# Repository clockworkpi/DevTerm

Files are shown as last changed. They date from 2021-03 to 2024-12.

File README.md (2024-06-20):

# DevTerm

## DevTerm OS Images

### A04
* http://dl.clockworkpi.com/DevTerm_A04_v0.2h.img.bz2 (32bit)  
md5sum acec1d02a37bfbffc9ed025fd718948e

### A06
* http://dl.clockworkpi.com/DevTerm_A06_v0.2h.img.bz2   
md5sum 26f52bfde573479960d8696f407d19b9  

### CM3
* http://dl.clockworkpi.com/DevTerm_CM3_v0.1a.img.bz2 (32bit)  
md5sum bef6c111863f8d2e6ef1cb23be354152  

### CM4
* http://dl.clockworkpi.com/DevTerm_CM4_v0.2b_64bit.img.7z    
md5sum 8b2fdebe254dfa1f5f245cebb85b1e84

* http://dl.clockworkpi.com/DevTerm_CM4_v0.1.img.bz2 (32bit)    
md5sum 7938ed1cdda98ba6f28049a819c12dc1  

* http://dl.clockworkpi.com/DevTerm_CM4_v0.3e_xfce_64bit.img.7z (based on [RPI-lite](https://downloads.raspberrypi.org/raspios_lite_armhf/images/raspios_lite_armhf-2023-05-03/2023-05-03-raspios-bullseye-armhf-lite.img.xz) with xfce)  
md5sum ab081eabf24ae501dc3f40a9126b7e5a  
 This version is optimized for immersive writing and comes pre-installed with [Obsidian](https://obsidian.md/).  

### R01
* http://dl.clockworkpi.com/DevTerm_R01_v0.2a.img.bz2   
md5sum 49aa472a6e4d81a48e0a1a26436f02c2

## Images mirror

* Community-driven download mirror: [http://dl.clockworkpi.io](http://dl.clockworkpi.io)

After downloading the files, you will need to extract or decompress them. Please keep in mind that MacOS 11.6 or a higher version is required to extract 7z files.  
  
To flash the OS image, you can use the following tools:  
  
- For Windows and macOS users, [Etcher](https://etcher.balena.io/) can be used to flash the image.  
- Linux users can employ the "dd" command to flash the image.  

To learn how to create an image, please refer to our [Wiki](https://github.com/clockworkpi/DevTerm/wiki).

## DevTerm Keyboard Firmware
DevTerm keyboard firmware flash program available. You can download it from this link: [DevTerm Keyboard Firmware Flash Program](https://github.com/clockworkpi/DevTerm/raw/main/Bin/devterm_keyboard_flash.tar.gz).

Here's how you can flash the firmware on DevTerm(A06 or CM4) or a PC running Ubuntu 22.04:

1. Download the devterm_keyboard_flash.tar.gz file.
2. Extract the contents of the archive: `tar zxvf devterm_keyboard_flash.tar.gz`.
3. Install the required package using the following command: `sudo apt install -y dfu-util`.
4. Navigate to the extracted directory: `cd devterm_keyboard_flash`.
5. Execute the flash script with root privileges: `sudo ./flash.sh`.
6. If everything goes well, you will see a progress bar indicating the flashing process.
7. If any issues occur or the keyboard loses control (which is unlikely), simply reboot DevTerm to resolve it.
8. Rest assured that this flash program will not brick your keyboard.

## Thermal Printer Testing Commands

* How to print "Hello World".  
`echo "hello world\n\n\n\n\n\n\n\n\n\n" > /tmp/DEVTERM_PRINTER_IN`

* How to print a self test page.  
`echo -en "\x12\x54" >  /tmp/DEVTERM_PRINTER_IN`

* How to print a text file.  
`curl -L https://github.com/clockworkpi/DevTerm/raw/main/README.md | tee >  /tmp/DEVTERM_PRINTER_IN`  

* [Learning more...](https://github.com/clockworkpi/DevTerm/tree/main/Code/thermal_printer)

## Assembly guidelines

* [Assembly guidelines](https://github.com/clockworkpi/DevTerm/blob/main/Clockwork_DevTerm_Assembly_Guidelines.pdf)  

## Schematic

* [DevTerm A06 core mainboard v3.14 schematic](https://github.com/clockworkpi/DevTerm/blob/main/Schematics/clockwork_DevTerm_A06_Core_for_Mainboard_V3.14_Schematic.pdf)
* [DevTerm R01 core mainboard v3.14 schematic](https://github.com/clockworkpi/DevTerm/blob/main/Schematics/clockwork_DevTerm_R01_Core_for_Mainboard_V3.14_Schematic.pdf)
* [Mainboard v3.14 schematic](https://github.com/clockworkpi/DevTerm/blob/main/Schematics/clockwork_Mainboard_V3.14_Schematic.pdf)
* [Mainboard v3.14-V5 schematic](https://github.com/clockworkpi/DevTerm/blob/main/Schematics/clockwork_Mainboard_V3.14_V5_Schematic.pdf)
* [DevTerm keyboard schematic](https://github.com/clockworkpi/DevTerm/blob/main/Schematics/clockwork_DevTerm_Keyboard_Schematic.pdf)
* [DevTerm keyboard trackball schematic](https://github.com/clockworkpi/DevTerm/blob/main/Schematics/clockwork_DevTerm_Keyboard_Trackball_Schematic.pdf)
* [DevTerm Ext schematic](https://github.com/clockworkpi/DevTerm/blob/main/Schematics/clockwork_DevTerm_Ext_Schematic.pdf)
* [DevTerm battery schematic](https://github.com/clockworkpi/DevTerm/blob/main/Schematics/clockwork_DevTerm_Battery_Schematic.pdf) 
* [CM4 adapter schematic](https://github.com/clockworkpi/DevTerm/blob/main/clockwork_Adapter_CM4_Schematic.pdf)
* [Learning more...](Schematics/)

## Gearbox 
### A04

Gearbox is a script tool used to adjust the A04 CPU frequency.  
you can get it by running 
```
sudo apt update 
sudo apt install -y devterm-gearbox-a04
```
you can run `devterm-a04-gearbox` to see the current core status.

```

Current Status:
+-----------------------------------+
|            Cortex-A53             |
+--------+--------+--------+--------+
| CPU 0  | CPU 1  | CPU 2  | CPU 3  |
+--------+--------+--------+--------+
|1320Mhz |1320Mhz |  OFF   |  OFF   |
+--------+--------+--------+--------+
CPU Governor: ondemand

```

Run `sudo devterm-a04-gearbox -s [GEAR]` to set gear, GEAR would be 1,2,3,4,5

There are 5 gears in gearbox

```
               1 for simple console tasks with long battery life.
               2 for simple writing tasks with long battery life.
               3 for most 2D games and emulators.
               4 for playing videos and 3D games,browsing websites.
               5 for performance-first tasks.
```

### A06 
Gearbox is a script tool used to adjust the big.LITTLE architecture of the A06 chip.  
you can get it by running 
```
sudo apt update 
sudo apt install -y devterm-gearbox-a06
```

In latest os image of A06, default Gearbox is set to use 4 LITTLE core with 816Mhz,GPU at 400Mhz

you can run `a06-gearbox` to see the current core status.

```
Current Status:
+-----------------------------------+-----------------+-----------+
|            Cortex-A53             |   Cortex-A72    | Mali-T860 |
+--------+--------+--------+--------+--------+--------+-----------+
| CPU 0  | CPU 1  | CPU 2  | CPU 3  | CPU 4  | CPU 5  |    GPU    |
+--------+--------+--------+--------+--------+--------+-----------+
| 816Mhz | 816Mhz | 816Mhz | 816Mhz |  OFF   |  OFF   |   400MHz  |
+--------+--------+--------+--------+--------+--------+-----------+
CPU Governor: schedutil    GPU Governor: simple_ondemand
```

Run `sudo a06-gearbox -s [GEAR]` to set gear,GEAR would be 1,2,3,4,5,6

There are 6 gears in gearbox

```
               1 for simple writing tasks with long battery life.
               2 for browsing most websites with long battery life.
               3 for most 2D games and emulators.
               4 for playing videos and 3D games.
               5 for performance-first tasks.
               6 for max performance, max power (usage).

```

## Community
Please visit our [Github Wiki](https://github.com/clockworkpi/DevTerm/wiki) and https://forum.clockworkpi.com for more information.

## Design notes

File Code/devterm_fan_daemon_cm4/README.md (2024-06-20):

# Fan control daemon for devterm cm4(rpi os)
 
## Install

**Devterm is pre-installed this package, so devterm cm4 users do not need to repeat the installation steps**

```
wget -O - https://raw.githubusercontent.com/clockworkpi/apt/main/debian/KEY.gpg | sudo apt-key add -
echo "deb https://raw.githubusercontent.com/clockworkpi/apt/main/debian/ stable main" | sudo tee -a /etc/apt/sources.list.d/clockworkpi.list

sudo apt update && apt install -y devterm-fan-temp-daemon-cm4
```

## Change the threshold temperature

Edit `/usr/local/bin/temp_fan_daemon.py`

line starts with `MAX_TEMP=80`

For devterm cm4(rpi os) the  recommended MAX_TEMP is in range 60-80 

then restart systemd service to take effect

`sudo systemctl restart devterm-fan-temp-daemon`

## How to control the fan from GPIO

``` start the fan
sudo gpio mode 17 out
sudo gpio write 17 1
```

```stop the fan
sudo gpio mode 17 out
sudo gpio write 17 0
```

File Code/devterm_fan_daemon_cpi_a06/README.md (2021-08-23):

# Fan control daemon for devterm A06()
 
## Install

**devterm is pre-installed this package, so devterm A06 users do not need to repeat the installation steps**

```
wget -O - https://raw.githubusercontent.com/clockworkpi/apt/main/debian/KEY.gpg | sudo apt-key add -
echo "deb https://raw.githubusercontent.com/clockworkpi/apt/main/debian/ stable main" | sudo tee -a /etc/apt/sources.list.d/clockworkpi.list

sudo apt update && apt install -y devterm-fan-daemon-cpi-a06
```

## Change the threshold temperature

Edit `/usr/local/bin/temp_fan_daemon_a06.py`

line starts with `MAX_TEMP=70000`

change the value of MAX_TEMP to be your target temperature value multiplied by 1000,eg 70000 for 70 degree,80000 for 80 degree  

for A06 recommended reference temperature range 70-80 

then restart systemd service to take effect

`sudo systemctl restart devterm-fan-temp-daemon-a06`

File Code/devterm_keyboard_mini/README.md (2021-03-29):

Arduino 1.8.13

http://dan.drown.org/stm32duino/package_STM32duino_index.json

STM32F1xx/GD32F1xx boards 
by stm32duino version 2021.2.22

  GENERIC STM32F103R series

  gd32f1_generic_boot20_pc13.bin
  generic_boot20_pc13.bin

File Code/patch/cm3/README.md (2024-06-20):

# How to compile devterm cm3 kernel

## Clone kernel source code 
```
git clone https://github.com/raspberrypi/linux.git  
cd linux
git checkout remotes/origin/rpi-4.19.y
```

## Get cross compile tools
```
git clone https://github.com/raspberrypi/tools.git
```

## Compiling process
```
#must use the rpi arm-bcm2708 cross compiler tools

cd linux
git apply devterm-4.19_v0.11.patch #get patch from https://github.com/clockworkpi/DevTerm/tree/main/Code/patch/cm3

export PATH=/data/github/raspberrypi/tools/arm-bcm2708/arm-linux-gnueabihf/bin/:$PATH ## change the arm-bcm2708 tools location for yourself

KERNEL=kernel7l make ARCH=arm CROSS_COMPILE=arm-linux-gnueabihf- bcm2709_defconfig
KERNEL=kernel7l make ARCH=arm CROSS_COMPILE=arm-linux-gnueabihf- -j3
INSTALL_MOD_PATH=./modules 
rm -rf $INSTALL_MOD_PATH
make modules_install

rm modules/lib/modules/*/build
rm modules/lib/modules/*/source

```

## /boot/config.txt

In config.txt,I renamed kernel7.img to devterm-kernel7.img

```
ignore_lcd=1
dtoverlay=vc4-kms-v3d,audio=0,cma-384
dtoverlay=devterm-pmu
dtoverlay=devterm-panel
dtoverlay=devterm-wifi
dtoverlay=devterm-bt
dtoverlay=devterm-misc
gpio=5=op,dh
gpio=9=op,dh
gpio=10=ip,np
gpio=11=op,dh

enable_uart=1
dtparam=spi=on
dtoverlay=spi-gpio35-39

dtparam=audio=on
kernel=devterm-kernel7.img
```

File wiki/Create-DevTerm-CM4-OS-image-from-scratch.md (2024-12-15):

## Intro
The image based on raspberry pi os  
for raspberry pi cm4 with devterm cm4 adapter  
and it is better to run a Ubuntu 21.04 in a VirtualBox to do all the jobs  
The entire operation requires a certain experience in linux  
be careful  

## Start a chroot env
```bash
wget https://downloads.raspberrypi.org/raspios_full_armhf/images/raspios_full_armhf-2021-05-28/2021-05-07-raspios-buster-armhf-full.zip

unzip 2021-05-07-raspios-buster-armhf-full.zip

sudo losetup --show -f -P 2021-05-07-raspios-buster-armhf-full.img #assume loop0
sudo mount /dev/loop0p2 /mnt/p2
sudo mount /dev/loop0p1 /mnt/p2/boot

cd /mnt/p2
sudo mount --bind /dev dev/
sudo mount --bind /sys sys/
sudo mount --bind /proc proc/
sudo mount --bind /dev/pts dev/pts
#sudo mv etc/ld.so.preload etc/ld_so_preload
sudo chroot .
```

## Inside chroot 
```bash
curl https://raw.githubusercontent.com/clockworkpi/apt/main/debian/KEY.gpg | sudo tee /etc/apt/trusted.gpg.d/clockworkpi.asc

echo "deb https://raw.githubusercontent.com/clockworkpi/apt/main/debian/ stable main" | sudo tee -a /etc/apt/sources.list.d/clockworkpi.list

sudo apt update && sudo apt install devterm-thermal-printer-cm4 devterm-fan-temp-daemon-cm4 devterm-kernel-cm4-rpi devterm-audio-patch devterm-wiringpi-cm4-cpi -y

sudo apt install -y devterm-thermal-printer-cups
```
**Config xrandr**
```
sudo bash -c 'cat << EOF > /etc/X11/Xsession.d/100custom_xrandr
xrandr --output DSI-1 --rotate right
EOF'
```
**config lightdm** 

`/etc/lightdm/lightdm.conf`

`greeter-setup-script=/etc/lightdm/setup.sh`
```
sudo bash -c 'cat <<EOF >/etc/lightdm/setup.sh
#!/bin/bash
xrandr --output DSI-1 --rotate right
exit 0
EOF'
```
`sudo chmod +x /etc/lightdm/setup.sh`

**Modify /etc/dphys-swapfile**
```
CONF_SWAPSIZE=512
```

**Change the default wallpaper**   
The following files changed 

* /etc/xdg/pcmanfm/LXDE-pi/desktop-items-0.conf 
* /etc/xdg/pcmanfm/LXDE-pi/desktop-items-1.conf 
* /etc/lightdm/pi-greeter.conf 
* /home/pi/.config/pcmanfm/LXDE-pi/desktop-items-0.conf 

Delete wallpaper address `temple.jpg`,change the `desktop_bg` color to `#202020`   
change `/etc/hostname` to clockworkpi  
in `/boot/cmdline.txt` ,add `fbcon=rotate:1`, remove `quiet` 

**Screen rotation**  
change 
```
/etc/skel/.config/monitors.xml 
/home/{pi,rpi-first-boot-wizard}/.config/monitors.xml 
```
to be like
```xml
<monitors version="2">
  <configuration>
    <logicalmonitor>
      <x>0</x>
      <y>0</y>
      <primary>yes</primary>
      <monitor>
        <monitorspec>
          <connector>DSI-1</connector>
          <vendor>unknown</vendor>
          <product>unknown</product>
          <serial>unknown</serial>
        </monitorspec>
        <mode>
          <width>480</width>
          <height>1280</height>
          <rate>60.000</rate>
        </mode>
      </monitor>
      <transform>
        <rotation>right</rotation>
      </transform>
    </logicalmonitor>
  </configuration>
</monitors>
```
for uConsole, replace **480 to 720** in above **monitors.xml**

### console rotation
/boot/cmdline.txt   add **fbcon=rotate:1** in the end of 
```
console=.........  fbcon=rotate:1

```

### Now quit the chroot env
```bash
exit
#sudo mv etc/ld_so_preload etc/ld.so.preload

sudo umount /mnt/p2/dev/pts
sudo umount /mnt/p2/dev
sudo umount /mnt/p2/proc
sudo umount /mnt/p2/sys
##clear bash 
sudo rm -rf root/.bash_history
#sudo rm usr/bin/qemu-arm-static

cd -
sudo umount /mnt/p2/boot
sudo umount /mnt/p2
sudo losetup -D /dev/loop0 #assume loop0
```

### Flash the image to SD card 
* Linux
`sudo dd if=2021-05-07-raspios-buster-armhf-full.img of=/dev/sdX bs=8M status=progress`

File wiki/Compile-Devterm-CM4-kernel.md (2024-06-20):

# System
ubuntu 22.04 gcc8.4.0
```
sudo apt install gcc-8 gcc-8-aarch64-linux-gnu gcc-8-arm-linux-gnueabihf
```

# Download patch
```
git clone https://github.com/clockworkpi/DevTerm.git
```

# Download kernel and patch it
```
git clone https://github.com/raspberrypi/linux
cd linux
git checkout 3a33f11c48572b9dd0fecac164b3990fc9234da8
cp ~/DevTerm/Code/patch/cm4/cm4_kernel_0704.patch .
git apply cm4_kernel_0704.patch

#Strongly recommend to use gcc 8.4.0 as the cross compiler
KERNEL=kernel7l make ARCH=arm CROSS_COMPILE=arm-linux-gnueabihf- bcm2711_defconfig
KERNEL=kernel7l make ARCH=arm CROSS_COMPILE=arm-linux-gnueabihf- -j1
INSTALL_MOD_PATH=./modules make modules_install
rm modules/lib/modules/*/build
rm modules/lib/modules/*/source

mkdir output
mkdir output/boot
mkdir output/lib/modules -p
mkdir output/boot/overlays

cp -rf modules/lib/modules/5.10.17-v7l+ output/lib/modules/
cp arch/arm/boot/dts/overlays/*.dtbo output/boot/overlays/
cp arch/arm/boot/dts/bcm2711-rpi-cm4.dtb output/boot/
cp arch/arm/boot/zImage output/boot/kernel7l.img

```

output is the folder contains all kernel stuff  

# config.txt
```
disable_overscan=1
dtparam=audio=on
[pi4]
dtoverlay=vc4-fkms-v3d
max_framebuffers=2

[all]
dtoverlay=dwc2,dr_mode=host
dtoverlay=vc4-kms-v3d-pi4,cma-384
dtoverlay=devterm-pmu
dtoverlay=devterm-panel
dtoverlay=devterm-misc
dtoverlay=audremap,pins_12_13

dtparam=spi=on
gpio=10=ip,np
```

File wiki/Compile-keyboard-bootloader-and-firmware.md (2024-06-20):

# Build bin

```
git clone https://github.com/rogerclarkmelbourne/STM32duino-bootloader

cd STM32duino-bootloader

make generic-pc13

```
this will produce `bootloader_only_binaries/generic_boot20_pc13.bin`  
## Convert bootloader to hex format
using `srec_cat` to convert   
windows: http://srecord.sourceforge.net/  
linux: sudo apt install srecord  

```
srec_cat bootloader_only_binaries/generic_boot20_pc13.bin -Binary -offset 0x08000000 -output bootloader_only_binaries/generic_boot20_pc13.hex -Intel
```

## Next is to use stm32Cube to flash the bootloader
* Download the stm32cube programmer  
   [stm32cube programmer](https://www.st.com/en/development-tools/stm32cubeprog.html)

* Put 1 ON in the back of keyboard
* Connect keyboard with a usb-serial convert by fpc, in order of [IO MAP](https://github.com/clockworkpi/DevTerm/wiki/Keyboard-with-FPC-60pin-0.5mm)
* Click connect on STM32cube programmer
* flash it





# Flash Arudino 
## Arduino IDE
* add stm32duino pacakage index in **Preference panel** : http://dan.drown.org/stm32duino/package_STM32duino_index.json as **Additional Boards Manager URLs:** and install STM32F1xx/GD32F1xx boards



* verbose all outputs:  


* Select upload method ,board type is **Generic STM32F103R series **  


* Set cpu mhz to 48Mhz  


* Put 1 OFF in the back of keyboard
* User arduino IDE to open [devterm_keyboard.ino](https://github.com/clockworkpi/DevTerm/blob/main/Code/devterm_keyboard/devterm_keyboard.ino)
* flash it 


# CN version  
https://shimo.im/docs/Tc8RVQWdjvXtwhYv/ 《GD32f103rgt6/CKSF103R* 与stm32duino bootloader》

custom keyboard:

https://forum.clockworkpi.com/t/keyboard-stuck-in-bootloader-mode/8830/11

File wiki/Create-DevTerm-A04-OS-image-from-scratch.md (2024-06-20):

**This wiki maybe outdated since armbian build system is always updating , so don't panic**

# Generate the prototype os image
```
cd ~
git clone https://github.com/armbian/build.git
git clone https://github.com/clockworkpi/DevTerm.git

cd build

git reset --hard 5fa022603c0948cc59688ba782b3711f980a0be3

cp -rf ~/DevTerm/Code/patch/armbian_build_a04/userpatches/* userpatches/
cp -rf ~/DevTerm/Code/patch/armbian_build_a04/config/boards/* config/boards/
cp -rf ~/DevTerm/Code/patch/armbian_build_a04/config/kernel/*  config/kernel/

#Then exec ./compile.sh under armbian build
cd ~/build && ./compile.sh 
```
after image done  
uncompress the  
`linux-dtb-current-sunxi64_21.11.0-trunk_arm64.deb`  
`linux-image-current-sunxi64_21.11.0-trunk_arm64.deb`  
 
and then combine all files ,all the postinst, preinst,prerm,postrm  
to be one `devterm-kernel-current-cpi-a04.deb`    
the reason is if not doing this , `apt-get upgrade` will replace the linux-dto,linux-image* in future, which will cause boot failed  
so to keep a04 linux kernel in safe , I made devterm-kernel-current-cpi-a04     

#  Prepare to chroot into the image 
```
sudo apt install -y qemu-user-static  
sudo losetup -f # find the avaiable loop device number,eg:loop11
sudo losetup -P /dev/loop11 ~/build/output/images/Armbian_21.11.0-trunk_Clockworkpi-a04_hirsute_current_5.10.75_xfce_desktop.img 
sudo mount /dev/loop11p1 /mnt/p1/

cd /mnt/p1

sudo mount --bind /dev dev/
sudo mount --bind /sys sys/
sudo mount --bind /proc proc/
sudo mount --bind /dev/pts dev/pts

sudo chroot .
```
## Inside chroot
(inside)
### import clockworpi apt 
```
curl https://raw.githubusercontent.com/clockworkpi/apt/main/debian/KEY.gpg | tee /etc/apt/trusted.gpg.d/clockworkpi.asc
echo "deb https://raw.githubusercontent.com/clockworkpi/apt/main/debian/ stable main" | tee  /etc/apt/sources.list.d/clockworkpi.list  
```

### Preset cpi username and password
```
sh /etc/profile.d/armbian-check-first-login.sh 
```
### Install kernel
```
sudo apt update
sudo apt install -y devterm-kernel-current-cpi-a04
apt install -y xfce4-power-manager
touch /home/cpi/.first_start
chown cpi:cpi /home/cpi/.first_start
```
 
### Allow sudo cpi without password prompt

```
echo -e  "cpi\tALL=(ALL:ALL) NOPASSWD:ALL" | sudo tee  /etc/sudoers.d/cpi

```
### Config xrandr 
```
sudo bash -c 'cat << EOF > /etc/X11/Xsession.d/100custom_xrandr
xrandr --output DSI-1 --rotate right
xrandr --output None-1 --rotate right
EOF'
```

### Config lightdm
#### autologin 

```
sudo bash -c 'cat <<EOF > /etc/lightdm/lightdm.conf.d/12-autologin.conf 
[Seat:*]
autologin-user=cpi
autologin-user-timeout=0
EOF'
```

```
sudo bash -c 'cat <<EOF > /etc/lightdm/lightdm.conf.d/13-rotate-dsi.conf
[Seat:*]
greeter-setup-script=/etc/lightdm/setup.sh
EOF'
```
```
sudo bash -c 'cat <<EOF >/etc/lightdm/setup.sh
#!/bin/bash
xrandr --output DSI-1 --rotate right
xrandr --output None-1 --rotate right
exit 0
EOF'

sudo chmod +x /etc/lightdm/setup.sh
```

#### config lightdm background
```
sudo sed  -i '/background/c\background = #202020' /etc/lightdm/slick-greeter.conf

```

### Disable app crash report dialog
```
sudo sed -i '/enabled=1/c\enabled=0'  /etc/default/apport
```

### Hide suspend button 
cd /home/cpi/.config/xfce4/xfconf/xfce-perchannel-xml
```
sudo sed -i 's/\(name\=\".*ShowSuspend.*\"\s\)value="\(true\|false\)"/\1value=\"false\"/gi' xfce4-session.xml

sudo sed -i 's/\(type\=\".*string.*\"\s\)value="\(+suspend\)"/\1value=\"-suspend\"/gi' xfce4-panel.xml

```

### Add framebuffer console rotate /boot/armbianEnv.txt
```
extraargs=fbcon=rotate:1
```

### Change ssh login banner
In `/etc/update-motd.d/10-armbian-header`
```
TERM=linux toilet -f standard -F metal $(echo $BOARD_NAME | sed 's/Orange Pi/OPi/' | sed 's/NanoPi/NPi/' | sed 's/Banana Pi/BPi/' | sed 's/Clockworkpi A04/Clockworkpi/')
```

### Install devterm packages
```
sudo apt update
sudo apt install -y devterm-wiringpi-cpi-a04 devterm-thermal-printer devterm-thermal-printer-cups  devterm-first-start-a04 devterm-fan-daemon-cpi-a04 devterm-audio-patch

```
### Disable sshd
```
sudo touch /etc/ssh/sshd_not_to_be_run

```
### Install ibus input method for CJK

`sudo apt install ibus ibus-pinyin ibus-gtk ibus-gtk3 -y`
```
cat <<EOF >/home/cpi/.config/autostart/ibus.desktop
[Desktop Entry]
Exec=ibus-daemon -drxR
GenericName=IBus
Name[zh_CN]=IBus
Name=IBus
Name[en_US]=IBus
StartupNotify=true
Terminal=false
Type=Application
EOF
```

```
sudo bash -c 'cat <<EOF >/etc/profile.d/ibus.sh
#!/bin/bash

export XIM_PROGRAM=ibus
export XIM=ibus
export XMODIFIERS=@im=ibus
export GTK_IM_MODULE=ibus
export QT_IM_MODULE=ibus
EOF'
```
### GDM3 
due to the panfrost screen flashing issue with lightdm,use gdm3 instead of lightdm  
` sudo apt install gdm3`
```
sudo bash -c 'cat <<EOF > /usr/share/gdm/greeter/autostart/01_rotate.desktop
[Desktop Entry]
Version=1.0
Type=Application
Name=Rotate Screen
Exec=/etc/lightdm/setup.sh
Terminal=false
NoDisplay=true
EOF'
```
#### gdm3 background and hide poweroff,suspend
In `/etc/gdm3/greeter.dconf-defaults `
```
...
[org/gnome/desktop/background]
picture-options='none'
primary-color='#222222'
...

[org/gnome/login-screen]
disable-restart-buttons=true
```
#### config gdm3 autologin 
/etc/gdm3/custom.conf  

```
[daemon]
...
AutomaticLoginEnable = true
AutomaticLogin = cpi
```

## libreoffice fix for panfrost issue
` sudo apt install libreoffice-gtk3 `

# Exit from chroot
```
exit
(out)
sudo umount /mnt/p1/dev/pts
sudo umount /mnt/p1/dev
sudo umount /mnt/p1/proc
sudo umount /mnt/p1/sys
##clear bash 
sudo rm -rf root/.bash_history
cd -
sudo umount /mnt/p1 
sudo losetup -D /dev/loop11
```

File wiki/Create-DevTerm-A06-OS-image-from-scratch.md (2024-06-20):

# Intro
DevTerm A06 os image based on Armbian with current kernel branch, XFCE desktop   
and it is better to run a Ubuntu 21.04 in a VirtualBox with a good bandwidth network to do all the jobs   
If the condition of the network is not so well, 
the Armbian build process will fail on some packages downloading  or mirrors connecting  

The entire operation requires a certain experience in linux  
be careful  

**This wiki maybe outdated since armbian build system is always updating , so don't panic**

# Build armbian image for A06
```
cd ~
git clone https://github.com/armbian/build.git
git clone https://github.com/clockworkpi/DevTerm.git

cd build
git reset --hard 43d179914ae9e1ebb5d72315d9f9f68f5fb3e330

mkdir -p userpatches/kernel/rockchip64-current/
mkdir -p userpatches/u-boot/u-boot-rockchip64-mainline/

git apply ~/DevTerm/Code/patch/armbian_build_a06/patch/armbian.patch
cp ~/DevTerm/Code/patch/armbian_build_a06/patch/kernel*.patch userpatches/kernel/rockchip64-current/
cp ~/DevTerm/Code/patch/armbian_build_a06/patch/uboot*.patch userpatches/u-boot/u-boot-rockchip64-mainline/
cp -f ~/DevTerm/Code/patch/armbian_build_a06/patch/lib.config userpatches/
cp ~/DevTerm/Code/patch/armbian_build_a06/patch/clockworkpi-a06.conf config/boards/

#Then exec ./compile.sh under armbian build
cd ~/build && sudo ./compile.sh  BOARD=clockworkpi-a06 BRANCH=current BUILD_MINIMAL=no BUILD_DESKTOP=no KERNEL_ONLY=yes KERNEL_CONFIGURE=no 
``` 

after image done  
uncompress the  
`linux-dtb-current-rockchip64_21.08.0-trunk_arm64.deb`  
`linux-image-current-rockchip64_21.08.0-trunk_arm64.deb`  

and then combine all files ,all the postinst, preinst,prerm,postrm  
to be one `devterm-kernel-current-cpi-a06.deb`    
the reason is if not doing this , `apt-get upgrade` will replace the linux-dto,linux-image* in future, which will cause boot failed  
so to keep a06 linux kernel in safe , I made devterm-kernel-current-cpi-a06    

# Chroot image
```
sudo losetup -P /dev/loop0  Armbian_21.08.0-trunk_Clockworkpi-a06_focal_current_5.10.55_xfce_desktop.img
sudo mount /dev/loop0p1 /mnt/p1

cd /mnt/p1
sudo mount --bind /dev dev/
sudo mount --bind /sys sys/
sudo mount --bind /proc proc/
sudo mount --bind /dev/pts dev/pts
sudo mv etc/ld.so.preload etc/ld_so_preload
sudo chroot .
```

## Inside Chroot
### Run password wizard
```
sh /etc/profile.d/armbian-check-first-login.sh
```
set **root** password,create default user **cpi** with password **cpi**  
```
touch /home/cpi/.first_start
chown cpi:cpi /home/cpi/.first_start
```
### Install devterm software  
```
sudo apt update
sudo apt install curl wget -y

curl https://raw.githubusercontent.com/clockworkpi/apt/main/debian/KEY.gpg | sudo tee /etc/apt/trusted.gpg.d/clockworkpi.asc
echo "deb https://raw.githubusercontent.com/clockworkpi/apt/main/debian/ stable main" | sudo tee  /etc/apt/sources.list.d/clockworkpi.list  

sudo apt update
sudo apt remove linux-image*
sudo apt install devterm-kernel-current-cpi-a06 devterm-fan-daemon-cpi-a06 devterm-thermal-printer devterm-thermal-printer-cups devterm-wiringpi-cpi  devterm-first-start-a06 devterm-audio-patch
```

### /boot/ArmbianEnv.txt
```
bootlogo=false
extraargs= fbcon=rotate:1
...
```

### autologin
```
sudo bash -c 'cat <<EOF > /etc/lightdm/lightdm.conf.d/12-autologin.conf

[Seat:*]
autologin-user=cpi
autologin-user-timeout=0
EOF'
```

### config lightdm
```
sudo bash -c 'cat << EOF > /etc/lightdm/lightdm.conf.d/13-rotate-dsi.conf
[Seat:*]
greeter-setup-script=/etc/lightdm/setup.sh
EOF'

sudo bash -c 'cat <<EOF >/etc/lightdm/setup.sh
#!/bin/bash
xrandr --output DSI-1 --rotate right
exit 0
EOF'

sudo chmod +x /etc/lightdm/setup.sh
```

### config xrandr 
```
sudo bash -c 'cat << EOF > /etc/X11/Xsession.d/100custom_xrandr
xrandr --output DSI-1 --rotate right
EOF'
```

### additional software
```
sudo apt remove celluloid mpv 
sudo apt install -y arandr chromium-browser vlc cpupower-gui xfce4-power-manager
```
### /etc/default/apport 
`enable=0`

### ssh banner fix 
/etc/update-motd.d/10-armbian-header
```
.... sed 's/Banana Pi/BPi/' | sed 's/Clockworkpi A06/Clockworkpi/')

```
### Disable Display power management in xfce4 power manager 
display power management must be disabled ,once the display turn off, you need to reboot to get it back
~/.config/xfce4/xfconf/xfce-perchannel-xml/xfce4-power-manager.xml  

```
<?xml version="1.0" encoding="UTF-8"?>

<channel name="xfce4-power-manager" version="1.0">
  <property name="xfce4-power-manager" type="empty">
    <property name="power-button-action" type="empty"/>
    <property name="brightness-switch-restore-on-exit" type="int" value="0"/>
    <property name="brightness-switch" type="int" value="0"/>
    <property name="show-tray-icon" type="int" value="1"/>
    <property name="lid-action-on-battery" type="uint" value="1"/>
    <property name="logind-handle-lid-switch" type="bool" value="false"/>
    <property name="lid-action-on-ac" type="uint" value="0"/>
    <property name="inactivity-sleep-mode-on-battery" type="uint" value="1"/>
    <property name="sleep-button-action" type="uint" value="1"/>
    <property name="hibernate-button-action" type="uint" value="1"/>
    <property name="lock-screen-suspend-hibernate" type="bool" value="false"/>
    <property name="critical-power-action" type="uint" value="4"/>
    <property name="critical-power-level" type="uint" value="5"/>
    <property name="dpms-enabled" type="bool" value="false"/>
    <property name="blank-on-ac" type="int" value="0"/>
    <property name="brightness-on-battery" type="uint" value="120"/>
    <property name="blank-on-battery" type="int" value="0"/>
    <property name="brightness-on-ac" type="uint" value="120"/>
    <property name="brightness-level-on-battery" type="uint" value="40"/>
    <property name="brightness-level-on-ac" type="uint" value="42"/>
  </property>
</channel>
```
### Default wallpaper 
```
/usr/share/backgrounds/xfce/xfce-verticals.png
```  
# Quit Chroot
```
exit
sudo mv etc/ld_so_preload etc/ld.so.preload

sudo umount /mnt/p1/dev/pts
sudo umount /mnt/p1/dev
sudo umount /mnt/p1/proc
sudo umount /mnt/p1/sys
##clear bash 
sudo rm -rf root/.bash_history
sudo rm usr/bin/qemu-arm-static

cd -
sudo umount /mnt/p1
```

umount may failed at /mnt/p1/dev  
just use `ps aux | grep cupsd` to see if there a process named like `/usr/bin/qemu-aarch64-static /usr/sbin/cupsd -C /etc/cups/cupsd.conf -s /etc/cups/cups-files.conf`  

find the pid ,use `sudo kill -9 ${pid}` with that pid  
then umount again   

# Flash the image to SD card
* Linux  
`sudo dd if=Armbian_21.08.0-trunk_Clockworkpi-a06_focal_current_5.10.55_xfce_desktop.img  of=/dev/sdX bs=8M status=progress`

# Ubuntu 2104 Hirsute went offline 
fix:
https://forum.clockworkpi.com/t/hirsute-went-offline-late-july-2022-how-to-manage/8770/3

new os image: 26f52bfde573479960d8696f407d19b9 http://dl.clockworkpi.com/DevTerm_A06_v0.2h.img.bz2   
switched to ubuntu jammy ,LTS up to 2037  

# 2023 06 30 new kernel patch:
https://github.com/clockworkpi/uConsole/tree/master/Code/patch/a06/20230630

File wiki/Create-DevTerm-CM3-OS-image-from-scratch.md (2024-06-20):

## Intro
The image based on raspberry pi os   
and it is better to run a Ubuntu 21.04 in a VirtualBox to do all the jobs  
The entire operation requires a certain experience in linux  
be careful  

## Start a chroot env
```
wget https://downloads.raspberrypi.org/raspios_full_armhf/images/raspios_full_armhf-2021-05-28/2021-05-07-raspios-buster-armhf-full.zip

unzip 2021-05-07-raspios-buster-armhf-full.zip

sudo losetup --show -f -P 2021-05-07-raspios-buster-armhf-full.img #assume loop0
sudo mount /dev/loop0p2 /mnt/p2
sudo mount /dev/loop0p1 /mnt/p2/boot

cd /mnt/p2
sudo mount --bind /dev dev/
sudo mount --bind /sys sys/
sudo mount --bind /proc proc/
sudo mount --bind /dev/pts dev/pts
#sudo mv etc/ld.so.preload etc/ld_so_preload
sudo chroot .
```

## Inside chroot 
```
curl https://raw.githubusercontent.com/clockworkpi/apt/main/debian/KEY.gpg | sudo tee /etc/apt/trusted.gpg.d/clockworkpi.asc

echo "deb https://raw.githubusercontent.com/clockworkpi/apt/main/debian/ stable main" | sudo tee -a /etc/apt/sources.list.d/clockworkpi.list

sudo apt update && sudo apt install devterm-thermal-printer devterm-keyboard-firmware devterm-fan-temp-daemon-rpi devterm-thermal-printer-cups devterm-kernel-rpi devterm-audio-patch -y
```
**Config xrandr**
```
sudo bash -c 'cat << EOF > etc/X11/Xsession.d/100custom_xrandr
xrandr --output DSI-1 --rotate right
EOF'
```
**config lightdm** 

`/etc/lightdm/lightdm.conf`

`greeter-setup-script=/etc/lightdm/setup.sh`
```
sudo bash -c 'cat <<EOF >/etc/lightdm/setup.sh
#!/bin/bash
xrandr --output DSI-1 --rotate right
exit 0
EOF'
```
`sudo chmod +x /etc/lightdm/setup.sh`

**Modify /etc/dphys-swapfile**
```
CONF_SWAPSIZE=512
```

**Change the default wallpaper**   
The following files changed 

* /etc/xdg/pcmanfm/LXDE-pi/desktop-items-0.conf 
* /etc/xdg/pcmanfm/LXDE-pi/desktop-items-1.conf 
* /etc/lightdm/pi-greeter.conf 
* /home/pi/.config/pcmanfm/LXDE-pi/desktop-items-0.conf 

Delete wallpaper address `temple.jpg`,change the `desktop_bg` color to `#202020`   
change `/etc/hostname` to clockworkpi  
in `/boot/cmdline.txt` ,add `fbcon=rotate:1`, remove `quiet` 

### Now quit the chroot env
```
exit
#sudo mv etc/ld_so_preload etc/ld.so.preload

sudo umount /mnt/p2/dev/pts
sudo umount /mnt/p2/dev
sudo umount /mnt/p2/proc
sudo umount /mnt/p2/sys
##clear bash 
sudo rm -rf root/.bash_history
#sudo rm usr/bin/qemu-arm-static

cd -
sudo umount /mnt/p2/boot
sudo umount /mnt/p2
sudo losetup -D /dev/loop0 #assume loop0
```

### Flash the image to SD card 
* Linux
`sudo dd if=2021-05-07-raspios-buster-armhf-full.img of=/dev/sdX bs=8M status=progress`

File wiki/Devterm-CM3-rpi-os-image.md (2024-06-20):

### Orginal image download URL
https://downloads.raspberrypi.org/raspios_full_armhf/images/raspios_full_armhf-2021-05-28/2021-05-07-raspios-buster-armhf-full.zip

#### Modification request list 
- [x] screen rotation for xrandr,fbcon,lightdm
- [x] Remove the wallpaper and change the solid color #202020  
- [x] Install all rpi-related debs in the apt source 

#### Packages in devterm apt source
1. devterm-audio-patch (check whether the 3.5 audio interface is plugged in, pull up a certain GPIO)
1. devterm-fan-temp-daemon-rpi (detect the temperature of rpi, raise the io drive fan, written in python)
1. devterm-kernel-rpi (modified kernel, 4.x series)
1. devterm-keyboard-firmware (Devterm keyboard firmware flashing tool, Advanced users only!)
1. devterm-thermal-printer (thermal printer program and systemd scripts)
1. devterm-thermal-printer-cups (CUPS filter for the thermal printer, and add the thermal printer to cups, so devterm printer can be seen in chromium) 

##### Add clockworkpi to apt source list
see https://github.com/clockworkpi/apt/tree/main/debian 
```
wget -O - https://raw.githubusercontent.com/clockworkpi/apt/main/debian/KEY.gpg | sudo apt-key add -

echo "deb https://raw.githubusercontent.com/clockworkpi/apt/main/debian/ stable main" | sudo tee -a /etc/apt/sources.list.d/clockworkpi.list
```

##### Config xrandr 
```
sudo bash -c 'cat << EOF > etc/X11/Xsession.d/100custom_xrandr
xrandr --output DSI-1 --rotate right
EOF'
```

##### Config lightdm
in `/etc/lightdm/lightdm.conf`
```
greeter-setup-script=/etc/lightdm/setup.sh
```
*setup.sh*
```
#!/bin/bash
xrandr --output DSI-1 --rotate right
exit 0
```
`sudo chmod +x etc/lightdm/setup.sh`

##### Modify /etc/dphys-swapfile
```
CONF_SWAPSIZE=512
```

##### Change the default wallpaper
The following files changed 

* /etc/xdg/pcmanfm/LXDE-pi/desktop-items-0.conf 
* /etc/xdg/pcmanfm/LXDE-pi/desktop-items-1.conf 
* /etc/lightdm/pi-greeter.conf 
* /home/pi/.config/pcmanfm/LXDE-pi/desktop-items-0.conf 

Delete wallpaper address `temple.jpg`  
Modify the `desktop_bg` color to `#202020` 

#### config.txt

Add `dtparam=audio=on` to solve the problem of no sound card under HDMI

##### /etc/hostname to clockworkpi

##### /boot/cmdline.txt ,add fbcon=rotate:1, remove quiet 

### Image download url
https://forum.clockworkpi.com/t/devterm-os-cm3-image-files/7151/1

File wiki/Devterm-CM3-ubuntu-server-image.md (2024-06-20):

### Img file

[ubuntu-21.04-preinstalled-server-armhf+raspi.img](https://cdimage.ubuntu.com/releases/21.04/release/ubuntu-21.04-preinstalled-server-armhf+raspi.img.xz)

### Prepare
Edit /boot/cmdline.txt and /etc/fstab of this img   
**/boot/cmdline.txt**  
```
console=serial0,115200 console=tty1 root=PARTUUID=78e1086a-02  rootfstype=ext4 elevator=deadline rootwait fixrtc splash fbcon=rotate:1
```
to use HDMI console,consider to remove **fbcon=rotate:1** in `/boot/cmdline.txt`

**/etc/fstab**  
```
PARTUUID=78e1086a-02   	   /         ext4   discard,errors=remount-ro       0 1
PARTUUID=78e1086a-01       /boot/    vfat   defaults        0       1
```

### Enter chroot
```
sudo losetup -P /dev/loop10 ubuntu-21.04-preinstalled-server-armhf+raspi.img
sudo mount /dev/loop10p2 /mnt/p2
sudo mount /dev/loop10p1 /mnt/p2/boot
cd /mnt/p2
sudo mount --bind /dev dev/
sudo mount --bind /sys sys/
sudo mount --bind /proc proc/
sudo mount --bind /dev/pts dev/pts

sudo chroot .
```

### Inside chroot
```
sudo unlink /etc/resolv.conf
echo -en "nameserver 1.1.1.1\nnameserver 8.8.8.8\n" > /etc/resolv.conf

sudo apt remove linux-image-raspi linux-image-5.11.0-1007-raspi -y
sudo apt install net-tools network-manager -y

wget -O - https://raw.githubusercontent.com/clockworkpi/apt/main/debian/KEY.gpg | sudo apt-key add 
echo "deb https://raw.githubusercontent.com/clockworkpi/apt/main/debian/ stable main" | sudo tee -a /etc/apt/sources.list.d/clockworkpi.list
sudo apt update && sudo apt install devterm-thermal-printer devterm-keyboard-firmware devterm-fan-temp-daemon-rpi devterm-thermal-printer-cups devterm-kernel-rpi devterm-audio-patch devterm-backlight-rpi -y

```

```
mkdir /etc/lightdm/lightdm.conf.d/ -p

sudo bash -c 'cat <<EOF >/etc/lightdm/lightdm.conf.d/99-cpi.conf 
[SeatDefaults]

greeter-setup-script=/etc/lightdm/setup.sh
EOF'

sudo bash -c 'cat <<EOF >/etc/lightdm/setup.sh
#!/bin/bash
xrandr --output DSI-1 --rotate right
exit 0
EOF'

sudo chmod +x /etc/lightdm/setup.sh

sudo bash -c 'cat << EOF > /etc/X11/Xsession.d/100custom_xrandr
xrandr --output DSI-1 --rotate right
EOF'
```

`sudo apt-get install tasksel`

`sudo cp -f /lib/firmware/brcm/brcmfmac43456-sdio.raspberrypi,400.txt /lib/firmware/brcm/brcmfmac43456-sdio.txt`

`sudo apt install wiringpi`  
`sudo ln -s /lib/arm-linux-gnueabihf/libwiringPi.so.2 /lib/arm-linux-gnueabihf/libwiringPi.so`  

### Outside chroot

dd img to sd card    
power on CM3   
config the network    

`sudo tasksel` to select desktop env to install

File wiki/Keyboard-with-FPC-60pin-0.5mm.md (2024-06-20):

usb-serial | keyboard IO number | keyboard IO register 
-- | -- | --
3v3 | 3 | 3v3
TXD | 16 | PA10
RXD | 15 | PA9
GND | 1 | GND

USB  | keyboard IO number | keyboard IO register
-- | -- | --
5v power | 5 | 5v
GND | 22 | GND
data + | 18 | PA12(USB_DP)
data - | 17 | PA11(USB_DM)

can not have USB and usb-serial both ON  
sudo stm32flash -r devterm.kbd.0.3_48mhz.bin -S 0x08000000:65536 /dev/ttyUSB0    
srec_cat devterm.kbd.0.3_48mhz.bin -Binary -offset 0x08000000 -output devterm.kbd.0.3_48mhz.hex -Intel  

stm32flash -w devterm_kbd.bin -v  -S 0x08000000 /dev/ttyUSB0  

WechatIMG50

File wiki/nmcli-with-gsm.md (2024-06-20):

4G modem
# Packages

```
sudo apt install -y modemmmanager  network-manager  pppoe
```

# Power ON 4G ext(uconsole)
```
echo "pulling up gpio 34"
sudo gpio mode 34 out
sudo gpio write 34 1

echo "pulling up 33 to reset "
sudo gpio mode 33 out
sudo gpio write 33 1

sleep 5
sudo gpio write 33 0
echo "pulling back 33"
sleep 10
echo "done"

```
## cm4 version
```
sudo gpio mode 24 out 
sudo gpio write 24 1 

sudo gpio mode 15 out 
sudo gpio write 15 1 

sleep 5
sudo gpio write 15 0
```

## devterm 4G module
POWER 42  
RESET 43

# Power OFF 4G ext(uconsole)

```
echo "Power off 4G module"
sudo gpio mode 34 out 
sudo gpio write 34 0 

sudo gpio write 34 1
sleep 3
sudo gpio write 34 0

sleep 10
echo "Done"
```

## cm4 version
```
echo "Power off 4G module"
sudo gpio mode 24 out 
sudo gpio write 24 0 

sudo gpio write 24 1
sleep 3
sudo gpio write 24 0

sleep 10
echo "Done"
```

## List modem
```
mmcli -L
```

/org/freedesktop/ModemManager1/Modem/0 [QUALCOMM INCORPORATED] SIMCOM_SIM7600G-H

## Enable modem
```
sudo mmcli -m 0 - e
```

## How to use nmcli to create a NetworkManager 4G connection 

```
sudo nmcli c add type gsm ifname cdc-wdm0 con-name 4GNet apn yourapn gsm.username gsmusername gsm.password gsmpassword
```

replace **yourapn** and **gsmusername** with your carrier service

then we can see a `4GNet` in NetworkManager (like KDE's network manager UI)

I got the cdc-wdm0 from with **qmi_wwan** driver
```
mmcli -m 0 | grep "primary port"
```
it will be **ttyUSB2** if use **qcdm** driver 

Now we can use **nmtui** to connect 4GNet  
or
```
sudo nmcli connection up 4GNet  
sudo nmcli connection down 4GNet
```
if everything is right ,you will have your **ppp0**  in `sudo ifconfig`

Here is reference arguments I've used for nmcli

```
connection.id:                          Movistar
connection.uuid:                        acab2207-347a-424c-b366-b2c4ef4e4c75
connection.stable-id:                   --
connection.type:                        gsm
connection.interface-name:              ttyAMA0
connection.autoconnect:                 no
connection.autoconnect-priority:        0
connection.autoconnect-retries:         -1 (default)
connection.multi-connect:               0 (default)
connection.auth-retries:                -1
connection.timestamp:                   0
connection.read-only:                   no
connection.permissions:                 --
connection.zone:                        --
connection.master:                      --
connection.slave-type:                  --
connection.autoconnect-slaves:          -1 (default)
connection.secondaries:                 --
connection.gateway-ping-timeout:        0
connection.metered:                     unknown
connection.lldp:                        default
connection.mdns:                        -1 (default)
connection.llmnr:                       -1 (default)
ipv4.method:                            auto
ipv4.dns:                               --
ipv4.dns-search:                        --
ipv4.dns-options:                       ""
ipv4.dns-priority:                      0
ipv4.addresses:                         --
ipv4.gateway:                           --
ipv4.routes:                            --
ipv4.route-metric:                      -1
ipv4.route-table:                       0 (unspec)
ipv4.ignore-auto-routes:                no
ipv4.ignore-auto-dns:                   no
ipv4.dhcp-client-id:                    --
ipv4.dhcp-timeout:                      0 (default)
ipv4.dhcp-send-hostname:                yes
ipv4.dhcp-hostname:                     --
ipv4.dhcp-fqdn:                         --
ipv4.never-default:                     no
ipv4.may-fail:                          yes
ipv4.dad-timeout:                       -1 (default)
ipv6.method:                            auto
ipv6.dns:                               --
ipv6.dns-search:                        --
ipv6.dns-options:                       ""
ipv6.dns-priority:                      0
ipv6.addresses:                         --
ipv6.gateway:                           --
ipv6.routes:                            --
ipv6.route-metric:                      -1
ipv6.route-table:                       0 (unspec)
ipv6.ignore-auto-routes:                no
ipv6.ignore-auto-dns:                   no
ipv6.never-default:                     no
ipv6.may-fail:                          yes
ipv6.ip6-privacy:                       -1 (unknown)
ipv6.addr-gen-mode:                     stable-privacy
ipv6.dhcp-duid:                         --
ipv6.dhcp-send-hostname:                yes
ipv6.dhcp-hostname:                     --
ipv6.token:                             --
serial.baud:                            115200
serial.bits:                            8
serial.parity:                          none
serial.stopbits:                        1
serial.send-delay:                      0
ppp.noauth:                             yes
ppp.refuse-eap:                         no
ppp.refuse-pap:                         no
ppp.refuse-chap:                        no
ppp.refuse-mschap:                      no
ppp.refuse-mschapv2:                    no
ppp.nobsdcomp:                          no
ppp.nodeflate:                          no
ppp.no-vj-comp:                         no
ppp.require-mppe:                       no
ppp.require-mppe-128:                   no
ppp.mppe-stateful:                      no
ppp.crtscts:                            no
ppp.baud:                               115200
ppp.mru:                                0
ppp.mtu:                                auto
ppp.lcp-echo-failure:                   0
ppp.lcp-echo-interval:                  0
gsm.number:                             *99#
gsm.username:                           --
gsm.password:                           <hidden>
gsm.password-flags:                     0 (none)
gsm.apn:                                internet.movistar.com.co
gsm.network-id:                         --
gsm.pin:                                <hidden>
gsm.pin-flags:                          0 (none)
gsm.home-only:                          no
gsm.device-id:                          --
gsm.sim-id:                             --
gsm.sim-operator-id:                    --
gsm.mtu:                                auto
proxy.method:                           none
proxy.browser-only:                     no
proxy.pac-url:                          --
proxy.pac-script:                       --
```

if nmcli can not start the gsm connection with errors like Ipv4 stack ,dual-stack addressing not supported by the modem  
that means we need to re-compile the kernel   

requires all ppp driver in kernel   
**Devices drivers ->Network device support**  
and compile as *, not module  

```
Linux Kernel Configuration
└─> Device Drivers
   └─> USB support
      └─> USB Wireless Device Management support
as module
```

```
Linux Kernel Configuration
└─> Device Drivers
   └─> Network device support
     └─> USB Network Adapters
        └─> QMI WWAN driver for Qualcomm MSM based 3G and LTE modems

as module
```

on A06 
```
sudo apt install pppoe
```

## In order to use SIMCOM_SIM7600G-H to call or receive calls
we have to blacklist some kernel modules

```
$ cat /etc/modprobe.d/blacklist-qmi.conf
blacklist qmi_wwan
blacklist cdc_wdm
```

```
mmcli -m 0 --messaging-list-sms

mmcli -m 0  --voice-list-calls

mmcli -m 0 --voice-create-call='number=xxxxxxxxxxxx'

mmcli -m 0  --voice-list-calls

mmcli -m 0 --start -o 0

mmcli -m 0 --accept -o 1
```

# Enable ModemManager debug  
change `/etc/systemd/system/dbus-org.freedesktop.ModemManager1.service`  
add --debug after `/usr/sbin/ModemManager`  
```bash
...
[Service]
Type=dbus
BusName=org.freedesktop.ModemManager1
ExecStart=/usr/sbin/ModemManager --debug
StandardError=null
Restart=on-abort
...
```
Then  

```
sudo systemctl daemon-reload
sudo systemctl restart  ModemManager.service  
```

## show audio levels
```
sudo mmcli -m 0 --command "AT+CLVL=?"
response: '+CLVL: (0-5)'
```
## show current levels
```
sudo mmcli -m 0 --command "AT+CLVL?"
response: '+CLVL: 4'
```
```
sudo mmcli -m 0 --command "AT+CLVL=5"
response: ''
```
```
sudo mmcli -m 0 --command "AT+CLVL=10"
error: command failed: 'GDBus.Error:org.freedesktop.ModemManager1.Error.MobileEquipment.Unknown: Unknown error'
```

## mute mic
```
sudo mmcli -m 0 --command "AT+CMUT=?"
response: '+CMUT: (0-1)'
```
```
sudo mmcli -m 0 --command "AT+CMUT?"
response: '+CMUT: 0'
```
```
Mute (but may need to be used during a call)
sudo mmcli -m 0 --command "AT+CMUT=1"
```

no ring volume 

## Test signal 
```
sudo mmcli -m any --signal-setup=10 # 10secs to refresh   
sudo mmcli -m any # to see signal quality
```

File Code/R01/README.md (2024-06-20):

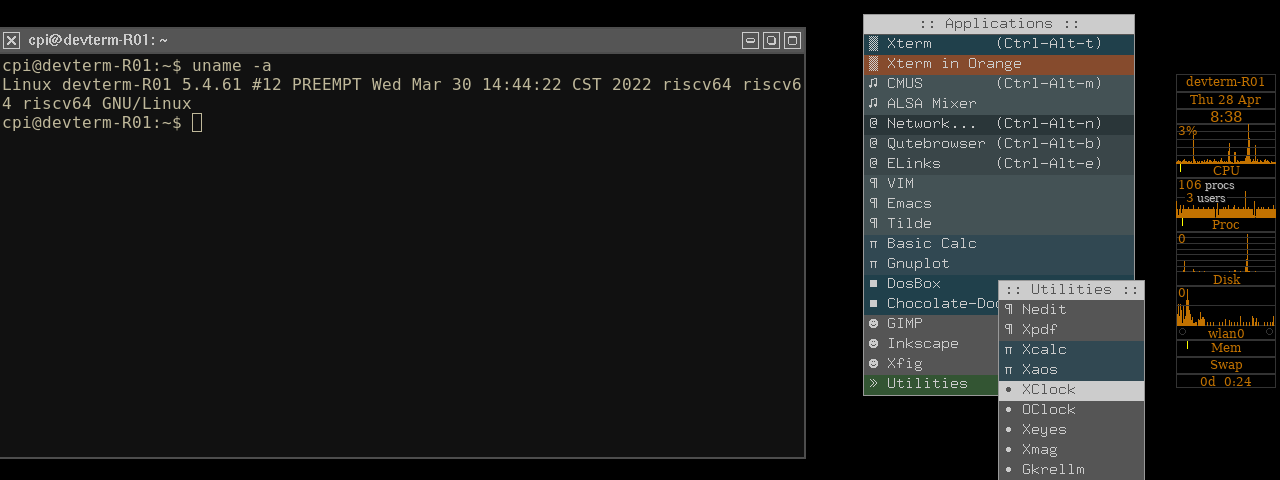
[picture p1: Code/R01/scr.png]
scr


Devterm R01

`d1_twm.tar.bz2`  devterm r01 stock os image twm configs  
```
.
..
.Xdefaults
.Xresources
.bash_profile
.bashrc
.gkrellm2
.twm
.twmrc
.xinitrc
readme
```

`tar xpjfv d1_twm.tar.bz2 -C /home/cpi`  
 
## Expand R01 rootfs partition size
```
wget https://github.com/clockworkpi/DevTerm/raw/main/Code/R01/expand_devterm_d1_root.sh
chmod +x expand_devterm_d1_root.sh
sudo ./expand_devterm_d1_root.sh
```

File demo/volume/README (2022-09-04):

/*
 * ALGO     : PROJ. : Volume(Demo)
 * RESEARCH : File  : README
 *          : Date  : 20100531.0725UTC
 *          : Email : mail@algoresearch.net
 */

# Project structure:
	.
	├── README
	├── CMakeLists.txt
	├── bin/
	├── build/
	├── include/
	│   ├── main.h
	│   ├── observer.h
	│   ├── space.h
	│   ├── transform.h
	│   └── x.h
	└── src/
	    ├── main.c
	    ├── observer.c
	    ├── space.c
	    ├── transform.c
	    └── x.c

# How to compile:
  At the project root directory, execute following commands:
	cd bulid
	cmake ..
	make

# How to run:
  If compiled correctly, the executable file(s) will be generated in
  the "./bin/" of the project root directory.

EOF.

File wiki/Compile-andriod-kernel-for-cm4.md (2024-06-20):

# Download kernel source for andriod of rpi4

**sync-andriod-kernel.sh**
```
#!/bin/bash

BIN_DIR=$HOME/bin
REPO_PATH=$BIN_DIR/repo

if [ ! -d $BIN_DIR ]
then
    mkdir $BIN_DIR
    add_path_env $BIN_DIR
    curl https://storage.googleapis.com/git-repo-downloads/repo > $REPO_PATH
    chmod a+x $REPO_PATH
else
    echo "folder already exits. $BIN_DIR"
fi

export PATH=$PATH:$BIN_DIR

cd /data/andriod-kernel
repo init -u https://github.com/android-rpi/kernel_manifest -b arpi-5.10
repo sync

```

# Compile 
```
cd /data/andriod-kernel/
./build/build.sh
```

# Replace files

```
sudo losetup --show -f -P lineage-19.1-20220511-UNOFFICIAL-KonstaKANG-rpi4.img # assume /dev/loop0
sudo mount /dev/loop0p1 /mnt/p1

# Copy kernel binaries to boot partition
cp -rf /data/andriod-kernel/out/arpi-5.10/dist/Image to /mnt/p1
cp -rf /data/andriod-kernel/out/arpi-5.10/dist/bcm2711-rpi-*.dtb /mnt/p1
cp -rf /data/andriod-kernel/out/arpi-5.10/dist/vc4-kms-v3d-pi4.dtbo to /mnt/p1/overlays/

sudo umount /mnt/p1
sudo losetup -D /dev/loop0

```

#  Reference Url
* https://github.com/android-rpi/kernel_manifest
* https://github.com/android-rpi/device_arpi_rpi4

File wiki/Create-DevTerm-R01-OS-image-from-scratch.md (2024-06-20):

# Before start 
Our system image is modified based on fedora wiki  
Mainly replace the kernel and rootfs  
Some linux experience is required to handle every possible situation  
there are some discrepancies with the final system image  
So this document is more suitable for the guidance of the R-01 system image  

# Prepare

a ubuntu linux system, like ubuntu 21.04

install riscv64 gcc
```
sudo apt install gcc-11-riscv64-linux-gnu binutils-riscv64-linux-gnu
sudo apt install git
sudo apt install make
sudo apt install build-essential
sudo apt install libfontconfig1
sudo apt install ncurses-devel
sudo apt install libncurses-dev
sudo apt install build-essential
sudo apt install flex bison
sudo apt install python3-distutils
sudo apt install swig
sudo apt install python3-dev
sudo apt install openssl
sudo apt install libssl-dev

```

install qemu static for chroot

`sudo apt install qemu-user-static`

manually fix default compiler link:

```
sudo ln -s /usr/bin/riscv64-linux-gnu-cpp-11 /usr/bin/riscv64-linux-gnu-cpp
sudo ln -s /usr/bin/riscv64-linux-gnu-gcc-nm-11 /usr/bin/riscv64-linux-gnu-gcc-nm
sudo ln -s /usr/bin/riscv64-linux-gnu-gcov-dump-11 /usr/bin/riscv64-linux-gnu-gcov-dump
sudo ln -s /usr/bin/riscv64-linux-gnu-gcc-11 /usr/bin/riscv64-linux-gnu-gcc
sudo ln -s /usr/bin/riscv64-linux-gnu-gcc-ranlib-11 /usr/bin/riscv64-linux-gnu-gcc-ranlib
sudo ln -s /usr/bin/riscv64-linux-gnu-gcov-tool-11 /usr/bin/riscv64-linux-gnu-gcov-tool
sudo ln -s /usr/bin/riscv64-linux-gnu-gcc-ar-11 /usr/bin/riscv64-linux-gnu-gcc-ar
sudo ln -s /usr/bin/riscv64-linux-gnu-gcov-11 /usr/bin/riscv64-linux-gnu-gcov
sudo ln -s /usr/bin/riscv64-linux-gnu-lto-dump-11 /usr/bin/riscv64-linux-gnu-lto-dump
```

# Bootloader

### reference doc:  
https://fedoraproject.org/wiki/Architectures/RISC-V/Allwinner

```
git clone https://github.com/smaeul/sun20i_d1_spl
pushd sun20i_d1_spl
git checkout origin/mainline
make CROSS_COMPILE=riscv64-linux-gnu- p=sun20iw1p1 mmc
popd
```

```
pushd sun20i_d1_spl
sudo dd if=nboot/boot0_sdcard_sun20iw1p1.bin of=/dev/sdX bs=512 seek=16
```

git clone https://github.com/tekkamanninja/opensbi -b allwinner_d1  
pushd opensbi  
CROSS_COMPILE=riscv64-linux-gnu- PLATFORM=generic FW_PIC=y BUILD_INFO=y make  
popd  

```
git clone https://github.com/tekkamanninja/u-boot -b allwinner_d1  
pushd u-boot  
make CROSS_COMPILE=riscv64-linux-gnu- ARCH=riscv nezha_defconfig  
make CROSS_COMPILE=riscv64-linux-gnu- ARCH=riscv menuconfig  
make CROSS_COMPILE=riscv64-linux-gnu- ARCH=riscv u-boot.bin u-boot.dtb  
popd  
```
**in menuconfig, there is an import option must be selected:**

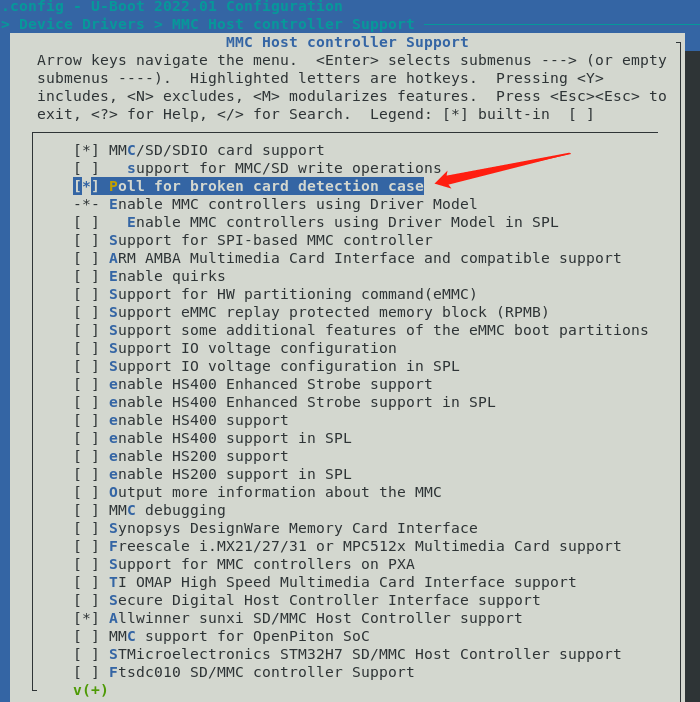
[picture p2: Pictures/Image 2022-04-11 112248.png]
menuconfig
 

otherwises, the boot will hang 

## u-boot.toc1

**toc1.cfg**

```
[opensbi]
file = fw_dynamic.bin
addr = 0x40000000
[dtb]
file = u-boot.dtb
addr = 0x44000000
[u-boot]
file = u-boot.bin
addr = 0x4a000000
```
```
pushd u-boot
cp ${PATH_TO_TOC1_CFG}/toc1.cfg ${PATH_TO_OPENSBI}/fw_dynamic.bin .
tools/mkimage -T sunxi_toc1 -d toc1.cfg  u-boot.toc1
popd
```

pushd u-boot  
sudo dd if=u-boot.toc1 of=/dev/sdX bs=512 seek=32800
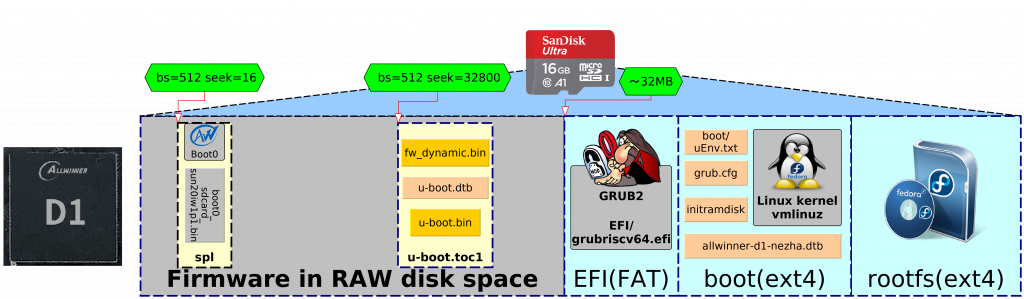
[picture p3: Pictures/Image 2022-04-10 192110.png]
boot


# Disk partition prepare

## Original fedora image fdisk partition
```
Units: sectors of 1 * 512 = 512 bytes
Sector size (logical/physical): 512 bytes / 512 bytes
I/O size (minimum/optimal): 512 bytes / 512 bytes
Disklabel type: dos
Disk identifier: 0xda568ce2

Device                                                                            Boot   Start      End  Sectors  Size Id Type
fedora-riscv64-d1-developer-xfce-rawhide-Rawhide-20211124-132603.n.0-sda.raw.img2        69632   319487   249856  122M  c W95 FAT32 (LBA)
fedora-riscv64-d1-developer-xfce-rawhide-Rawhide-20211124-132603.n.0-sda.raw.img3 *     319488  1320959  1001472  489M 83 Linux
fedora-riscv64-d1-developer-xfce-rawhide-Rawhide-20211124-132603.n.0-sda.raw.img4      1320960 25319423 23998464 11.5G 83 Linux
```

## Create disk image file

### create image file with dd
```
MEGA=16777216

dd if=/dev/zero bs=$MEGA count=1024 of=disk.img
echo -e "o\nn\np\n2\n69632\n319487\nn\np\n3\n319488\n1320959\nn\np\n4\n1320960\n\n\nt\n2\nc\na\n3\n\nw" | fdisk disk.img
fdisk -l disk.img
```
```
sudo losetup --show -f -P disk.img #/dev/loop1
sudo mkfs.vfat /dev/loop1p2
sudo mkfs.ext4 /dev/loop1p3
sudo mkfs.ext4 /dev/loop1p4
```

# Download ubuntu riscv image for rootfs

https://wiki.ubuntu.com/RISC-V

https://cdimage.ubuntu.com/releases/21.04/release/

https://cdimage.ubuntu.com/releases/21.04/release/ubuntu-21.04-preinstalled-server-riscv64+unmatched.img.xz

## Take rootfs of ubuntu out
```
sudo losetup --show -f -P ubuntu-21.04-preinstalled-server-riscv64+unmatched.img # eg: /dev/loop1,depends on your linux system

sudo mount /dev/loop1p1 /mnt/p1
sudo tar cpjfv ubuntu-21.04-preinstalled-server-riscv64+unmatched_rootfs.tar.bz2 -C /mnt/p1/ .
sudo umount /mnt/p1
sudo losetup -D /dev/loop1 #dettach,release /dev/loop1
```
download link:
https://mega.nz/file/IQFlWZKL#_ERlz3GXoUgxsIoaLHK8oQ2A6SNFcHhZpS2tF3N6RaQ  
https://mega.nz/file/IIlAHKST#PP8feOr6tHxdbD-Zoyj64G4TfG7HG_1s3VHasisP6h0

## Prebuilt files

### boot partition 

#### ubuntu_2104_devterm_d1_boot.tar.bz2  
```
https://mega.nz/file/NEsV1SRQ#FexV7wJhiUQKLcfBol4bB5m8UsX1O5qWet8geONclY4
https://mega.nz/file/YJUjiKKb#nrxH6BDvyGjpNSyZEzbRqbHk9ed9RE7jcuOPbTdximM
```

*included files*

```
├── board.dtb  
├── **boot**  
│ └── uEnv.txt  
├── config-5.4.61  
├── **efi**  
├── **extlinux**  
│ ├── extlinux.conf  
│ └── extlinux.conf.cpi.bak  
├── **grub2**  
│ └── **themes**  
│ └── **system**  
│ └── **background.png**  
├── grub.cfg  
├── System.map-5.4.61  
├── **uEnv.txt** -\> boot/uEnv.txt  
└── vmlinuz-5.4.61  
```

#### ubuntu_2104_devterm_d1_EFI.tar.bz2  

https://mega.nz/file/kNUBRBIB#NsPzKTDWbfBSTth7-eVz9gPjeaEdYnP7PfuYGz28cOk

**extlinux.conf is the file actually do the boot configuration**
 
# How to compile kernel

## get kernel source 
https://github.com/cuu/last_linux-5.4.git

it is a mirror kernel code from tina_d1_h  of all winner with all patched for devterm R-01
## Official toolchain
https://github.com/cuu/toolchain-thead-glibc #It's official allwinner toolchain
download toolchain

## Steps for compiling kernel

extract and put toolchain in any folder you like

then edit **m.sh** in `last_linux-5.4`

set correct path of toolchain for PATH

```
export PATH=/data/tina_d1_h/prebuilt/gcc/linux-x86/riscv/toolchain-thead-glibc/riscv64-glibc-gcc-thead_20200702/bin/:$PATH

```
to be 
```
export PATH=/wherever_you_put_toolchain/riscv64-glibc-gcc-thead_20200702/bin/:$PATH
```

then simply run ./m.sh to compile kernel

we just simple use the prebuit toolchain from all-winner to compile the patched kernel code based on all-winner tina for devterm_r01

and we have to ,because allwinner prebuilt toolchain has the neccessary custom opcode for the kernel of R-01

kernel patch url: https://github.com/clockworkpi/DevTerm/tree/main/Code/patch/d1

to get original tina code from allwinner ,visit https://open.allwinnertech.com/

## Mainline toolchain
https://github.com/riscv/riscv-gnu-toolchain  
all the same as Official toolchain except need to disable Vector in kernel `make menuconfig`  
  
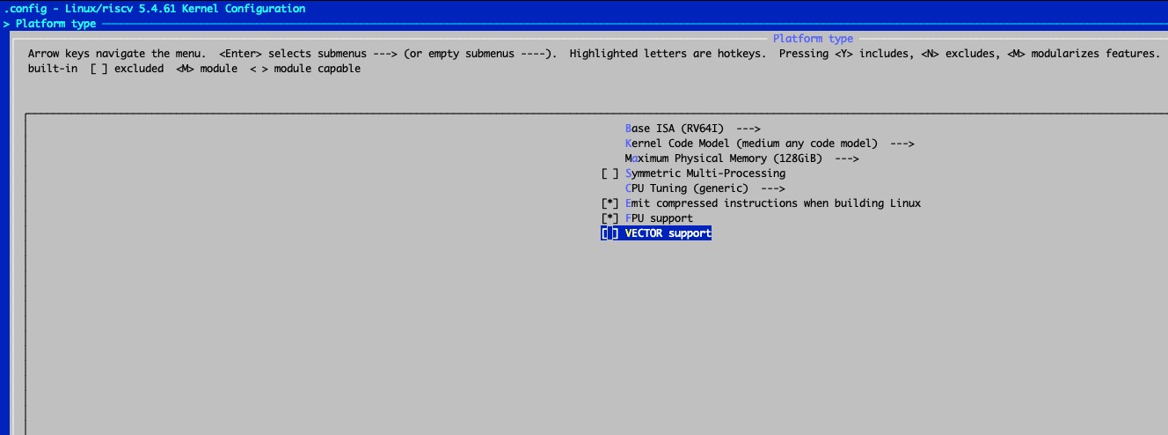
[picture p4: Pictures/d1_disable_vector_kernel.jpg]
d1_disable_vector_kernel
  

# Make alpha os image 

required file list:
* ubuntu_2104_devterm_d1_EFI.tar.bz2   
* ubuntu_2104_devterm_d1_boot.tar.bz2  
* ubuntu-21.04-preinstalled-server-riscv64+unmatched_rootfs.tar.bz2  
* boot0_sdcard_sun20iw1p1.bin
* u-boot.toc1 
* disk.img with all partitions formatted

```
sudo losetup --show -f -P disk.img  ## assume we will have /dev/loop1
sudo dd if=boot0_sdcard_sun20iw1p1.bin of=/dev/loop1 bs=512 seek=16
sudo dd if=u-boot.toc1 of=/dev/loop1 bs=512 seek=32800

sudo mount /dev/loop1p2 /mnt/p2
sudo mount /dev/loop1p3 /mnt/p3
sudo mount /dev/loop1p4 /mnt/p4
sudo tar xpjfv  ubuntu_2104_devterm_d1_EFI.tar.bz2 -C /mnt/p2
sudo tar xpjfv  ubuntu_2104_devterm_d1_boot.tar.bz2  -C /mnt/p3
sudo tar xpjfv ubuntu-21.04-preinstalled-server-riscv64+unmatched_rootfs.tar.bz2  -C /mnt/p4

```

## Chroot part
```
sudo mount /dev/loop1p3 /mnt/p4/boot
cd /mnt/p4

sudo mount --bind /dev dev/
sudo mount --bind /sys sys/
sudo mount --bind /proc proc/
sudo mount --bind /dev/pts dev/pts
sudo chroot .
```
### upgrade to devel 
now we are in chroot  
```
touch /etc/cloud/cloud-init.disabled
apt remove update-notifier-common  
apt-get update && apt-get purge needrestart
```
then edit `/etc/apt/source.list`, replace all hirsute to devel 
then
```
apt update
apt-get dist-upgrade
```
wait a long time until upgrade done(or retry if failed,it is neccessary for having a newer xorg/mesa in riscv to display)

after upgrade
```
apt update 
apt install  mesa-utils libgl1-mesa-glx libglx-mesa0 libgles2-mesa libegl-mesa0 
apt install -y  xterm cmus alsamixergui qutebrowser elinks vim emacs tilde bc gnuplot dosbox chocolate-doom gimp xfig xpdf xaos x11-apps gkrellm  imagemagick inkscape
apt remove multipath-tools
```

### add cpi user
```
useradd -m  cpi

#add into groups
usermod -a -G adm,dialout,cdrom,floppy,sudo,audio,dip,video,plugdev,netdev,lxd,pulse,pulse-access cpi
```
### Deploy the TWM window manager env.

The R-01 uses twm as default window manager for low resource usage

```
wget https://github.com/clockworkpi/DevTerm/blob/main/Code/R01/d1_twm.tar.bz2?raw=true

tar xpjfv d1_twm.tar.bz2 -C /home/cpi

chown -R cpi:cpi /home/cpi

```

### xorg fbdev config
rotate Xorg 
```
ubuntu@ubuntu:~$ cat /etc/X11/xorg.conf.d/10-d1.conf  
Section "Device" 
        Identifier "FBDEV" 
        Driver "fbdev" 
        Option "fbdev" "/dev/fb0" 
        Option "Rotate" "cw" 
        Option          "SwapbuffersWait" "true" 
EndSection 
 
Section "Screen" 
        Identifier "Screen0" 
        Device "FBDEV" 
        DefaultDepth 24 
 
        Subsection "Display" 
                Depth 24 
                Modes "1280x480" "480x1280" 
        EndSubsection 
 
EndSection
```

### Optmise time of boot
```
sudo systemctl mask apt-daily.service apt-daily-upgrade.service
sudo systemctl disable apt-daily.service apt-daily-upgrade.service
sudo systemctl disable apt-daily.timer apt-daily-upgrade.timer

sudo systemctl disable NetworkManager-wait-online.service 
sudo systemctl disable systemd-random-seed.service

sudo systemctl disable  e2scrub_reap.service
sudo systemctl disable systemd-networkd-wait-online.service

sudo systemctl disable lvm2-monitor.service

sudo systemctl disable snapd.seeded.service 
sudo systemctl disable pppd-dns.service

sudo systemctl disable avahi-daemon.service
sudo systemctl disable ModemManager.service

sudo systemctl disable apport.service
sudo systemctl mask apport.service
sudo systemctl disable accounts-daemon.service
sudo systemctl mask accounts-daemon.service
sudo systemctl disable udisks2.service   
```

### faster login
```
All scripts in /etc/update-motd.d/ transferred to other place or just deleted them all
```

### Install devterm related package
```
curl https://raw.githubusercontent.com/clockworkpi/apt/main/debian/KEY.gpg | sudo tee /etc/apt/trusted.gpg.d/clockworkpi.asc
echo "deb https://raw.githubusercontent.com/clockworkpi/apt/main/debian/ stable main" | sudo tee  /etc/apt/sources.list.d/clockworkpi.list  

apt update

apt install devterm-audio-patch devterm-backlight-cpi devterm-keyboard-firmware devterm-thermal-printer devterm-thermal-printer-cups devterm-wiringpi-cpi
```

## Get out chroot

```
exit
cd 

sudo umount /mnt/p4/dev/pts
sudo umount /mnt/p4/dev/
sudo umount /mnt/p4/proc
sudo umount /mnt/p4/sys
sudo umount /mnt/p4/boot

sudo umount /mnt/p3
sudo umount /mnt/p2
sudo umount /mnt/p4

sudo losetup -D /dev/loop1

```

# Final part

now we have a chroot edited os image file disk.img in 16GB with ubuntu devel branch root fs

you can still use 
```
sudo losetup --show -f -P disk.img  
sudo gparted /dev/loop1
``` 
to shrink the disk size to be like 8G or less to fit your sd card

then dd it into sd card

# Compiling other stuff

## WiringPI
```
git clone https://github.com/clockworkpi/DevTerm.git
wget https://github.com/WiringPi/WiringPi/archive/refs/tags/final_official_2.50.tar.gz
tar zxvf final_official_2.50.tar.gz 
cd WiringPi-final_official_2.50/
cp ../DevTerm/Code/patch/d1/wiringCP0329.patch .
git apply wiringCP0329.patch
sudo ./build
#Choice: 2

```

# For apt upgrade

apt upgrade on R01 os will mess up the content of extlinux.conf  
lead the boot failed  

so mount the sd card(with R01 os)  on a PC (like Linux )

then go into the **boot partition** of the sd card

you will see 
```
extlinux.conf  
extlinux.conf.cpi.bak  
```
replace extlinux.conf  with extlinux.conf.cpi.bak

the **extlinux.conf.cpi.bak** is for this kind of situation

# Hints
https://forum.clockworkpi.com/t/r01-os-early-hints/8636

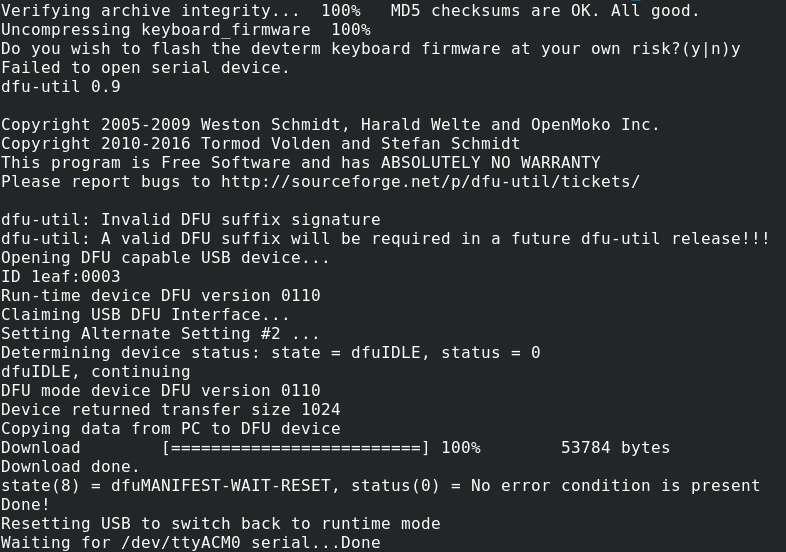
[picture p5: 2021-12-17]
Pictures/flash_keyboard_ok.png

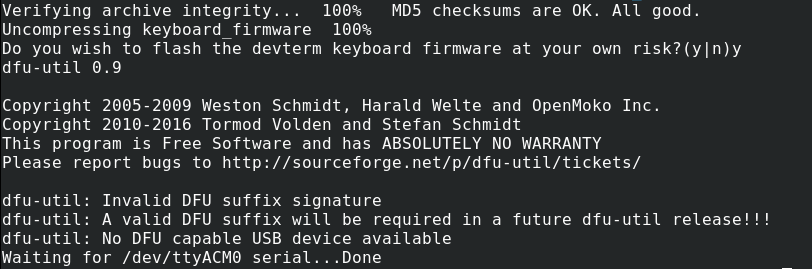
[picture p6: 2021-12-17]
Pictures/flash_keyboard_no_response.png

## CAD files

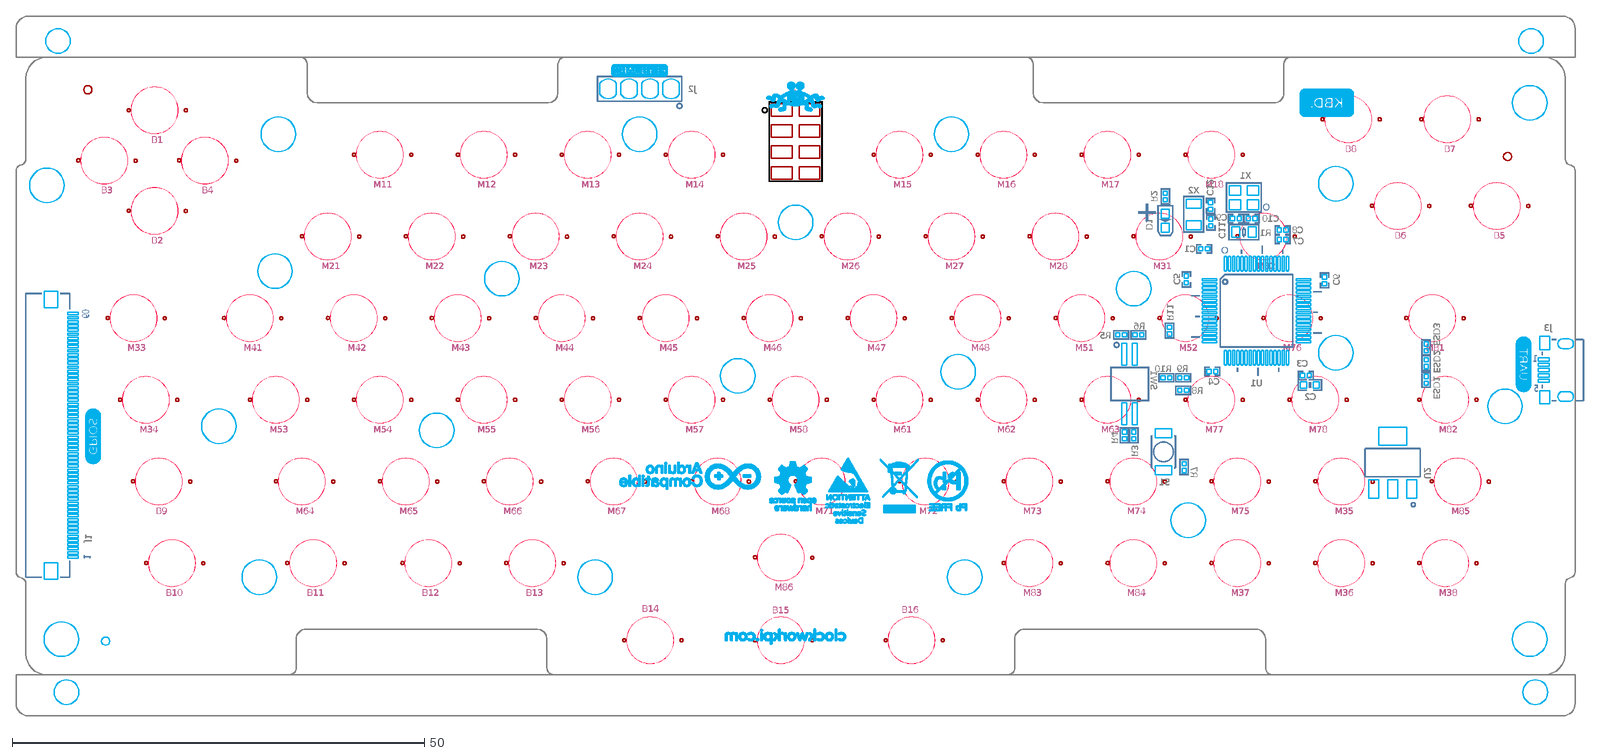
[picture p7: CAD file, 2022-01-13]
PCB/PCB_Outline_DevTerm_keyboard.dxf
B1
B5
M78
B10
B11
M83
B12
B13
M82
B4
B2
M55
B3
M86
M85
M54
M84
M43
M81
M42
M77
M76
M75
M74
M73
M72
M71
M68
M67
M66
M65
M64
M63
M62
M61
M58
M57
M56
M41
M44
M53
M52
M51
M48
M47
M46
M45
M28
B6
B7
B8
M38
M37
M36
M35
M34
M33
M32
M31
M24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

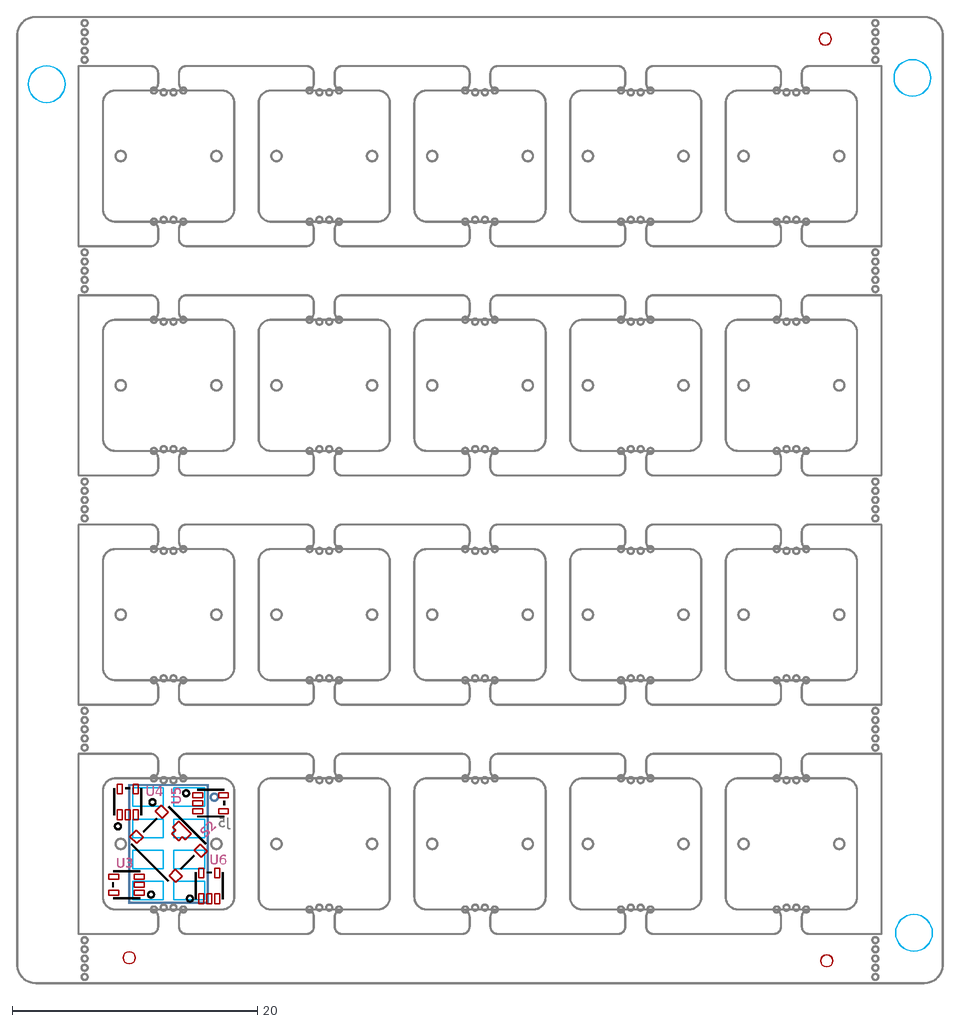
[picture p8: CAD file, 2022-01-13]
PCB/PCB_Outline_DevTerm_jogball.dxf
J5
S2
U3
U4
U5
U6

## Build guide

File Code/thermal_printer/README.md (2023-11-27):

# DevTerm Thermal printer 

### Console commands example

`echo "Hello DevTerm" > /tmp/DEVTERM_PRINTER_IN`

`echo -e "Hello DevTerm\n\n\n\n\n\n" > /tmp/DEVTERM_PRINTER_IN`

`cat file.txt > /tmp/DEVTERM_PRINTER_IN`

`ncal -hb | tee > /tmp/DEVTERM_PRINTER_IN`

### Eos/Pos commands example

#### ESC ! n  
set printer font index,n:0-4  
`echo -en "\x1d\x21\x0" > /tmp/DEVTERM_PRINTER_IN`  
`echo -en "\x1d\x21\x1" > /tmp/DEVTERM_PRINTER_IN`  
`echo -en "\x1d\x21\x2" > /tmp/DEVTERM_PRINTER_IN`  
`echo -en "\x1d\x21\x3" > /tmp/DEVTERM_PRINTER_IN`  
`echo -en "\x1d\x21\x4" > /tmp/DEVTERM_PRINTER_IN`  

##### ascii font size 
1. 0 = 8x16
1. 1 = 5x7
1. 2 = 6x12
1. 3 = 7x14
1. 4 = 8x16

##### unicode font size  

1. 0 = 12x12
1. 1 = 14x14
1. 2 = 16x16
1. 3 = 18x18
1. 4 = 20x20

https://github.com/clockworkpi/DevTerm/blob/81addc7f4ba1eb4acb2f59fb1fef70386dbe1f0d/Code/thermal_printer/devterm_thermal_printer.c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

#### DC2 # n   
n:0-F, set printer printing density 

If you want to set the printing depth (printer heating time), you can use the following command to set it:

For the lightest: 

`echo -en "\x12\x23\x0" > /tmp/DEVTERM_PRINTER_IN`

For the darkest: 

`echo -en "\x12\x23\xf" > /tmp/DEVTERM_PRINTER_IN`

There are a total of 16 levels from 0 to 0xf. The default density is 6.

The heating time can be determined using the formula "n * (300 + n*46) microseconds."

#### DC2 T  
print the test page  
`echo -en "\x12\x54" >  /tmp/DEVTERM_PRINTER_IN`

### UNICODE
Edit `/usr/local/etc/devterm-printer` ,point to an existed ttf file,eg: 
`TTF=/usr/share/fonts/opentype/noto/NotoSansCJK-Regular.ttc`

then restart devterm-printer.service with
```
sudo systemctl restart devterm-printer
```
devterm-printer daemon will auto detect the ttf font file
 
#### switch to UNICODE MODE  
```
echo -en "\x1b\x21\x1" > /tmp/DEVTERM_PRINTER_IN  
```
#### switch back to default ASCII mode  
```
echo -en "\x1b\x21\x0" > /tmp/DEVTERM_PRINTER_IN  
```

then

```
echo "日月火水木金土 ΕΙΝΑΙ Ο ΘΕΟΣ ΓΕΩΜΕΤΡΗΣ" > /tmp/DEVTERM_PRINTER_IN
```
to print unicode characters

#### ESC V n rotation command,unicode mode only

`echo -en "\x1b\x56\x0" >/tmp/DEVTERM_PRINTER_IN`  disable rotation  

`echo -en "\x1b\x56\x1" >/tmp/DEVTERM_PRINTER_IN`  90 degree   
`echo -en "\x1b\x56\x2" >/tmp/DEVTERM_PRINTER_IN`  180 degree  
`echo -en "\x1b\x56\x3" >/tmp/DEVTERM_PRINTER_IN`  270 degree  

### How to run it from source

* make  
* sudo systemctl stop devterm-printer   
* sudo cp -rf devterm_thermal_printer.elf /usr/local/bin  
* sudo systemctl start devterm-printer

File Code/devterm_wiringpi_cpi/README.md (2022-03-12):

## For developing wiringPi app under devterm a06 a04

```
 sudo apt remove libwiringpi-dev libwiringpi2
```

Then
```
sudo ./build
```

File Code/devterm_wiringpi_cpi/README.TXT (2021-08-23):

Note
====

This is an unofficial mirror of WiringPi to support ports (Python/Ruby/etc).

Please do not email Gordon if you have issues, he will not be able to help.

Pull-requests are not currently accepted, since this is a mirror.

For support, comments, questions, etc please join the WiringPi Discord channel: https://discord.gg/SM4WUVG

wiringPi README
===============

Please note that the official way to get wiringPi is via git from
git.drogon.net and not GitHub.

ie.

  git clone git://git.drogon.net/wiringPi

The version of wiringPi held on GitHub by "Gadgetoid" is used to build the
wiringPython, Ruby, Perl, etc. wrappers for these other languages. This
version may lag the official Drogon release.  Pull requests may not be
accepted to Github....

Please see

  http://wiringpi.com/

for the official documentation, etc. and the best way to submit bug reports, etc.
is by sending an email to projects@drogon.net

Thanks!

  -Gordon

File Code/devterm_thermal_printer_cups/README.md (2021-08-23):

STM32duino / wiringPi gpio  thermal printer filter for cups 

Clockworkpi CPI-58 (grayscale)

serial:/dev/ttyACM0?baud=115200+bits=8+parity=none+flow=none

serial:/tmp/DEVTERM\_PRINTER\_IN?baud=115200+bits=8+parity=none+flow=none

## build
sudo apt -y install libcups2-dev
make
sudo make install

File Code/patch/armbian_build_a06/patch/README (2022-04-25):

mkdir devterm-build
cd devterm-build

git clone https://github.com/armbian/build.git
git clone https://github.com/clockworkpi/DevTerm.git

cd build

git reset --hard 43d179914ae9e1ebb5d72315d9f9f68f5fb3e330

git apply ../DevTerm/Code/patch/armbian_build_a06/patch/armbian.patch
git apply ../DevTerm/Code/patch/armbian_build_a06/patch/armbian_mirror.patch

mkdir -p userpatches/kernel/rockchip64-current/
mkdir -p userpatches/u-boot/u-boot-rockchip64-mainline/

cp -f ../DevTerm/Code/patch/armbian_build_a06/patch/kernel*.patch userpatches/kernel/rockchip64-current/
cp -f ../DevTerm/Code/patch/armbian_build_a06/patch/uboot*.patch userpatches/u-boot/u-boot-rockchip64-mainline/
cp -f ../DevTerm/Code/patch/armbian_build_a06/patch/lib.config userpatches/
cp -f ../DevTerm/Code/patch/armbian_build_a06/patch/clockworkpi-a06.conf config/boards/

# Compile on A06 or compatible Ubuntu Hirsute linux system:
./compile.sh BOARD=clockworkpi-a06 BRANCH=current RELEASE=hirsute BUILD_MINIMAL=no BUILD_DESKTOP=yes KERNEL_ONLY=no KERNEL_CONFIGURE=no DESKTOP_ENVIRONMENT=xfce DESKTOP_ENVIRONMENT_CONFIG_NAME=config_base COMPRESS_OUTPUTIMAGE=sha,gpg,img

# Compile on any system that user has docker commandline access.
./compile.sh docker BOARD=clockworkpi-a06 BRANCH=current RELEASE=hirsute BUILD_MINIMAL=no BUILD_DESKTOP=yes KERNEL_ONLY=no KERNEL_CONFIGURE=no DESKTOP_ENVIRONMENT=xfce DESKTOP_ENVIRONMENT_CONFIG_NAME=config_base COMPRESS_OUTPUTIMAGE=sha,gpg,img

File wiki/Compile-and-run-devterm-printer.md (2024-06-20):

# a06 a04
```
git clone https://github.com/clockworkpi/DevTerm.git
sudo systemctl stop devterm-socat devterm-printer

sudo apt remove devterm-wiringpi-cpi

cd DevTerm/Code/devterm_wiringpi_cpi/

sudo ./build
cd ~/DevTerm/Code/thermal_printer/
sudo apt install -y libfreetype-dev
make

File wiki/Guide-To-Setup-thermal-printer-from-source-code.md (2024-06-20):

# Prepare
Before everything
We assume that you have a Devterm with stock os running  
and a little bit of Linux compiling experience   
know how to install packages by package manager like apt    

## WiringPi 
### CM3 or CM4 
```
sudo apt install -y wiringpi libwiringpi-dev libcups2-dev 
```

### A06 A04
```
git clone https://github.com/clockworkpi/DevTerm.git
cd DevTerm/Code/devterm_wiringpi_cpi/
sudo ./build
#chose 0 or 1 depend which board you have
```

### R01
```
git clone https://github.com/clockworkpi/DevTerm.git
wget https://github.com/WiringPi/WiringPi/archive/refs/tags/final_official_2.50.tar.gz
tar zxvf final_official_2.50.tar.gz 
cd WiringPi-final_official_2.50/
cp ../DevTerm/Code/patch/d1/wiringCP0329.patch .
git apply wiringCP0329.patch
sudo ./build
#Choice: 2
```

# Compile thermal printer driver code
```
git clone https://github.com/clockworkpi/DevTerm.git
cd DevTerm/Code/thermal_printer
make  
sudo systemctl stop devterm-printer   
sudo cp -rf devterm_thermal_printer.elf /usr/local/bin  
sudo systemctl start devterm-printer 
```
## Debug or run it from manually
1. setup socat socket for data receving for thermal printer
```
   sudo systemctl stop devterm-printer #stop service
   sudo systemctl stop devterm-socat   #stop service
   sudo socat -d -d pty,link=/tmp/DEVTERM_PRINTER_OUT,raw,echo=0 pty,link=/tmp/DEVTERM_PRINTER_IN,raw,echo=0
   sudo ./usr/local/bin/devterm_socat.sh # <- this .sh file is in DevTerm/Code/thermal_printer/usr/local/bin/
```
1. run devterm_thermal_printer.elf
```
   sudo ./devterm_thermal_printer.elf
```

now you can test the printer by cat or echo something into `/tmp/DEVTERM_PRINTER_IN`   
eg: `echo "hello world\n\n\n\n\n\n\n\n\n\n" > /tmp/DEVTERM_PRINTER_IN

we recommend use [tmux](https://github.com/tmux/tmux/wiki) to do this job  
so that you can run and see all the commands output in a single terminal window

## For CUPS
just install `devterm-thermal-printer-cups`  
``` sudo apt install devterm-thermal-printer-cups```

this package will add a CUPS serial printer adapter,a CUPS filter for the DevTerm's thermal printer  
and will let other programs to  print content through image printing using DevTerm's thermal printer  
source code is in https://github.com/clockworkpi/DevTerm/tree/main/Code/devterm_thermal_printer_cups

all devterm related deb packages available at 

https://github.com/clockworkpi/apt

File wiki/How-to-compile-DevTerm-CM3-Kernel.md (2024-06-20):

## Env 
VirtualBox with ubuntu 20.04

## Toolchain

https://github.com/raspberrypi/tools/tree/master/arm-bcm2708/arm-rpi-4.9.3-linux-gnueabihf/bin

## Get kernel
1. git clone https://github.com/raspberrypi/linux.git
1. cd linux
1. git checkout remotes/origin/rpi-4.19.y
1. git reset --hard cc39f1c9f82f6fe5a437836811d906c709e0661c
1. git apply [devterm-4.19_v0.1.patch](https://raw.githubusercontent.com/clockworkpi/DevTerm/main/Code/kernel/devterm-4.19_v0.1.patch)

## Compile
```
KERNEL=kernel7 make ARCH=arm CROSS_COMPILE=arm-linux-gnueabihf- bcm2709_defconfig
KERNEL=kernel7 make ARCH=arm CROSS_COMPILE=arm-linux-gnueabihf- -j3
export INSTALL_MOD_PATH=./modules
rm -rf $INSTALL_MOD_PATH
make modules_install
rm $INSTALL_MOD_PATH/lib/modules/*/build
rm $INSTALL_MOD_PATH/lib/modules/*/source
```

## copy kernel to SD card
$1 is the sd card location (mount point)
```
export INSTALL_MOD_PATH=./modules
sudo cp -r $INSTALL_MOD_PATH/lib/modules $1/rootfs/lib/
cat config_a >> $1/boot/config.txt
cp arch/arm/boot/zImage $1/boot/kernel7.img
cp arch/arm/boot/dts/bcm2710-rpi-cm3.dtb $1/boot/bcm2710-rpi-cm3.dtb
cp arch/arm/boot/dts/overlays/*.dtbo $1/boot/overlays/
```

## config_a
```
ignore_lcd=1
dtoverlay=vc4-kms-v3d,audio=0,cma-384
dtoverlay=devterm-pmu
dtoverlay=devterm-panel
dtoverlay=devterm-wifi
dtoverlay=devterm-bt
dtoverlay=devterm-misc
gpio=5=op,dh
gpio=9=op,dh
gpio=10=ip,np
gpio=11=op,dh

enable_uart=1
```

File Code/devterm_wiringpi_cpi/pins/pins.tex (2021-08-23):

\documentclass[12pt,a4paper]{article}
\parskip 1ex
\parindent 0em
\thispagestyle{empty}
\pagestyle{plain}
\pagenumbering{arabic}
\setlength{\topmargin}{0pt}
\setlength{\headheight}{0pt}
\setlength{\headsep}{0pt}
\setlength{\topskip}{0pt}
\setlength{\textheight}{240mm}
\setlength{\footskip}{5ex}
\setlength{\oddsidemargin}{0pt}
\setlength{\evensidemargin}{0pt}
\setlength{\textwidth}{160mm}
\usepackage[dvips]{graphics,color}
\usepackage{helvet}
\renewcommand{\familydefault}{\sfdefault}
\begin{document}
\begin{sffamily}
\definecolor{rtb-black}{rgb}  {0.0, 0.0, 0.0}
\definecolor{rtb-navy}{rgb}   {0.0, 0.0, 0.5}
\definecolor{rtb-green}{rgb}  {0.0, 0.5, 0.0}
\definecolor{rtb-teal}{rgb}   {0.0, 0.5, 0.5}
\definecolor{rtb-maroon}{rgb} {0.5, 0.0, 0.0}
\definecolor{rtb-purple}{rgb} {0.5, 0.0, 0.5}
\definecolor{rtb-olive}{rgb}  {0.5, 0.5, 0.0}
\definecolor{rtb-silver}{rgb} {0.7, 0.7, 0.7}
\definecolor{rtb-grey}{rgb}   {0.5, 0.5, 0.5}
\definecolor{rtb-blue}{rgb}   {0.0, 0.0, 1.0}
\definecolor{rtb-lime}{rgb}   {0.0, 1.0, 0.0}
\definecolor{rtb-aqua}{rgb}   {0.0, 1.0, 1.0}
\definecolor{rtb-red}{rgb}    {1.0, 0.0, 0.0}
\definecolor{rtb-fuchsia}{rgb}{1.0, 0.0, 1.0}
\definecolor{rtb-yellow}{rgb} {1.0, 1.0, 0.0}
\definecolor{rtb-white}{rgb}  {1.0, 1.0, 1.0}

\begin{center}
\bfseries{WiringPi: GPIO Pin Numbering Tables}\\
\tt{http://wiringpi.com/}
\end{center}

\begin{center}
\begin{tabular}{|c|c|c||p{8mm}|p{8mm}||c|c|c|c|}
\hline
\multicolumn{8}{|c|}{\bfseries{P1: The Main GPIO connector}}\\
\hline
\hline
WiringPi Pin	& BCM GPIO	& Name	& \multicolumn{2}{|c||}{Header}	& Name	& BCM GPIO	& WiringPi Pin\\
\hline
\hline
	& 			& \textcolor{rtb-red}{3.3v}	& \raggedleft{1} &  2 & \textcolor{rtb-maroon}{5v}	& 	& \\
\hline
8	& Rv1:0 - Rv2:2		& \textcolor{rtb-aqua}{SDA}	& \raggedleft{3} &  4 & \textcolor{rtb-maroon}{5v}	& 	& \\
\hline
9	& Rv1:1 - Rv2:3		& \textcolor{rtb-aqua}{SCL}	& \raggedleft{5} &  6 & \textcolor{rtb-black}{0v}	& 	& \\
\hline
7	& 4			& \textcolor{rtb-green}{GPIO7}	& \raggedleft{7} &  8 & \textcolor{rtb-yellow}{TxD}	& 14    & 15\\
\hline
	& 			& \textcolor{rtb-black}{0v}	& \raggedleft{9} & 10 & \textcolor{rtb-yellow}{RxD}	& 15	& 16\\
\hline
0	& 17			& \textcolor{rtb-green}{GPIO0}	& \raggedleft{11} & 12 & \textcolor{rtb-green}{GPIO1}	& 18	& 1\\
\hline
2	& Rv1:21 - Rv2:27	& \textcolor{rtb-green}{GPIO2}	& \raggedleft{13} & 14 & \textcolor{rtb-black}{0v}	& 	& \\
\hline
3	& 22			& \textcolor{rtb-green}{GPIO3}	& \raggedleft{15} & 16 & \textcolor{rtb-green}{GPIO4}	& 23	& 4\\
\hline
	& 			& \textcolor{rtb-red}{3.3v}	& \raggedleft{17} & 18 & \textcolor{rtb-green}{GPIO5}	& 24	& 5\\
\hline
12	& 10			& \textcolor{rtb-teal}{MOSI}	& \raggedleft{19} & 20 & \textcolor{rtb-black}{0v}	& 	& \\
\hline
13	& 9			& \textcolor{rtb-teal}{MISO}	& \raggedleft{21} & 22 & \textcolor{rtb-green}{GPIO6}	& 25	& 6\\
\hline
14	& 11			& \textcolor{rtb-teal}{SCLK}	& \raggedleft{23} & 24 & \textcolor{rtb-teal}{CE0}	& 8	& 10\\
\hline
	& 			& \textcolor{rtb-black}{0v}	& \raggedleft{25} & 26 & \textcolor{rtb-teal}{CE1}	& 7	& 11\\
\hline
\hline
WiringPi Pin	& BCM GPIO	& Name	& \multicolumn{2}{|c||}{Header}	& Name	& BCM GPIO	& WiringPi Pin\\
\hline
\end{tabular}
\end{center}

Note the differences between Revision 1 and Revision 2 Raspberry
Pi's. The Revision 2 is readily identifiable by the presence of the 2
mounting holes.

The revision 2 Raspberry Pi has an additional GPIO connector, P5, which is next to the main P1 GPIO
connector:

\begin{center}
\begin{tabular}{|c|c|c||p{8mm}|p{8mm}||c|c|c|c|}
\hline
\multicolumn{8}{|c|}{\bfseries{P5: Secondary GPIO connector (Rev. 2 Pi only)}}\\
\hline
\hline
WiringPi Pin	& BCM GPIO	& Name	& \multicolumn{2}{|c||}{Header}	& Name	& BCM GPIO	& WiringPi Pin\\
\hline
\hline
	& 		& \textcolor{rtb-maroon}{5v}	& \raggedleft{1} &  2 & \textcolor{rtb-red}{3.3v}	& 	&	\\
\hline
17	& 28		& \textcolor{rtb-green}{GPIO8}	& \raggedleft{3} &  4 & \textcolor{rtb-green}{GPIO9}	& 29	& 18	\\
\hline
19	& 30		& \textcolor{rtb-green}{GPIO10}	& \raggedleft{5} &  6 & \textcolor{rtb-green}{GPIO11}	& 31	& 20	\\
\hline
	& 		& \textcolor{rtb-black}{0v}	& \raggedleft{7} &  8 & \textcolor{rtb-black}{0v}	& 	&	\\
\hline
\hline
WiringPi Pin	& BCM GPIO	& Name	& \multicolumn{2}{|c||}{Header}	& Name	& BCM GPIO	& WiringPi Pin\\
\hline
\end{tabular}
\end{center}

\end{sffamily}
\end{document}

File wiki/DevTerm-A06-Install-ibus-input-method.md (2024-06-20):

`sudo apt install ibus ibus-pinyin -y`
```
cat <<EOF >~/.config/autostart/ibus.desktop
[Desktop Entry]
Exec=ibus-daemon -drxR
GenericName=IBus
Name[zh_CN]=IBus
Name=IBus
Name[en_US]=IBus
StartupNotify=true
Terminal=false
Type=Application
EOF
```

```
sudo bash -c 'cat <<EOF >/etc/profile.d/ibus.sh
#!/bin/bash

export XIM_PROGRAM=ibus
export XIM=ibus
export XMODIFIERS=@im=ibus
export GTK_IM_MODULE=ibus
export QT_IM_MODULE=ibus
EOF'
```

`sudo reboot `

Then right-click the ibus icon in the upper right corner of the top menu  
select preferences  
add (Add) **pinyin** input method, the default is super+space to enable the input method  
you can change the shortcut in **iBus Preferences**

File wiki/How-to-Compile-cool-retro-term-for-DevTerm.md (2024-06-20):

# cool-retro-term

### Install the necessary packages: 
#### CM3 
```
sudo apt update
sudo apt install build-essential qmlscene qt5-qmake qt5-default qtdeclarative5-dev qml-module-qtquick-controls qml-module-qtgraphicaleffects qml-module-qtquick-dialogs qml-module-qtquick-localstorage qml-module-qtquick-window2 qml-module-qt-labs-settings qml-module-qt-labs-folderlistmodel
```
#### ubuntu (A06)
```
sudo apt update
sudo apt install build-essential qmlscene qt5-qmake qtbase5-dev qtchooser qt5-qmake qtbase5-dev-tools  qtdeclarative5-dev qml-module-qtquick-controls qml-module-qtgraphicaleffects qml-module-qtquick-dialogs qml-module-qtquick-localstorage qml-module-qtquick-window2 qml-module-qt-labs-settings qml-module-qt-labs-folderlistmodel
```
### Compile (it takes about 30 minutes):
```
cd ~
git clone --recursive https://github.com/Swordfish90/cool-retro-term.git
cd cool-retro-term
git reset --hard dac2b4
qmake && make
cp -r qmltermwidget/src/qmldir qmltermwidget/lib/kb-layouts qmltermwidget/lib/color-schemes qmltermwidget/src/QMLTermScrollbar.qml qmltermwidget/QMLTermWidget
```

### Run

`./cool-retro-term --fullscreen`

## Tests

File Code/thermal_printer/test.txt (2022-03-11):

“励志一生”网站精心挑选汇集了60句宋词佳句，转载过来与大家分享，也很值得收藏！

1. 一ada;场消黯，永日无言，却下层楼。——柳永〈曲玉管〉

2. 可惜流asdfsad年，忧愁风雨，树犹如此。——辛弃疾〈水龙吟．登建康赏心亭〉

3. 十年生死两茫茫，不dsafadsf思量，自难忘。——苏轼〈江城子〉

4. 纵使相逢应不识，尘满面，鬓nbqga&*(如霜。——苏轼〈江城子〉

5. 相顾无言，惟有泪千行。——苏轼〈江城子〉

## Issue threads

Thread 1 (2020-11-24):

keyboard mini

zerotrzy, 2020-11-24:
In my opinion this keyboard will be great version https://klawiatura.files.wordpress.com/2020/08/kl.jpg
big potenciometer, and moving status/menu bar to keyboard.
i3wm + led keys (which virtual screen use)
change + key (not necessary shift to use +) etc.

Is possible buy version without printer but with battery for 24h working time?

carlsmith, 2021-01-08:
The link is dead.

trollsid, 2021-02-07:
https://www.pine64.org/wp-content/uploads/2020/07/PinePhonekeyboard2.jpg
Look like n950 keyboard or enhanced version of n900

dangpzanco, 2022-04-21:
I don't quite understand the motivation of this issue (maybe it should be closed?), but since the link was dead I got it from web archive:

https://web.archive.org/web/20201121135805/https://klawiatura.files.wordpress.com/2020/08/kl.jpg

This keyboard features a very unusual design: the idea of the potentiometer (the 2 circles on top right corner) is very interesting from the perspective of using the DevTerm as a retro digital synth, but the QWEȨRTπYUIOÓP ordering of keys is WEIRD.

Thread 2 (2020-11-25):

Bill of materials

blackketter, 2020-11-25:
Thanks for posting the main board schematic!  Unfortunately it seems to be missing part numbers.  Would it be possible to post a bill of materials with the component part numbers and the corresponding references that appear on the schematic?

tsacks, 2020-11-29:
This might not be worth much at the moment, but I think I might have figured out the ICs based on the function and pinouts.

U101- AXP221 PMIC
U201- RF Link K019-CW43-DW
U301- ST HDMI05-CL01F3
U302- Broadchip BCT3661B
U501- GL850G USB 2.0 hub chip

Godzil, 2021-03-29:
The BOM is not necessarily the issue, would be nice to have, but you can derive it from a schematic. What really miss is that all of the component values are missing (which include the part number)

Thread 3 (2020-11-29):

Issues with the USB-C connector

Godzil, 2020-11-29:
I'm sure you ran test, and hope the currently released schematic is not the latest, but the way you connected the USB-C connector is invalid.

CC1 and CC2 should NOT be left non connected, as what you've done in the current schematic. It will probably only work with some passive USB-A to USB-C cable. But a USB-C host with a USB-C to USB-C cable will refuse to charge and transmit data to the DevTerm.

This is a common trap with USB-C design, especially when they are used for USB 2 type connection.

Here some details about the CC pin:

https://www.silabs.com/community/mcu/8-bit/knowledge-base.entry.html/2016/09/26/what_s_the_role_ofc-kQYe
https://www.allaboutcircuits.com/technical-articles/introduction-to-usb-type-c-which-pins-power-delivery-data-transfer/

From Microchip document:
http://ww1.microchip.com/downloads/en/AppNotes/00001953A.pdf

> The CC1 and CC2 pins are critical for basic USB Type-C operation. Resistors are attached to the CC pins in various configurations depending on whether the application is a downstream facing port (DFP), upstream facing port (UFP), or an electronically marked/active cable

**This is important, please do not overlook that for the final product!**

Godzil, 2021-03-29:
Issue fixed in commit 9278b6bad3ee98b234c7ef429d47a5222f95a5ce :)

Closed 2021-03-29.

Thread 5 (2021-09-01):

Please publish the DevTerm CM3 changes

Godzil, 2021-09-01:
Changes compared to the original Raspbian distribution

That include the changes done to the linux kernel if any, but considering that you use `devterm-kernel7.img` for the kernel name is it at least custom built, so the config file would be needed

This also include all the DTS overlay file that are included in the default CM3 image.

And any other relevant changes done.

It would be nice also to have a documentation on how the image was built. I think from the `issue.txt` in `/boot` you used pi-gen ( https://github.com/RPi-Distro/pi-gen ), what option were used to generate the image?

cuu, 2021-09-01:
sure thing, in couple of days I will make a doc for that
and I did not use pi-gen, I just use chroot to do the modifications

cuu, 2021-09-02:
# Devterm CM3 rpi os image

### Orginal image download url
https://downloads.raspberrypi.org/raspios_full_armhf/images/raspios_full_armhf-2021-05-28/2021-05-07-raspios-buster-armhf-full.zip

#### Modification request list
- [x] chromium downgrade to 84.0.4147.141
- [x] screen rotation for xrandr,fbcon,lightdm
- [x] Remove the wallpaper and change the solid color #202020
- [x] Install all rpi-related debs in the apt source

#### Packages in apt source
1. devterm-audio-patch (check whether the 3.5 audio interface is plugged in, pull up a certain GPIO)
1. devterm-fan-temp-daemon-rpi (detect the temperature of rpi, raise the io drive fan, written in python)
1. devterm-kernel-rpi (modified kernel, 4.x series)
1. devterm-keyboard-firmware (keyboard firmware, just copy to /usr/local/bin, users need to manually flash it)
1. devterm-thermal-printer (printer program and scripts such as systemctl)
1. devterm-thermal-printer-cups (CUPS filter for thermal printer, and add thermal printer to cups, devterm printer can be seen in chrome)

##### Add clockworkpi to /etc/hosts, then install devterm related apt, see https://github.com/clockworkpi/apt/tree/main/debian
```
wget -O - https://raw.githubusercontent.com/clockworkpi/apt/main/debian/KEY.gpg | sudo apt-key add -

echo "deb https://raw.githubusercontent.com/clockworkpi/apt/main/debian/ stable main" | sudo tee -a /etc/apt/sources.list.d/clockworkpi.list
```

##### config xrandr
```
sudo bash -c 'cat << EOF > etc/X11/Xsession.d/100custom_xrandr
xrandr --output DSI-1 --rotate right
EOF'
```

##### config lightdm
in `/etc/lightdm/lightdm.conf`
```
greeter-setup-script=/etc/lightdm/setup.sh
```
*setup.sh*
```
#!/bin/bash
xrandr --output DSI-1 --rotate right
exit 0
```
`sudo chmod +x etc/lightdm/setup.sh`

##### Modify /etc/dphys-swapfile
```
CONF_SWAPSIZE=512
```

##### Change the default wallpaper
The following files changed

* /etc/xdg/pcmanfm/LXDE-pi/desktop-items-0.conf
* /etc/xdg/pcmanfm/LXDE-pi/desktop-items-1.conf
* /etc/lightdm/pi-greeter.conf
* /home/pi/.config/pcmanfm/LXDE-pi/desktop-items-0.conf
*
Delete wallpaper address temple.jpg
Modify the desktop_bg color to #202020

#### config.txt

Add dtparam=audio=on to solve the problem of no sound card under hdmi

##### /etc/hostname to clockworkpi

##### /boot/cmdline.txt ,add fbcon=rotate:1, remove quiet

voronoipotato, 2022-01-31:
Is there a timeline for the a04 imaging instructions? I presume it's going to be pretty similar to the A06 ones?

cuu, 2022-01-31:
@voronoipotato
https://github.com/clockworkpi/DevTerm/wiki/Create-DevTerm-A04-OS-image-from-scratch

very similar to A06 image creation process

kpeeem, 2022-06-26:
+ Please publish the DevTerm CM3 too 🙏

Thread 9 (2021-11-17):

Thermal Printer not actually printing anything

cawfeecoder, 2021-11-17:
I installed the thermal printer drivers and the paper advances, but nothing is printed onto the paper. I'm probably doing something stupid...

Mihaylov93, 2021-12-06:
Did you try the other side of the paper? An user on the forum found a paper that was reversed and had to put it on the opposite side.

voronoipotato, 2022-01-31:
you can use a key to see which side is the 'active side'. Scratch the thermal paper with a key, or your fingernail and it will turn dark on the active side.

andypiper, 2022-06-09:
Did this get resolved in the end?

Were you trying to print text, or images?

cawfeecoder, 2022-06-10:
I did. Seems I never sent my response (was still in my draft), but I got it
working :)

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

--
Regards,
Nick Frush

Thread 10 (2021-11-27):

A06 Kernel gets replaced after build

reostat, 2021-11-27:
I'm following along the instructions described in `Create DevTerm A06 OS image from scratch` wiki page and there's something I don't quite understand. It seems that first we carefully apply kernel and u-boot patches and then build the image that's going to contain these patched kernel and u-boot; okay, makes sense so far. However, further down the lines in chroot we execute this
```bash
sudo apt remove linux-image*
sudo apt install devterm-kernel-current-cpi-a06 devterm-fan-daemon-cpi-a06 devterm-thermal-printer devterm-thermal-printer-cups devterm-wiringpi-cpi  devterm-first-start-a06
```
which to me looks like we completely remove our carefully patched and compiled kernel - perhaps of the exact version we wanted - and replace it with a precompiled binary from DevTerm repository.

Why do we do that?

cuu, 2021-11-27:
good point
when I try to build the a06 os image ,there is a step , I combined the build linux-dto* and linux-image* to became devterm-kernel-current-cpi-a06
the reason is if not doing this , apt-get upgrade will cover the linux-dto,linux-image*, which will cause boot failed
so to keep linux kernel in safe , I made devterm-kernel-current-cpi-a06

but for the wiki, I am not sure how to explain this, you got the point right,it seems a little wired

reostat, 2021-11-27:
I see. There's a way to prevent updates of selected packages (including the kernel) in apt-based systems using `apt-mark hold <pkgname>`, perhaps it'd be a better way.

In the meantime, could you please publish the procedure you use to make `devterm-kernel-current-cpi-a06` so if somebody wants to add their own patches they can build the kernel themselves?

cuu, 2021-11-27:
first use armbian build system to build image
after image done
unzip linux-dtb-current-rockchip64, linux-image-current-rockchip64
and then combine all files ,all the postinst, preinst,prerm,postrm
to be one deb file

sakunamary, 2022-10-20:
> first use armbian build system to build image after image done unzip linux-dtb-current-rockchip64, linux-image-current-rockchip64 and then combine all files ,all the postinst, preinst,prerm,postrm to be one deb file

Sorry , I don't know  what  kinds of commands I should do to combine  postinst ,preinst,.... It 's mean put all file under one folder and then package all files into deb ; OR copy and paste then content into ONE  postinst ,preinst ...
Thanks!
不好意思，我太理解combine 这个动作,在两个deb文件中的postinst preinst 文件解压缩完了之后，是放在一个新的文件夹里面（这样不会覆盖文件的问题么？），还是说将两个postinst 中的内容合并在一个新的postinst 中？
谢谢！

Closed 2021-11-28.

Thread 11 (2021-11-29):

`kernel-004-panel.patch` fails to apply

reostat, 2021-11-29:
While building A06 image according to instructions in `Create DevTerm A06 OS image from scratch` wiki, I noticed that `kernel-004-panel.patch` fails.

In order to stop the build process right at the moment it happens, run compile script with the following parameter:
```shell
sudo ./compile.sh EXIT_PATCHING_ERROR="yes"
```
Here's the output that I get:
```
... previous lines skipped
[ o.k. ] * [l][c] general-possibility-of-disabling-rk808-rtc.patch
[ o.k. ] * [l][c] general-rk808-configrable-switch-voltage-steps.patch
[ o.k. ] * [l][c] general-rkvdec_nv15.patch
[ o.k. ] * [l][c] general-rockchip-overlays.patch
[ o.k. ] * [l][c] general-rt5651-add-mclk.patch
[ o.k. ] * [u][c] kernel-001-a06-dts.patch
[ o.k. ] * [u][c] kernel-002-power.patch
[ o.k. ] * [u][c] kernel-003-audio.patch
[ warn ] * [u][c] kernel-004-panel.patch [ failed ]
[ error ] ERROR in function process_patch_file [ compilation.sh:960 ]
[ error ] Aborting due to [ EXIT_PATCHING_ERROR ]
[ o.k. ] Process terminated
```

reostat, 2021-11-30:
Alright, I dug it deeper and here's what panned out.

`Code/patch/armbian_build_a06/patch/kernel-004-panel.patch` introduces changes to the following files:
```
modify drivers/gpu/drm/panel/Kconfig
modify drivers/gpu/drm/panel/Makefile
create drivers/gpu/drm/panel/panel-cwd686.c
modify drivers/gpu/drm/rockchip/dw-mipi-dsi-rockchip.c
```
If applied as separate patches, all but the last one stick just fine. Further investigation shows that the changes in the last one are indeed already present in the latest v5.10.y kernel version; the changes were introduced - nearly verbatim - by commit id [43c2de10](https://git.kernel.org/pub/scm/linux/kernel/git/stable/linux.git/commit/?id=43c2de10) of _May 28th, 2021 (2021-05-28)_. Removing changes to `dw-mipi-dsi-rockchip.c` file from the patch make it work again.

Now, this is probably not critical since AFAIK when patch fails it fails hunk by hunk, not all together; that is, in this case all the relevant parts would still get applied and the panel is going to work with this kernel anyway. However, as Linux kernel evolves there could be other cases when critical parts of patches might get rejected during the build thus producing an image that either doesn't work or can even potentially damage the hardware. After all, by default Armbian build reports failed patches at `warn` level and doesn't stop the build; locating those fails after the fact requires sifting through the build logs.

In order to prevent this from happening, I suggest doing the following.

1. Enable `EXIT_PATCHING_ERROR="yes"` by default so the build fails early should any of the patches fail
2. Fix u-boot and kernel versions to the last ones known to compile without errors with current config, e.g. using `KERNELBRANCH` and 'BOOTBRANCH` flags. Changing these versions should be recommended for advanced users only.
3. In addition to that, it might be a good idea to publish Armbian version the configs and instructions were verified against.

Together it should provide stable enough foundation for reproducible builds.

@cuu please let me know what you think. I'm working on a more Armbian-ish and less manual way to build an image in a separate fork; if the above sounds reasonable I will include it into configuration.

cuu, 2021-12-04:
totally agreed
and learned a lot from you

right now we are dealing the A04 kernel for armbian
and if we done the A04 kernel ,we will try to   update the a06 patches and test
thanks very much

Closed 2021-12-05.

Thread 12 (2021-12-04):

Display panel driver questions

maxfierke, 2021-12-04:
Trying to figure out more about why the display panel does not come back up after sleep/suspend

@cuu do you have any more information about the CWD686 display and why this particular piece is disabled in the driver?

https://github.com/clockworkpi/DevTerm/blob/a900c2fff59573c42de4e2bd3974ad536ce82f6b/Code/patch/armbian_build_a06/patch/kernel-004-panel.patch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

Also, if there's any schematics or datasheets for the display that you could share, that would be very helpful! More details on the backlight driver would also be helpful too!

maxfierke, 2021-12-30:
This patchset fixes the display suspend/resume issue at the root of my question: https://patchwork.kernel.org/project/linux-rockchip/list/?series=554547 (issues with the Rockchip MIPI DSI driver)

Closed 2022-01-08.

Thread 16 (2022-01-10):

rastertocpi does not handle chinese text properly

HenryHu, 2022-01-10:
It seems like that the width of Chinese text is not calculated correctly when printing.
For example, try this: `echo 我能吞下玻璃而不伤身体敏捷的棕色狐狸跨过懒狗 | lp`
The first line in the output has text “我能吞下玻璃而不伤身”. Only left half of the last character is printed.
The second line has text “跨过懒狗”。
We can see that some text (“体敏捷的棕色狐狸”) is missing.
In general, it seems like that more Chinese characters than what can be printed are assigned to each line.

HenryHu, 2022-01-10:
Okay, it may not be a problem of rastertocpi; its input is already truncated, it seems like. From debug info of rastertocpi:
```
                      x                           xx            xx                                                                                                                          x                                       x
                xx    xxxx                       xxxxx          xxxx                                            xx                                          xx                              xxx                                     xxx
            xxxxxxx   xx    x                    xx             xx        xxx          x                       xxxx                                        xxxx                             xx                         x             xx        x
        xxxxxx        xx     xxx                xx      xx      xx       xxx           xxxxxxxxxxxxxxxxxxxxxxxxxxxxx         xxxxxxxxxxxxxxxxxxxxxxxxxxxxxxxxxxx               x            xx                        xxx            xx       xxx      x
   xxxxx   xx         xx      xxx              xx        xxx    xx     xxx                         xx                                        x                                xxxx x        xx        x      xxxxxxxxxxxxx  xxxxxxxxxxxxxxxxxxxxxx
           xx         xx       xx             xx          xxx   xx    xx                          xx                                         x                      xxxxxxxxxxxxxx xxxxxxxxxxxxxxxxxxxxx           xx                   x
           xx         xx       xx           xx     xxxxxxxxxxx  xx  xx                            xx                                         x                            xx       xx       xx      xxxx           xx            x     xxx
           xx         xx           x       xxxxxxxxxxxx     xx  xxx           x                   xx                x                        x                            xx       xx       xx      xx             xx       xxx   xxx  xx    xx
           xx         xx          xxx       xxx             x   xx           xx                  xx                xxx                       x                            xx       xx       xx     xx              xx       xxx     xxxx     xx
  xxxxxxxxxxxxxxxxxxxxxxxxxxxxxxxxxxxx                          xx           xx    xxxxxxxxxxxxxxxxxxxxxxxxxxxxxxxxxxxx                      x                            xx       xx       xx     x               xx       xx       xxxx    xx
           xx         xx                      x          xx     xx           xx                 xx       x                                   xx                           xx       xx       xx                     xx       xx     xx  xxx   xx
           xx         xx                      xxxxxxxxxxxxxx    xxx        xxxx                xx        xx                                  x  xx                        xx       xx       xx                     xx  xxx  xx    xx    xxx  xx
           xx         xx                      xx         xx      xxxxxxxxxxxxx                xx          xx                                 x    xxx                     xx  xx   xx       xx    xx         xxxxxxxxxxxxx  xx  xx       xx  xx
           xx          x        xx            xx         xx                                  xx            xx                                x      xxx             xxxxxxxxxxxxx  xxxxxxxxxxxxxxxxxx              xx       xxxxxxxxxxxxxxxxxxx
           xx          xx      xxxx           xx         xx     x                           xx              xxx                              x       xxxx            xx   xx       xx   x        xxx               xx       xx      xxx      xx
           xx    xxx   xx      xx             xxxxxxxxxxxxx     xxxx                       xx                 xxx                            x         xxx                xx       xx    x       xx                xx               xx      x
           xxxxxx      xx     xx              xx         xx     xx        xx              xxxx             xx  xxxxx                         x          xxx               xx       xx    x      xxx                xx      x       xxx        xx
         xxxxx         xx    xx               xx         xx     xx      xxxxx           xx  xxxxxxxxxxxxxxxxxx   xxxxxxx                     x           xx               xx       xx    xx     xx                 xx      xxxxxxxxxxxxxxxxxxxxxx
     xxxxxxxx           xx  xxx               xx         xx     xx     xxx             xx   xx              xx     xxx                       x                            xx       xx     x    xxx                 xx      xx      x          xx
  xxxxx    xx           xx xxx                xx         xx     xx   xxx             xx     xx              xx                               x                            xx       xx     xx   xx                  xx      xx     xx          xx
   xx      xx            x xx                 xxxxxxxxxxxxx     xx xxx             xx       xx              xx                               x                            xx    x  x       x  xx                   xx xxx  xx    xx     xx    xx
           xx            xxx                  xx         xx     xxx                         xx              xx                               x                            xxxxx   xx       xxxxx                 xxxxx     xx    xx      xx   xx
   xx xx x  x x
                                                                                       xxx      xx
                               x                                       x               xxx      xxx
                              xxxx                                    xxxx             xx       xx                              x     x
xxxxxxxxxxxxxxxxxxxxxxxxxxxxxxxxxxx    xxxxxxxxxxxxxxxxxxxxxxxxxxxxxxxxxxx             xx      xx               x               xx    x
               xx                                       xx                            xx       xx              xxxx             xx
               x                                        xx                            x       xxxxxxxxxxxxxxxxxxxxx             xx
              xx                                       xx                            xx       xx                                xx
              x                                       xxx                            x       xx      x                          xx
             x              x                         xxx                           xx       x       xxxx                       xxxxxxx
   xxxxxxxxxxxxxxxxxxxxxxxxxxxx                      xxxxx                          xxxx    x        xx                         xx
   xx      xx      xx       xxx                     xx xx                          x xx    xx        xx                         xx
   xx      xx      xx       xx                     xx  xx    xx                   xx xx    x         xx        x                xx
   xx      xx      xx       xx                    xx   xx      xx                 x  xx   x  xxx     xx       xxxx              xx
   xx      xx      xx       xx                   xx    xx       xxx              x   xx       xxx    xx        xxx              xxxxxxx
   xx      xx      xx       xx                  xx     xx         xx            x    xx              xx        xx               xx
   xx      xx      xx       xx                 xx      xx          xxx         x     xx              xx        xx               xx
   xx      xx      xx       xx                xx       xx           xxx              xx              xx        xx               xx
   xx      xx      xx       xx              xx         xx            xxxx            xx              xx        xx       xxx     xx
   xx      xx      xx       xx             xx          xx             xxxx           xx             xx         xx        xxx
   xx      xx      xx       xx            xx           xx              xxx           xx             xx        xx
   xx      xx      xx       xx          xx             xx               xx           xx             xx        xx
   xx      xx      xx       xx         x               xx                            xx            xx         xx
```

Closed 2022-01-10.

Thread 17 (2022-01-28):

Cover over the HDMI connector is a fraction too thick

wisze, 2022-01-28:
The cover over the HDMI port prevents a HDMI cable from making a proper connection. When the cable does not connect to the connector properly the external screen shows the raspberry pi splash screen, not the desktop.
The cover of the Devterm over the HDMI connector is just a fraction of a millimeter too thick to allow a proper connection.

Closed 2022-11-13.

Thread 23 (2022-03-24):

Merge A06 to armbian supported device

littlecxm, 2022-03-24:
reference https://github.com/armbian/build/issues/3564

Closed 2022-05-12.

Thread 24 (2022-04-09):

gearbox script shows hardcoded gpu governor instead of the current one.

Mihaylov93, 2022-04-09:
**Expected:**
```
> cat /sys/devices/platform/ff9a0000.gpu/devfreq/ff9a0000.gpu/governor
performance
```

**Current:**
```
> ./devterm-a06-gearbox

Current Status:
+-----------------------------------+-----------------+-----------+
|            Cortex-A53             |   Cortex-A72    | Mali-T860 |
+--------+--------+--------+--------+--------+--------+-----------+
| CPU 0  | CPU 1  | CPU 2  | CPU 3  | CPU 4  | CPU 5  |    GPU    |
+--------+--------+--------+--------+--------+--------+-----------+
| 408Mhz | 408Mhz | 408Mhz | 408Mhz |  OFF   |  OFF   |   200MHz  |
+--------+--------+--------+--------+--------+--------+-----------+
CPU Governor: schedutil    GPU Governor: simple_ondemand

```

**Responsible code:**
https://github.com/clockworkpi/DevTerm/blob/main/Code/A06/devterm-a06-gearbox#L189

```print("CPU Governor: %s    GPU Governor: %s" % (self.get_cpu_gov(), self.gear["gpu_gov"]))```

**Solution:**
Read it from the filesystem

```
    @property
    def gpu_gov(self) -> str:
        with open(
            "/sys/devices/platform/ff9a0000.gpu/devfreq/ff9a0000.gpu/governor", "r"
        ) as gov_file:
            return gov_file.read().strip()
```

Closed 2022-04-20.

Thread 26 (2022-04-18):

Ascii cinema for image builds

NeccoNeko, 2022-04-18:
Could you create Asciicinema recordings (or maybe even just plain YouTube recordings) of the image build process?

https://github.com/clockworkpi/DevTerm/wiki/Create-DevTerm-A06-OS-image-from-scratch

The wiki document lacks some information, which makes following the process difficult.

NeccoNeko, 2022-04-20:
Looking for full instructions, end to end, on building an image for my A06. The wiki document I linked is missing information and steps on building the base image, it errors out during compile.sh.

I'm hoping, at the very least, to just get a recording of a beginning to end build so I can put together a process for automating it.

If, instead, a working wiki document can be provided that would work as well. I just figured that a screen recording would be easier to provide.

cuu, 2022-04-20:
>  it errors out during compile.sh.

what  errors?

could you paste the output of the errors here ?

and also make sure to do the git hard reset step

> git reset --hard 43d179914ae9e1ebb5d72315d9f9f68f5fb3e330

the armbian building system is always updating,so errors might happen

NeccoNeko, 2022-04-20:
> what errors? ... could you paste the output of the errors here ?

You can see an example of errors on the ClockworkPi Forum:

https://forum.clockworkpi.com/t/does-anyone-have-a-dockerfile-for-building-the-devterm-image/8325/5

> and also make sure to do the git hard reset step

I did.  Here are the exact steps I performed (based on information from the wiki article and trial and error):

1. Installed ubuntu:21.04
2. Performed `apt update`
3. Installed the following packages
    * `apt install -y git dialog psmisc acl uuid-runtime curl gnupg gawk apt-utils lsb-release`
4. Checked out the required repositories:
    * `git clone https://github.com/armbian/build.git`
    * `git clone https://github.com/clockworkpi/DevTerm.git`
5. Performed a reset to the specified commit for the armbian build repository:
    * `cd build ; git reset --hard 43d179914ae9e1ebb5d72315d9f9f68f5fb3e330`
6. Created the required userpatches directory (this step was missing)
    * `mkdir -p userpatches/kernel/rockchip64-current/`
    * `mkdir -p userpatches/u-boot/u-boot-rockchip64-mainline/`
7. Applied the armbian.patch file from the DevTerm repository:
    * `git apply ../DevTerm/Code/patch/armbian_build_a06/patch/armbian.patch`
8. Copied the user patches into place:
    * `cp ../DevTerm/Code/patch/armbian_build_a06/patch/kernel*.patch userpatches/kernel/rockchip64-current/`
    * `cp ../DevTerm/Code/patch/armbian_build_a06/patch/uboot*.patch userpatches/u-boot/u-boot-rockchip64-mainline/`
9. Copied the config file into place:
    * `cp ../DevTerm/Code/patch/armbian_build_a06/patch/clockworkpi-a06.conf config/boards/`
10. Then attempted the armbian build process:
    * `./compile.sh`

No information was provided as to what to select when executing the build script.  A UI pops up asking questions, so I've had to guess my way through it and so far have ended up with the following so I don't have to interact with the UI to set options:

    BOARD=clockworkpi-a06
    # I've tried both 'legacy' and 'current' for the following:
    BRANCH=legacy
    RELEASE=21.04
    # Left the following blank to keep things simple
    DESKTOP_APPGROUPS_SELECTED=
    DESKTOP_ENVIRONMENT=xfce
    DESKTOP_ENVIRONMENT_CONFIG_NAME=config_base
    BUILD_MINIMAL=no
    BUILD_DESKTOP=yes
    KERNEL_ONLY=no
    KERNEL_CONFIGURE=no
    PROGRESS_LOG_TO_FILE=yes
    NO_APT_CACHER=yes

The image fails to build, specifically when trying to build the patches copied over.  I'll dig up the latest failed logs tomorrow to share (getting late here).

In the mean time, if you can review the steps I performed above and provide feedback/corrections that would be awesome.

Or, if it wouldn't be too much to ask, a screen recording of the build from beginning to end should help in addressing the above, and any other possible gaps in the documentation.

sboger, 2022-04-20:
I have also attempted the build on a Linux Mint 20.3 laptop using the docker method. Same exact steps as above, but I run:
./compile.sh docker

The build fails at the kernel level. The kernel patches in /userpatches fail to apply.

sboger, 2022-04-20:
Here's a complete log of a failed build:

Log:
[devterm-build.log](https://github.com/clockworkpi/DevTerm/files/8525357/devterm-build.log)

Commands:
```
git clone https://github.com/armbian/build.git
git clone https://github.com/clockworkpi/DevTerm.git
cd build
git reset --hard 43d179914ae9e1ebb5d72315d9f9f68f5fb3e330
git apply ../DevTerm/Code/patch/armbian_build_a06/patch/armbian.patch
git apply ../DevTerm/Code/patch/armbian_build_a06/patch/armbian_mirror.patch
mkdir -p userpatches/kernel/rockchip64-current/
mkdir -p userpatches/u-boot/u-boot-rockchip64-mainline/
cp -f ../DevTerm/Code/patch/armbian_build_a06/patch/kernel*.patch userpatches/kernel/rockchip64-current/
cp -f ../DevTerm/Code/patch/armbian_build_a06/patch/uboot*.patch userpatches/u-boot/u-boot-rockchip64-mainline/
cp -f ../DevTerm/Code/patch/armbian_build_a06/patch/clockworkpi-a06.conf config/boards/
./compile.sh docker BOARD=clockworkpi-a06 BRANCH=current RELEASE=hirsute BUILD_MINIMAL=no BUILD_DESKTOP=yes KERNEL_ONLY=no KERNEL_CONFIGURE=no DESKTOP_ENVIRONMENT=xfce DESKTOP_ENVIRONMENT_CONFIG_NAME=config_base COMPRESS_OUTPUTIMAGE=sha,gpg,img
```

sboger, 2022-04-20:
As a comparison, I tried compiling directly on the A06. Same as above, just ./compile.sh instead of ./compile.sh docker.

Same patch failures, same build error.

NeccoNeko, 2022-04-21:
@cuu have you seen the above?

NeccoNeko, 2022-04-21:
I've attached logs and an asciicinema cast file from my attempt to build Armbian for the A06, using the instructions from the wiki article.

[build_fail.cast.gz](https://github.com/clockworkpi/DevTerm/files/8535255/build_fail.cast.gz)
[debug_logs.tar.gz](https://github.com/clockworkpi/DevTerm/files/8535256/debug_logs.tar.gz)

NeccoNeko, 2022-04-21:
I've changed the title of this issue.

cuu, 2022-04-22:
after a little digging

first
the kernel version has changed even we set the hard reset hash

what we use in a06 stock image is 5.10.60 and now it is 5.10.100 today

so
```
[ warn ] * [u][c] kernel-004-panel.patch [ failed ]
[ o.k. ] * [u][c] kernel-005-backlight.patch
[ warn ] * [u][c] kernel-006-panel.patch [ failed ]
```
these two clockworkpi patches won't work even if the compile went through

second:
to check the compilation.log,this is real error output log

```
output/debug/compilation.log
````

`
	== u-boot make clockworkpi-a06-rk3399_defconfig ==

	== u-boot make u-boot-dtb.bin ==

.config:1793:warning: override: reassigning to symbol BOOTDELAY
tools/imx8mimage.c: In function ‘copy_file.constprop’:
tools/imx8mimage.c:291:7: warning: ‘write’ reading 5 bytes from a region of size 4 [-Wstringop-overflow=]
  291 |   if (write(ifd, (char *)&zero, 4 - tail) != 4 - tail) {
      |       ^~~~~~~~~~~~~~~~~~~~~~~~~~~~~~~~~~~
In file included from tools/imagetool.h:21,
                 from tools/imx8mimage.c:9:
/usr/include/unistd.h:367:16: note: in a call to function ‘write’ declared with attribute ‘read_only (2, 3)’
  367 | extern ssize_t write (int __fd, const void *__buf, size_t __n) __wur
      |                ^~~~~
tools/imx8image.c: In function ‘copy_file.constprop’:
tools/imx8image.c:414:7: warning: ‘write’ reading 5 bytes from a region of size 4 [-Wstringop-overflow=]
  414 |   if (write(ifd, (char *)&zero, 4 - tail) != 4 - tail) {
      |       ^~~~~~~~~~~~~~~~~~~~~~~~~~~~~~~~~~~
In file included from ./tools/imagetool.h:21,
                 from include/imx8image.h:13,
                 from tools/imx8image.c:8:
/usr/include/unistd.h:367:16: note: in a call to function ‘write’ declared with attribute ‘read_only (2, 3)’
  367 | extern ssize_t write (int __fd, const void *__buf, size_t __n) __wur
      |                ^~~~~
arch/arm/mach-rockchip/rk3399/rk3399.c: In function ‘board_debug_uart_init’:
arch/arm/mach-rockchip/rk3399/rk3399.c:125:36: warning: unused variable ‘gpio’ [-Wunused-variable]
  125 |  struct rockchip_gpio_regs * const gpio = (void *)GPIO0_BASE;
      |                                    ^~~~

	== kernel ==

scripts/Makefile.lib:8: 'always' is deprecated. Please use 'always-y' instead
arch/arm64/boot/dts/rockchip/overlay/rockchip-spi-spidev.dts:22.11-27.6: Warning (spi_bus_reg): /fragment@1/__overlay__/spidev: SPI bus unit address format error, expected "0"
arch/arm64/boot/dts/rockchip/overlay/rockchip-spi-spidev.dts:36.11-41.6: Warning (spi_bus_reg): /fragment@2/__overlay__/spidev: SPI bus unit address format error, expected "0"
arch/arm64/boot/dts/rockchip/overlay/rockchip-spi-spidev.dts:50.11-55.6: Warning (spi_bus_reg): /fragment@3/__overlay__/spidev: SPI bus unit address format error, expected "0"
arch/arm64/boot/dts/rockchip/overlay/rockchip-spi-spidev.dts:64.11-69.6: Warning (spi_bus_reg): /fragment@4/__overlay__/spidev: SPI bus unit address format error, expected "0"
arch/arm64/boot/dts/rockchip/rk3399-tinker-2.dts:401.23-422.4: Warning (i2c_bus_reg): /i2c@ff3c0000/vdd_cpu_b: I2C bus unit address format error, expected "60"
arch/arm64/boot/dts/rockchip/rk3399-tinker-2.dts:497.19-518.4: Warning (i2c_bus_reg): /i2c@ff3d0000/vdd_gpu: I2C bus unit address format error, expected "60"
drivers/video/fbdev/core/fbcon.c: In function ‘fbcon_scrolldelta’:
drivers/video/fbdev/core/fbcon.c:2998:16: error: ‘struct fbcon_display’ has no member named ‘scrollmode’; did you mean ‘yscroll’?
  switch (disp->scrollmode) {
                ^~~~~~~~~~
                yscroll
make[4]: *** [scripts/Makefile.build:280: drivers/video/fbdev/core/fbcon.o] Error 1
make[4]: *** Waiting for unfinished jobs....
make[3]: *** [scripts/Makefile.build:497: drivers/video/fbdev/core] Error 2
make[2]: *** [scripts/Makefile.build:497: drivers/video/fbdev] Error 2
make[1]: *** [scripts/Makefile.build:497: drivers/video] Error 2
make: *** [Makefile:1822: drivers] Error 2
make: *** Waiting for unfinished jobs....
`

after googled a bit

It may be is a armbian build system issue

looks like we need update the armbian build system to fix this kernel compilation issue

or manually fix other armbian patches for this newer kernel

cause this commit hash we set is only for kernel 5.10.60

and armbian continues to update kernel version

so RIght now, you can just follow the wiki the produce the image as we want

you need to fix it manually by yourself,update the patches to fit kernel updates

looks like manjaro is a better choice

NeccoNeko, 2022-04-22:
@cuu Thank you very, very much for reviewing and responding.

The wiki is incomplete.  It lacks instructions for creating directories to copy the patches into, plus the options to pick for compile.sh.  One of the options (board version) can't be set from the config UI that loads up, so it needs to be set manually at the CLI.

As for it being outdated, perhaps it can be updated, at the very least a warning that the instructions no longer work?  That way no one else spends time on something that won't work, unless they want to either 1) manually fix the kernel patch files to work with the latest kernel or 2) dig into the guts of the Armbian build script configuration files to set a fixed kernel version.

Again, thank you very much for your time on this.  It's greatly appreciated.

sboger, 2022-04-22:
Fixed. Create file build/userpatches/lib.config

lib.config:
`
KERNELBRANCH='tag:v5.10.60'
`

I've created pull-request https://github.com/clockworkpi/DevTerm/pull/28. It adds the file and improves the readme.

oscillot, 2022-04-23:
>

omg i was right behind you I just didn't have `tag:`

littlecxm, 2022-05-12:
merged to armbian master now, you can try this https://github.com/armbian/build/commit/1f54bc33b8dda678de473d7d006a9a7f6ab0b86b

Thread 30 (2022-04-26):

Printing PNGs - DevTerm Kit A06 series 4GB

andrewdamelio, 2022-04-26:
So I was able to print PNG files from FireFox (Cltr-P /Black&White) with my new DevTerm, no problem.

I ran a software update and now the DevTerm printer will not print PNGs, the status just says HELD. I can print regular text files still but no longer PNGs.

Any ideas how to revert/fix?

[updated] - my sys specs
```
cpi@clockworkpi-a06:~$ neofetch
                                 cpi@clockworkpi-a06
                                 -------------------
      █ █ █ █ █ █ █ █ █ █ █      OS: Armbian hirsute (21.08.0-trunk) aarch64
     ███████████████████████     Host: Clockworkpi A06
   ▄▄██                   ██▄▄   Kernel: 5.10.60-rockchip64
   ▄▄██    ███████████    ██▄▄   Uptime: 3 hours, 5 mins
   ▄▄██   ██         ██   ██▄▄   Packages: 1779 (dpkg), 2 (snap)
   ▄▄██   ██         ██   ██▄▄   Shell: bash 5.1.4
   ▄▄██   ██         ██   ██▄▄   Resolution: 1280x480
   ▄▄██   █████████████   ██▄▄   DE: Xfce 4.16
   ▄▄██   ██         ██   ██▄▄   Theme: Numix [GTK2/3]
   ▄▄██   ██         ██   ██▄▄   Icons: LoginIcons [GTK2], Adwaita [GTK3]
   ▄▄██   ██         ██   ██▄▄   Terminal: x-terminal-emul
   ▄▄██                   ██▄▄   CPU: (4) @ 1.008GHz
     ███████████████████████     Memory: 652MiB / 3863MiB
      █ █ █ █ █ █ █ █ █ █ █

```

andrewdamelio, 2022-04-29:
fix here
https://forum.clockworkpi.com/t/thermal-printer-does-not-connect/7782/39

Closed 2022-04-29.

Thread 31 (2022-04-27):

CM3 shutdown doesn't kill +5V USB power.

markatlnk, 2022-04-27:
I don't believe it affects other CPU modules, just the Compute Module 3.

It looks like it shuts down, but the USB is still powered and it is pulling about 43mA from the batteries. After shutting down, if I take out the batteries and put them back in, current drops to 60uA closer to what I would expect.

Posting this on Discord, looks like other have also had this issue.

cuu, 2022-05-06:
how about sudo halt -p ?

markatlnk, 2022-05-06:
The power button doesn't close it down and shutdown -h now doesn't either.   The -P option is the default and shuts down every other pi I own. I only noticed this when I had an arduino plugged in and its lights were still blinking when I shut down the system. I had noticed several times when I pulled it out of my bag after a few days that the batteries were dead. Always thought something pushed the power button in my bag.  Shutdown is actually part of systemctl and I attempted a few options with that also. So far the only thing that works is momentary removal of batteries. Just a second or two will do it.

andrwj, 2022-09-16:
Then this problem is caused by hardware problem, can ClockworkPi show some guidelines to appy to CM3 DevTerm?

markatlnk, 2022-09-16:
Yes it is a hardware problem, but a minor one that can be resolved with changing the value of one resistor. These parts are really small so you do need a bit of experience with that. I teach Electrical Engineering and just happen to have a full SMT rework setup on my bench so it wasn't that difficult for me to do that. Because I wanted to lower the resistance of the value on the board, I chose to not remove the old part and just stick another part directly on top of it. It can be done with a microscope and a really fine tipped soldering iron. Make sure you use a drop of flux on there and if you use the no-clean type, you can just leave it. For those with better eyes than mine, you might get by with one of those magnifying glasses.  Hope that helps.  I think they used 0402 parts, which is way smaller than I typically work with, so I actually tacked an 0805 part off one side and a really tiny wire to connect the other side. Bit of a kludge, but it is still working just fine.  The device can sit for weeks without any battery drain.

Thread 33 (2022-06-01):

Failure to boot after upgrading R-01 OS

jw-0, 2022-06-01:
Hi, myself and others in the community have encountered an issue with the R-01 OS. If you run a full update of the OS packages with 'apt update && apt upgrade', once you attempt to reboot the OS will not start back up again and you will be left with a black screen.  The power light does come on down the bottom but nothing happens on screen and the OS does not boot back in and you cannot SSH in. The only remedy is to re-flash the SD card with the OS image available on [the site](http://dl.clockworkpi.com/). I tested it again after re-flashing SD card with the downloaded image and got the same result, it seems to be an issue with both the shipped OS on the SD card and the provided OS image. Further details: https://forum.clockworkpi.com/t/r-01-screen-wont-turn-on-again-after-shutdown/8527/6

I hope I am submitting the issue to the correct location, please let me know if elsewhere is more appropriate, thank you!

cuu, 2022-06-01:
sorry to hear that
but R01  use the devel branch of ubuntu(because we had to , for latest mesa to work with)

it has risks to upgrade, according your feed back ,it seems that the kernel has been misplaced

so mount the sd card(with R01 os)  on a PC (like Linux )

then go into the **boot partition** of the sd card

you will see
```
extlinux.conf
extlinux.conf.cpi.bak
```
replace extlinux.conf  with extlinux.conf.cpi.bak

the **extlinux.conf.cpi.bak** is for this kind of situation

the apt upgrade will mess up the content of exlinux.conf

jw-0, 2022-06-01:
Thanks this worked, appreciate it

nzmichaelh, 2022-06-08:
FWIW, `/boot/exlinux/extlinux.conf` is updated by u-boot-update. It looks like you can turn off automatic updating by adding `U_BOOT_UPDATE=false` to `/etc/default/u-boot`.

cuu, 2022-06-08:
> FWIW, `/boot/exlinux/extlinux.conf` is updated by u-boot-update. It looks like you can turn off automatic updating by adding `U_BOOT_UPDATE=false` to `/etc/default/u-boot`.

great!

andypiper, 2022-06-09:
Could you say more about the Mesa issue, please? I'd like to be able to install libsdl2-dev but that seems to have a conflict caused by the version of Mesa (or something else in the graphics stack).

What's the specific change to `extlinux.conf` that causes the boot failure?

thomasdstewart, 2022-06-09:
The official image leaves the Ubuntu RISC V kernels installed and after they get upgraded u-boot-update runs, which overwrites the extlinux.conf. Much like on a x86 system installing a new kernel updates the grub config file. The u-boot-update run makes a guess at which kernels you want to use, makes a menu to let you pick them all (you don't see the menu unless you see u-boot output in the debug uart) of course it assumes you want the latest version of linux, which does not boot. If you look at the content of the extlinux.conf after a u-boot-update run and the extlinux.conf.cpi.bak you can see they are completely different, as u-boot does not know about any of the custom allwinner d1 options. Probably the best quick option is setting that U_BOOT_UPDATE=false. The correct way would be to package the devterm r-01 kernel properly and understand how to integrate with u-boot-update more gracefully.

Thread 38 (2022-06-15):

Remove the devterm-fan-temp-daemon-rpi package from the R01 build

andypiper, 2022-06-15:
Edit https://github.com/clockworkpi/DevTerm/wiki/Create-DevTerm-R01-OS-image-from-scratch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

Remove devterm-fan-temp-daemon-rpi
This package is specific to the Raspberry Pi and will not work on the R01 core.

cuu, 2022-06-24:
done

Closed 2022-06-24.

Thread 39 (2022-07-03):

Would this module work in a DevTerm?

rog77, 2022-07-03:
https://github.com/wuxx/icesugar-pro

Not sure of the connector compatability...

The idea would be to use something like Litex to generate SoC with appropriate peripheral controllers.

Sorry if this is off topic, or out of scope.

cuu, 2022-07-10:
One thing I can confirm is this board can be plugged into DT
But I am not sure it can run under DT
if all the GPIO is like as same as CM3, then there is a good chance that it will work

rog77, 2022-07-15:
https://github.com/wuxx/Colorlight-FPGA-Projects#ddr2-sodimm-200p

I compared the CM pinout to the above, and alas it it not the same. Thanks for your response - it seemed like an idea, but it looks like it is not to be.

Closed 2022-07-15.

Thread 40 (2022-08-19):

Fan not working on CM4 64bit version

btyh17mxy, 2022-08-19:
I have change the MAX_TEMP to 60 in  /usr/local/bin/temp_fan_daemon.py file and restarted it, then got cpu temp over 70 but the fan still not running.

andypiper, 2022-09-04:
There are a number of issues here:

- The service still wants to use Python 2, which is obsolete (this is also unnecessary since the script has no Python 2 dependency)
- `/usr/local/bin/temp_fan_daemon.py` refers to `/opt/vc/bin/vcgencmd` which does not exist in Bullseye (this should be `/usr/bin/vcgencmd`
- It assumes that the fan is at GPIO 17, but I've tried manually switching GPIO 17 on and off and it has no effect on the fan.
 - the [wiki seems to say that the GPIO map is different on the CM4](https://github.com/clockworkpi/DevTerm/wiki/Devterm-CM4-GPIO-map) but it does not list "old" 17 so it is not clear whether this should still be used.

At the moment, the DevTerm fan package will simply not work on the CM4.

andypiper, 2022-09-04:
This package should not be required if Raspberry Pi OS is being used - fan control is part of `raspi-config`. If we know the GPIO to use this can do the work without a Python script sleeping in the background.

cuu, 2022-09-05:
thanks
the package  has upgraded

```
sudo apt update
sudo apt install devterm-fan-temp-daemon-cm4 -y
```

andypiper, 2022-09-06:
I've now removed the `devterm-fan-temp-daemon-cm4` package. I'm using the built-in Raspberry Pi OS settings to manage the fan and thermals:

In `raspi-config` -> Option 4 Performance -> Option 4 Fan
Yes, you want the fan control.
Fan on GPIO 17
Your choice of temperature threshold (minimum value is 60)

Then reboot.

andypiper, 2022-09-06:
@btyh17mxy you can try this:

- switch off the fan control service temporarily (to confirm that the GPIO works)
 - `systemctl stop devterm-fan-temp-daemon-cm4`

- check GPIO 17
 - `sudo gpio readall`
 - 17 should be set to OUT, Low (probably)
 - `sudo gpio toggle 17` will then toggle the power / set it to High, which should turn the fan on.

That should confirm whether the fan works in general.

btyh17mxy, 2022-09-07:
@andypiper  according to [wiki as you mentioned](https://github.com/clockworkpi/DevTerm/wiki/Devterm-CM4-GPIO-map) , the gpio pin for fan on CM4 should be 17. But the [temp_fan_daemon.py](https://github.com/clockworkpi/DevTerm/blob/main/Code/devterm_fan_daemon_rpi/temp_fan_daemon.py) seems got it wrong (still using 41).

so, I got the fan back to work by modify the `/usr/local/bin/temp_fan_daemon.py` file change gpio from 41 to 17 and `systemctl restart devterm-fan-temp-daemon`.

andypiper, 2022-09-07:
They fixed this in the -cm4 version, that script is from the -rpi version.

You do not actually need this extra code running (it wakes up every second to check the temperature) - you can use the built-in settings instead.

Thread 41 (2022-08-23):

"hacked keyboard firmware" commits

andypiper, 2022-08-23:
What are these for please?

[add hacked keyboard stm32duino bootloader files](https://github.com/clockworkpi/DevTerm/commit/548957a344f35e199661954fc35074390f7249e8)

@[cuu](https://github.com/clockworkpi/DevTerm/commits?author=cuu)
cuu committed 2 days ago

[add hacked keyboard firmware](https://github.com/clockworkpi/DevTerm/commit/7f8165ee80e9af1f8510fe340b2c64286d842dee)

cuu, 2022-08-24:
https://forum.clockworkpi.com/t/keyboard-stuck-in-bootloader-mode/8830/16

Closed 2022-08-24.

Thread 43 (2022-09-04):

CM4 packages cause Python 2 to be installed

andypiper, 2022-09-04:
The packages `devterm-audio-patch` and `devterm-fan-temp-daemon-cm4` have an (invalid / incorrect) dependency on python2, which causes several obsolete Python packages to be installed.

These should be edited to change `/usr/bin/python2` to `/usr/bin/python3` in the `.service` files, and have the python2 dependency updated to python3 in the the APT/DEB packaging.

cuu, 2022-09-05:
done

andypiper, 2022-09-05:
Thanks for fixing the packaging. Can you also check issue #40 and #42 and confirm the GPIO for the fan when using the CM4. The fan-temp-daemon is probably not needed but we would need to know which GPIO switches it on and off.

cuu, 2022-09-05:
it is the 17
and with upgraded  fan-temp-daemon,i've checked that the fan can work , I just set MAX_TEMP to 50 in py code,then the fan runs

if you can not run the fan with 17 GPIO,maybe is because your wiringpi library is not for  devterm cm4

try the devterm cm4 wiringpi library

andypiper, 2022-09-06:
OK thank you I will recheck this.

andypiper, 2022-09-06:
OK cool - confirmed the fan is working here.

fei20th, 2024-03-28:
> The packages `devterm-audio-patch` and `devterm-fan-temp-daemon-cm4` have an (invalid / incorrect) dependency on python2, which causes several obsolete Python packages to be installed.
>
> These should be edited to change `/usr/bin/python2` to `/usr/bin/python3` in the `.service` files, and have the python2 dependency updated to python3 in the the APT/DEB packaging.

where are those .service files located?

Closed 2022-09-06.

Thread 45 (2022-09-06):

Enable CM4 external antenna

andypiper, 2022-09-06:
The CM4 has a wireless chip with internal antenna, plus a U.FL connector for an external antenna. The CM4 core carrier board comes with an external antenna to connect to the U.FL connector on the CM4 👍🏻

The current v0.1 image for the CM4 board (64-bit) does not *enable* the external antenna.

It's an easy fix. In `/boot/config.txt` set

```
dtparam=ant2
```

Source information [here](https://www.jeffgeerling.com/blog/2022/enable-external-antenna-connector-on-raspberry-pi-compute-module-4)

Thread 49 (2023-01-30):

Hard-coded scroll wheel

pete, 2023-01-30:
I was having issues disabling the middle-click scrolling; tweaking it with xinput wasn't helping.  The culprit appears to be this change:  https://github.com/clockworkpi/DevTerm/commit/b1370d2124319e76900c6ca58bd441410b2278a0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 .    I am using some software (p9p acme, drawterm, Inferno) that actually doesn't function properly if holding middle-click forces scrolling, so I wanted to map a button to toggle it in my window manager.

Since it's possible to do in software (something like `xinput --set-prop 'ClockworkPI DevTerm Mouse' 'libinput Button Scrolling Button' 2`), it's probably better to leave this out of the firmware.  If it's in the firmware, it can't be disabled in software.

pete, 2023-01-30:
I did manage to verify that it works if I reflash to the 0.1 firmware.  (Though `ttyACM0` was hard-coded, so I had to fiddle with it a while to make it point at `ttyACM1`; a different board was eating the `ttyACM0` slot.)

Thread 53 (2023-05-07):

DevTerm CM4 64Bit

hb121280, 2023-05-07:
I used the adapter for my CM4 module, installed the 64Bit DevTerm OS. The device boots up fine, Display is working, showing the welcome message (“Welcome to Raspberry Pi Desktop! Before you start using…”).
Unfortunately neither the track ball nor the keyboard seems to be working.
Anybody experienced this before?
Does anybody have an idea how to proceed (apart from rebooting, already did this).

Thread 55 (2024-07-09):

Failed to apply devterm CM3 patch

meeeo, 2024-07-09:
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
I followed this: https://github.com/clockworkpi/DevTerm/tree/main/Code/patch/cm3

meeeo, 2024-07-10:
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
It seems that I have patched that directory, but fortunately there is a copy, now it’s okay

Closed 2024-07-10.

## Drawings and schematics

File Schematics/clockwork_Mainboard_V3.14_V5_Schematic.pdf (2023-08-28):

# POWER

# AUDIO

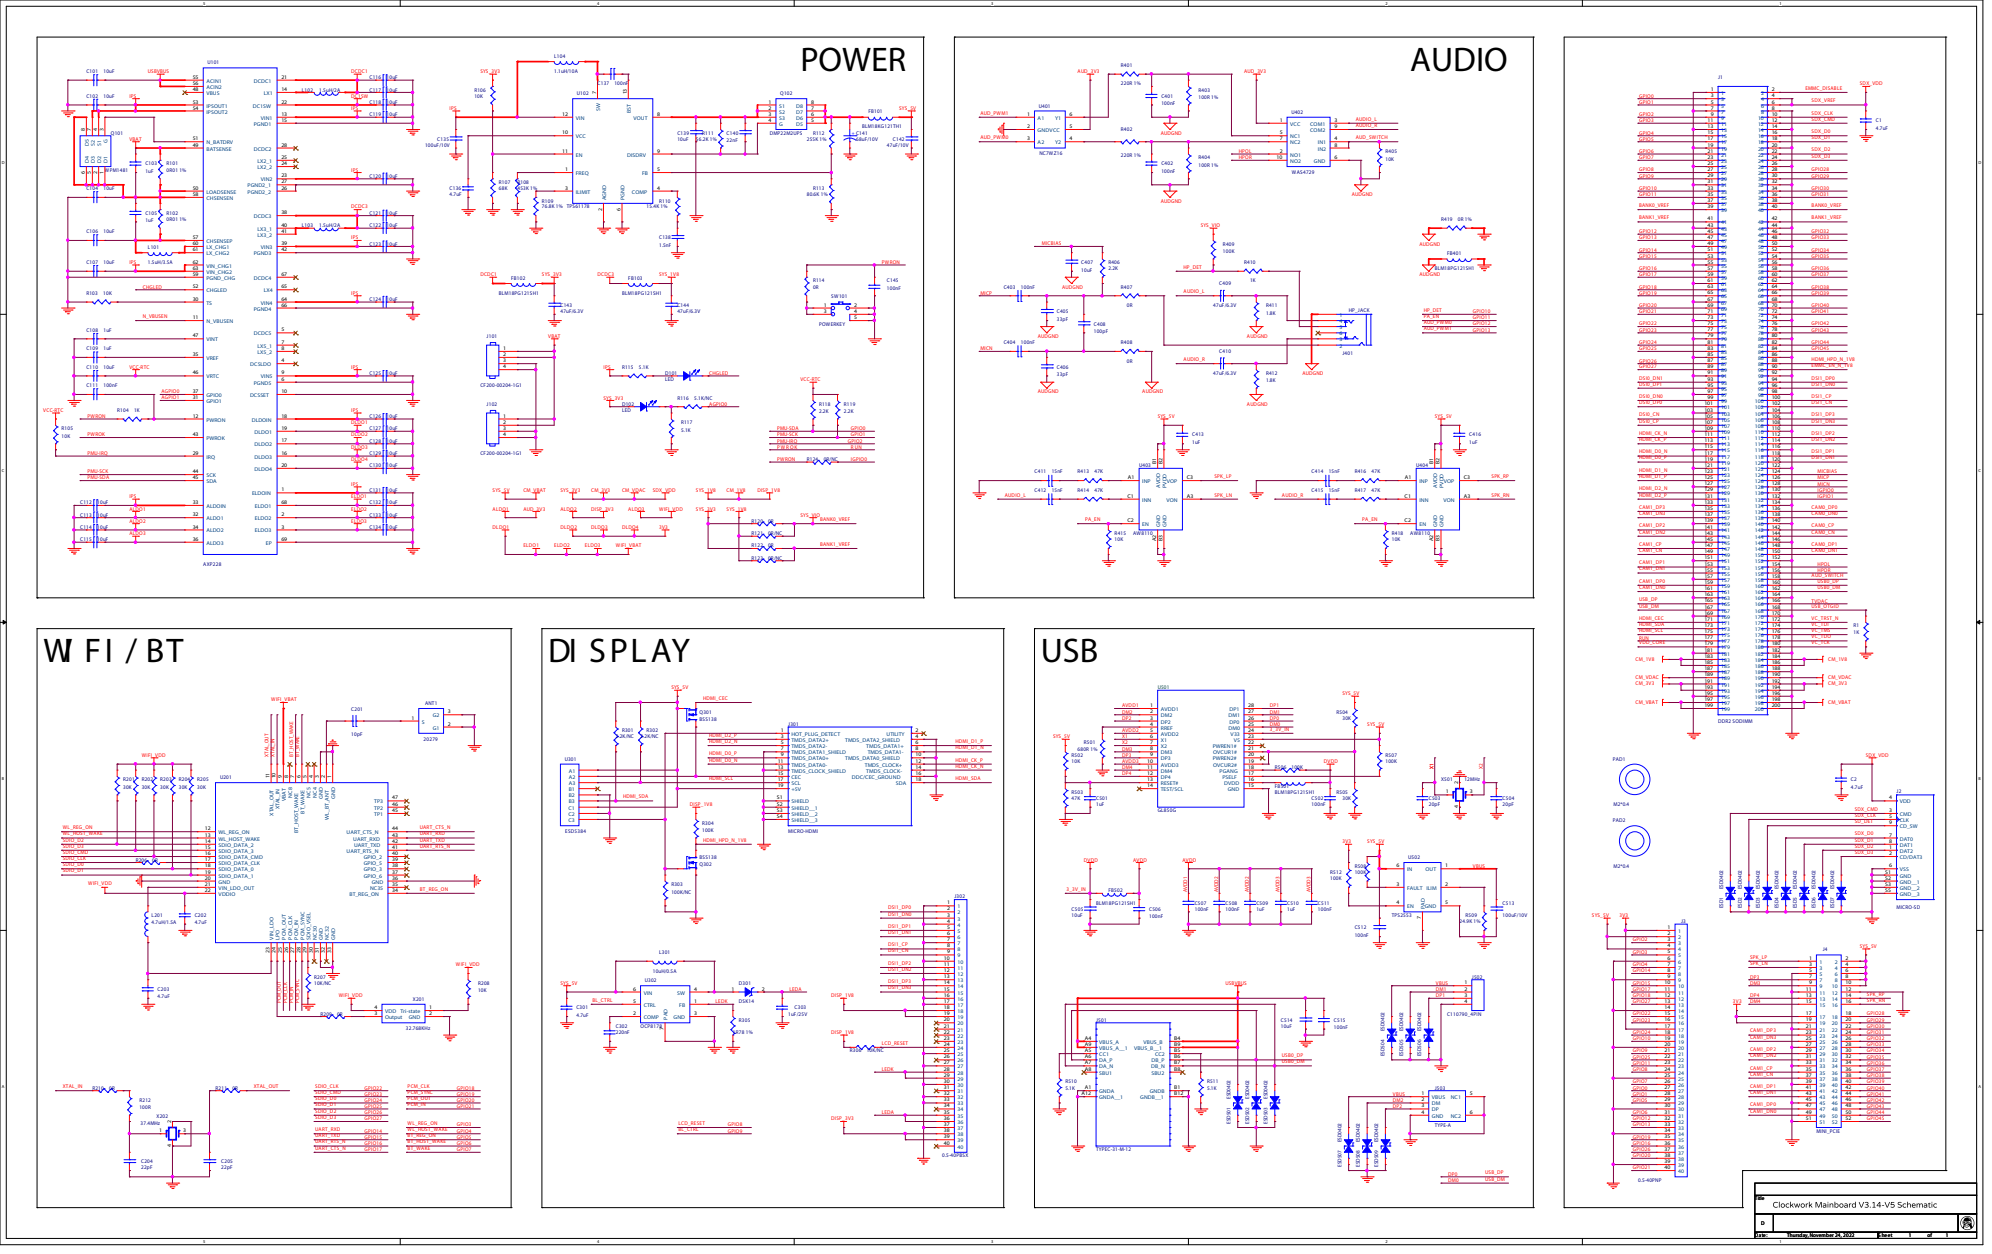
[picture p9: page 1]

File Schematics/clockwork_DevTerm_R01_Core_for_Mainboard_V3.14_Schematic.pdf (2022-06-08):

# POWER

R1 R2

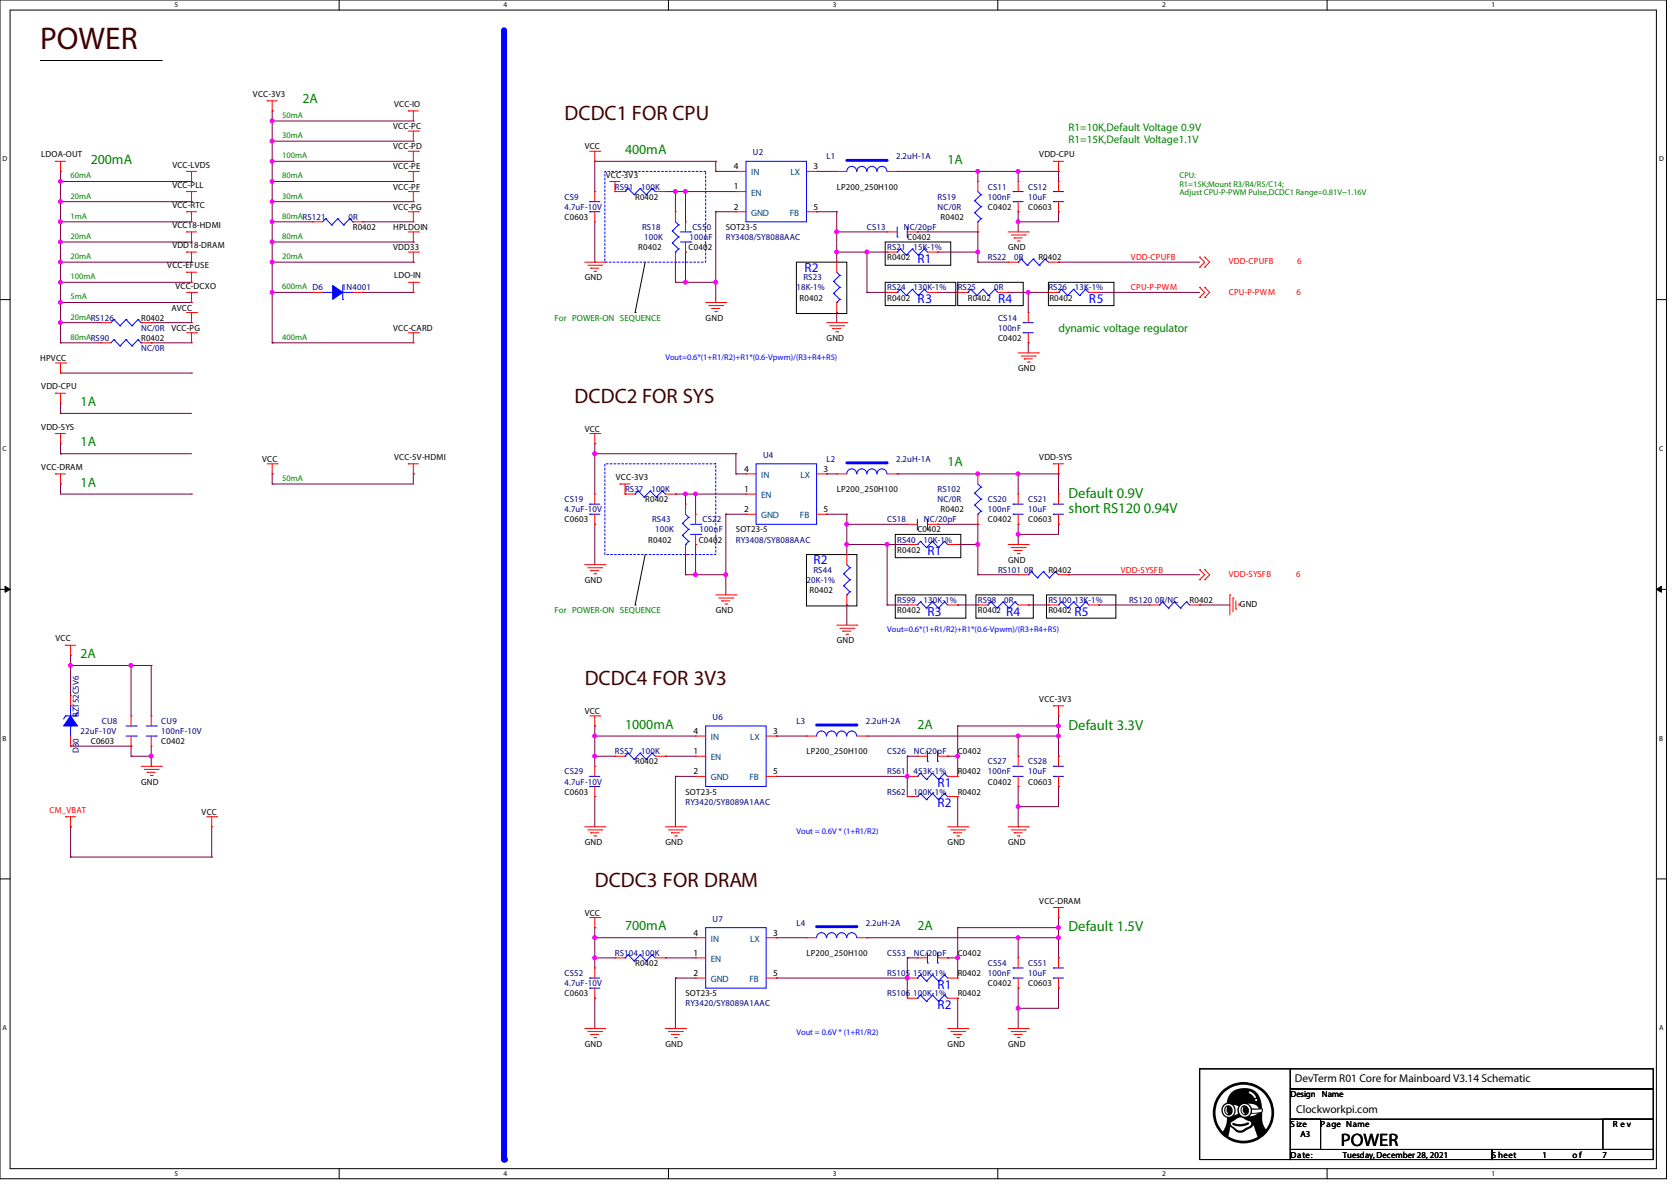
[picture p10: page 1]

CPU:
R1=15K;Mount R3/R4/R5/C14;
Adjust CPU-P-PWM Pulse,DCDC1 Range=0.81V~1.16V

For POWER-ON SEQUENCE

DevTerm R01 Core for Mainboard V3.14 Schematic
Design Name
Clockworkpi.com
POWER A3

# SOC SYS

# SYS

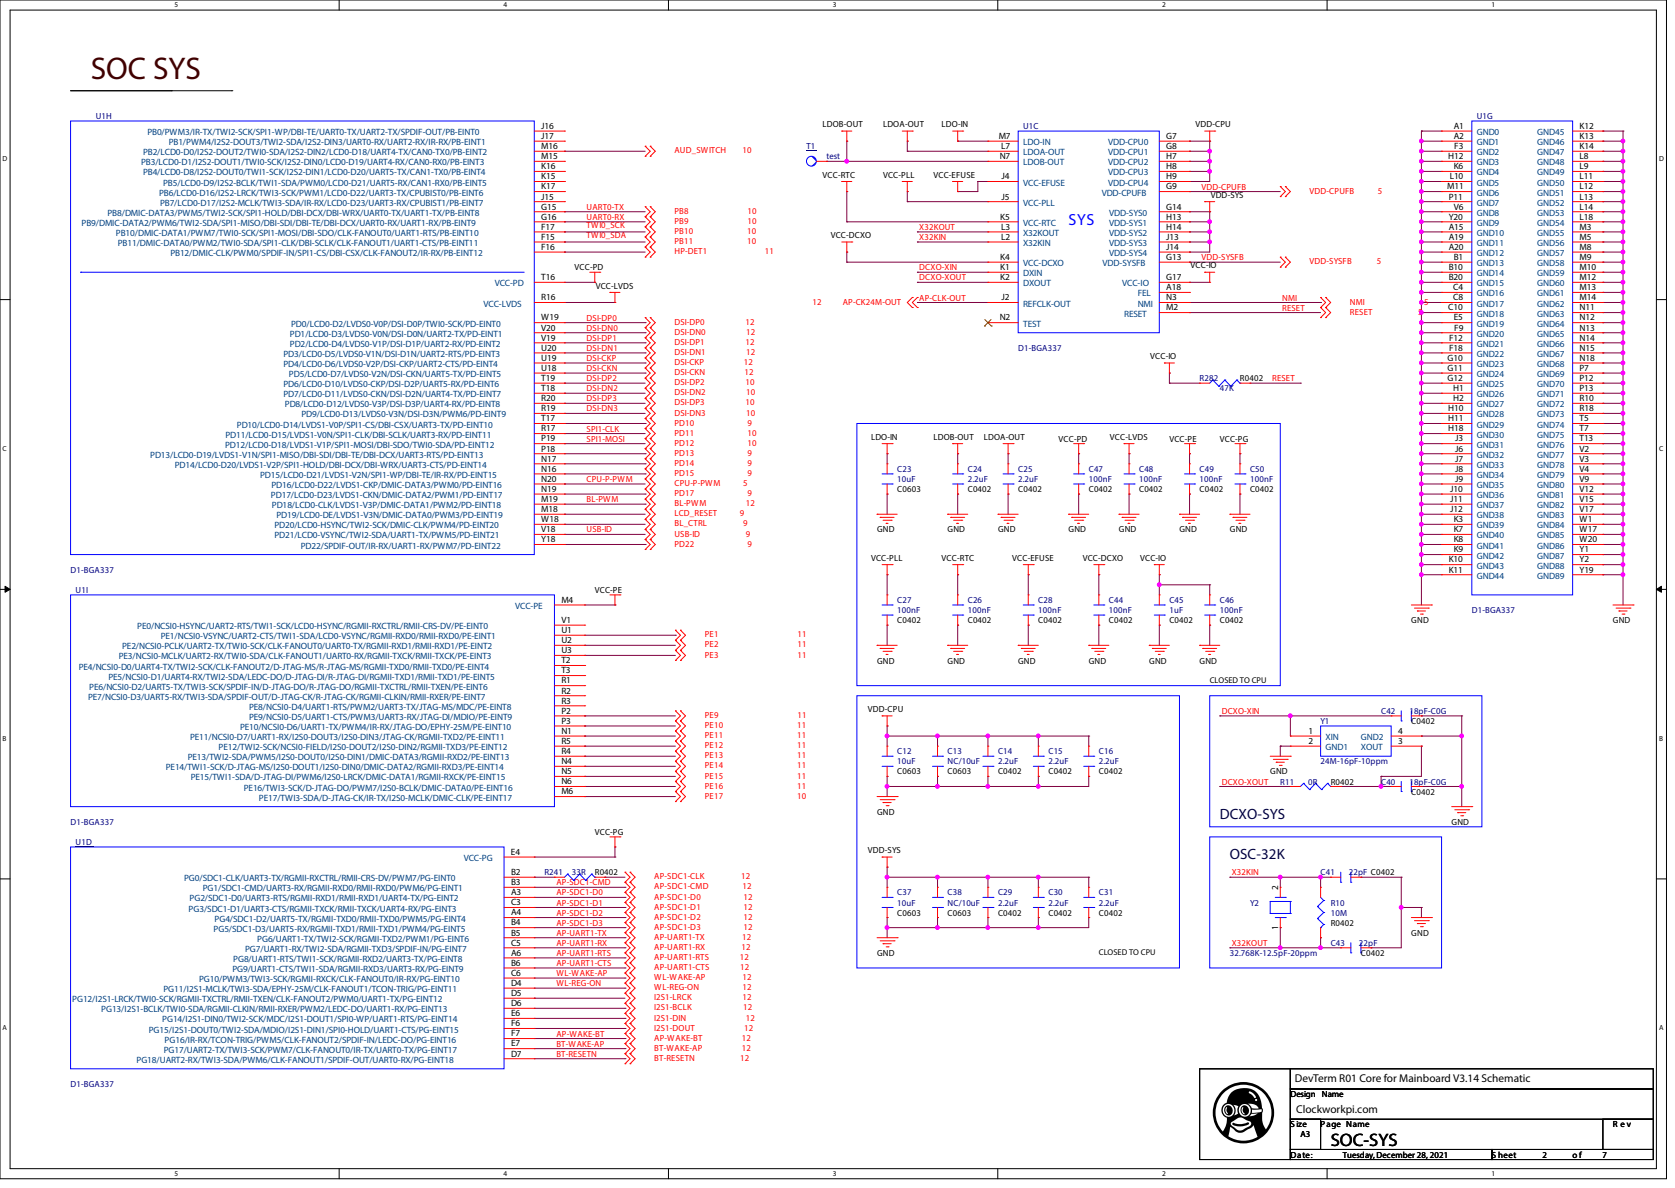
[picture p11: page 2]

DevTerm R01 Core for Mainboard V3.14 Schematic

# SOC-FLASH

# SPI-NAND/NOR

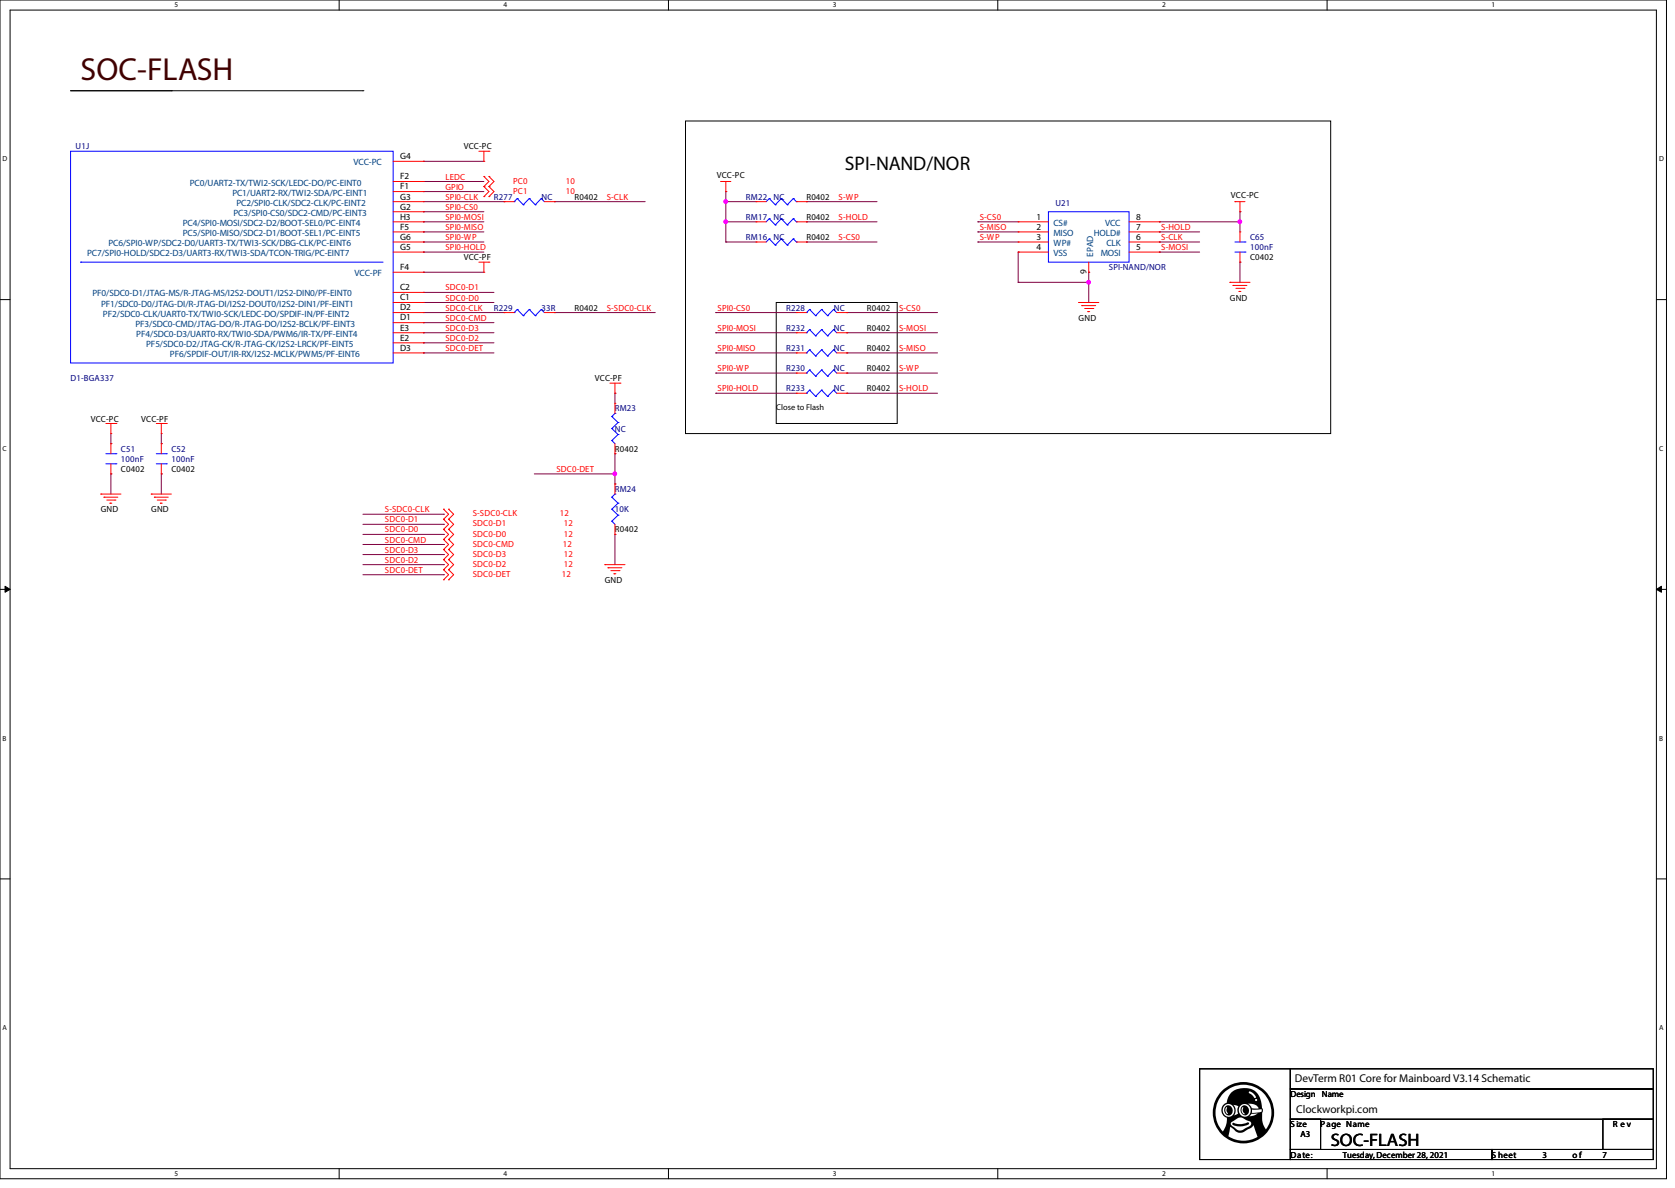
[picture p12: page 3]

DevTerm R01 Core for Mainboard V3.14 Schematic

# DDR3 16x2

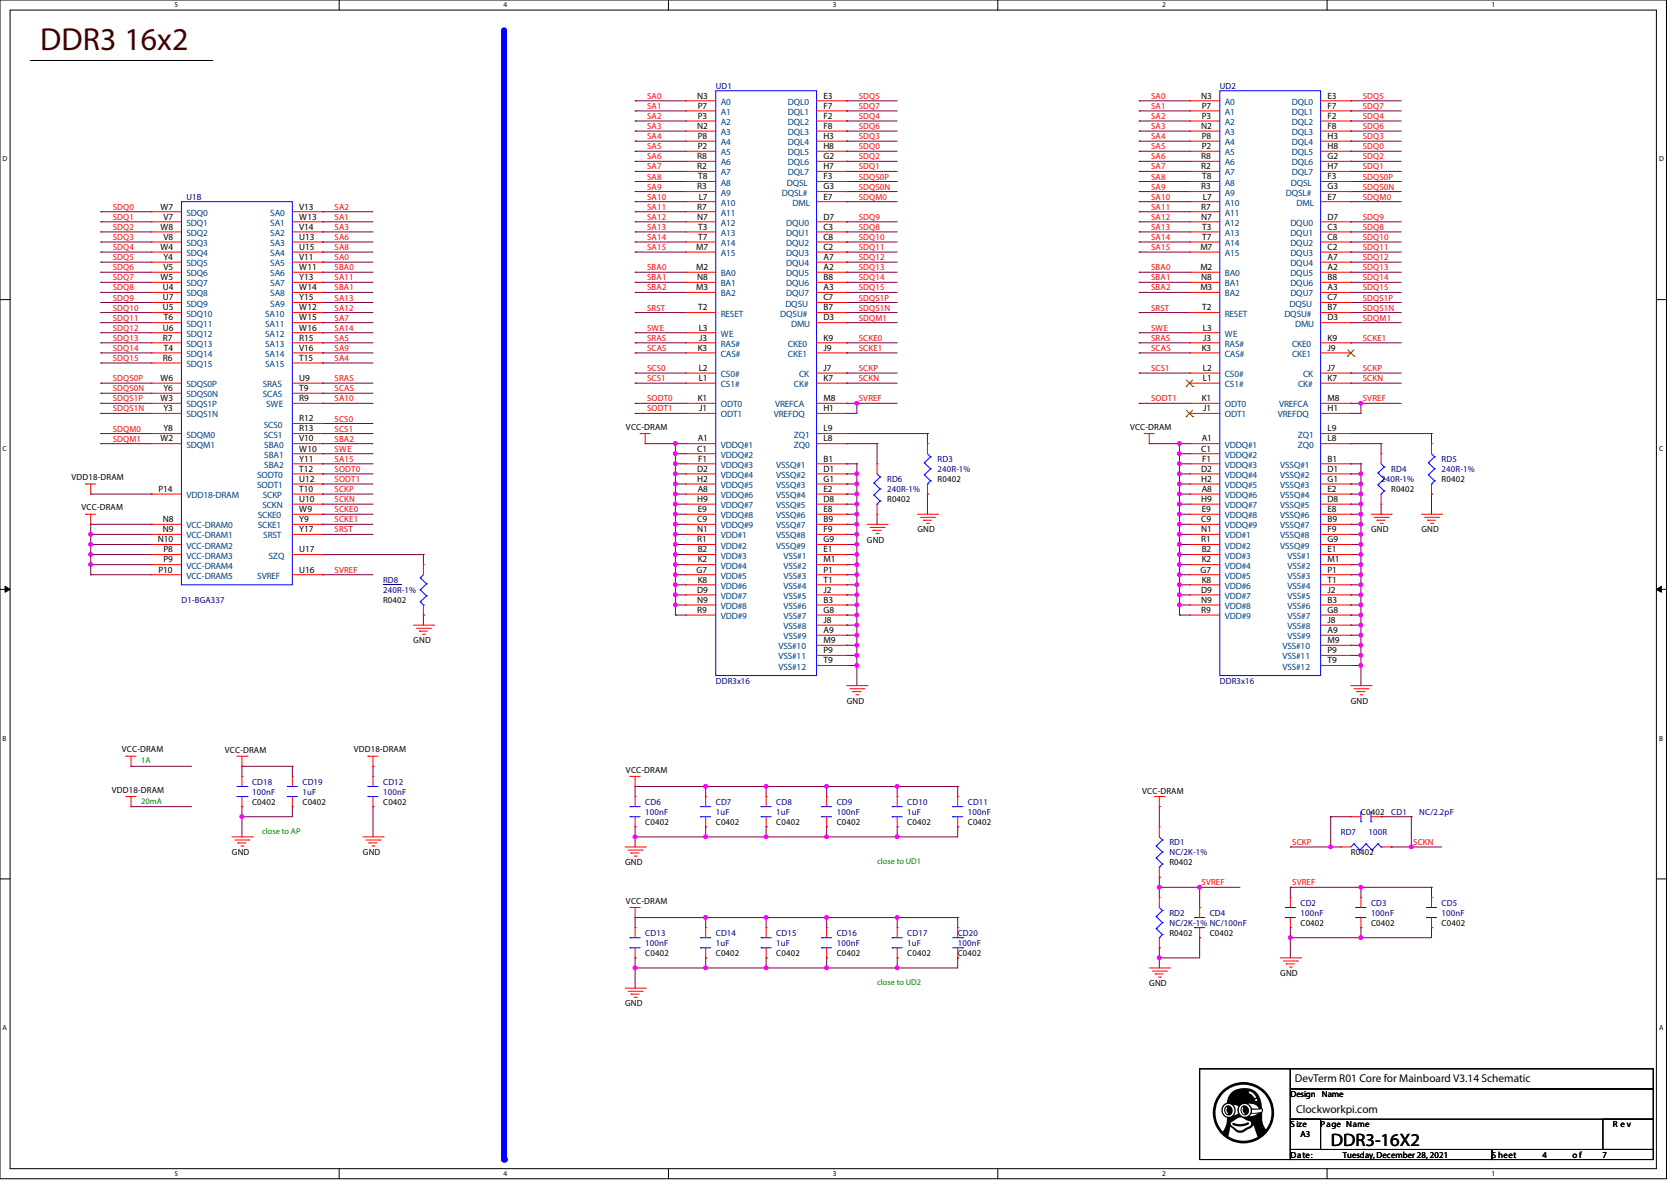
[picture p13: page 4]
close to UD2; close to UD1; SBA; CKE; DDe; ame; VDD; VCC-DRAM0 N8 VCC-DRAM1 N9 VCC-DRAM2 N10; VCC-DRAM3 P8; VCC-DRAM4 P9; VCC-DRAM5 P10; DDR; RAS; CAS; VSS; VSS#; QSL; RESE

close to AP

DevTerm R01 Core for Mainboard V3.14 Schematic

# AUDIO&USB

# AEC

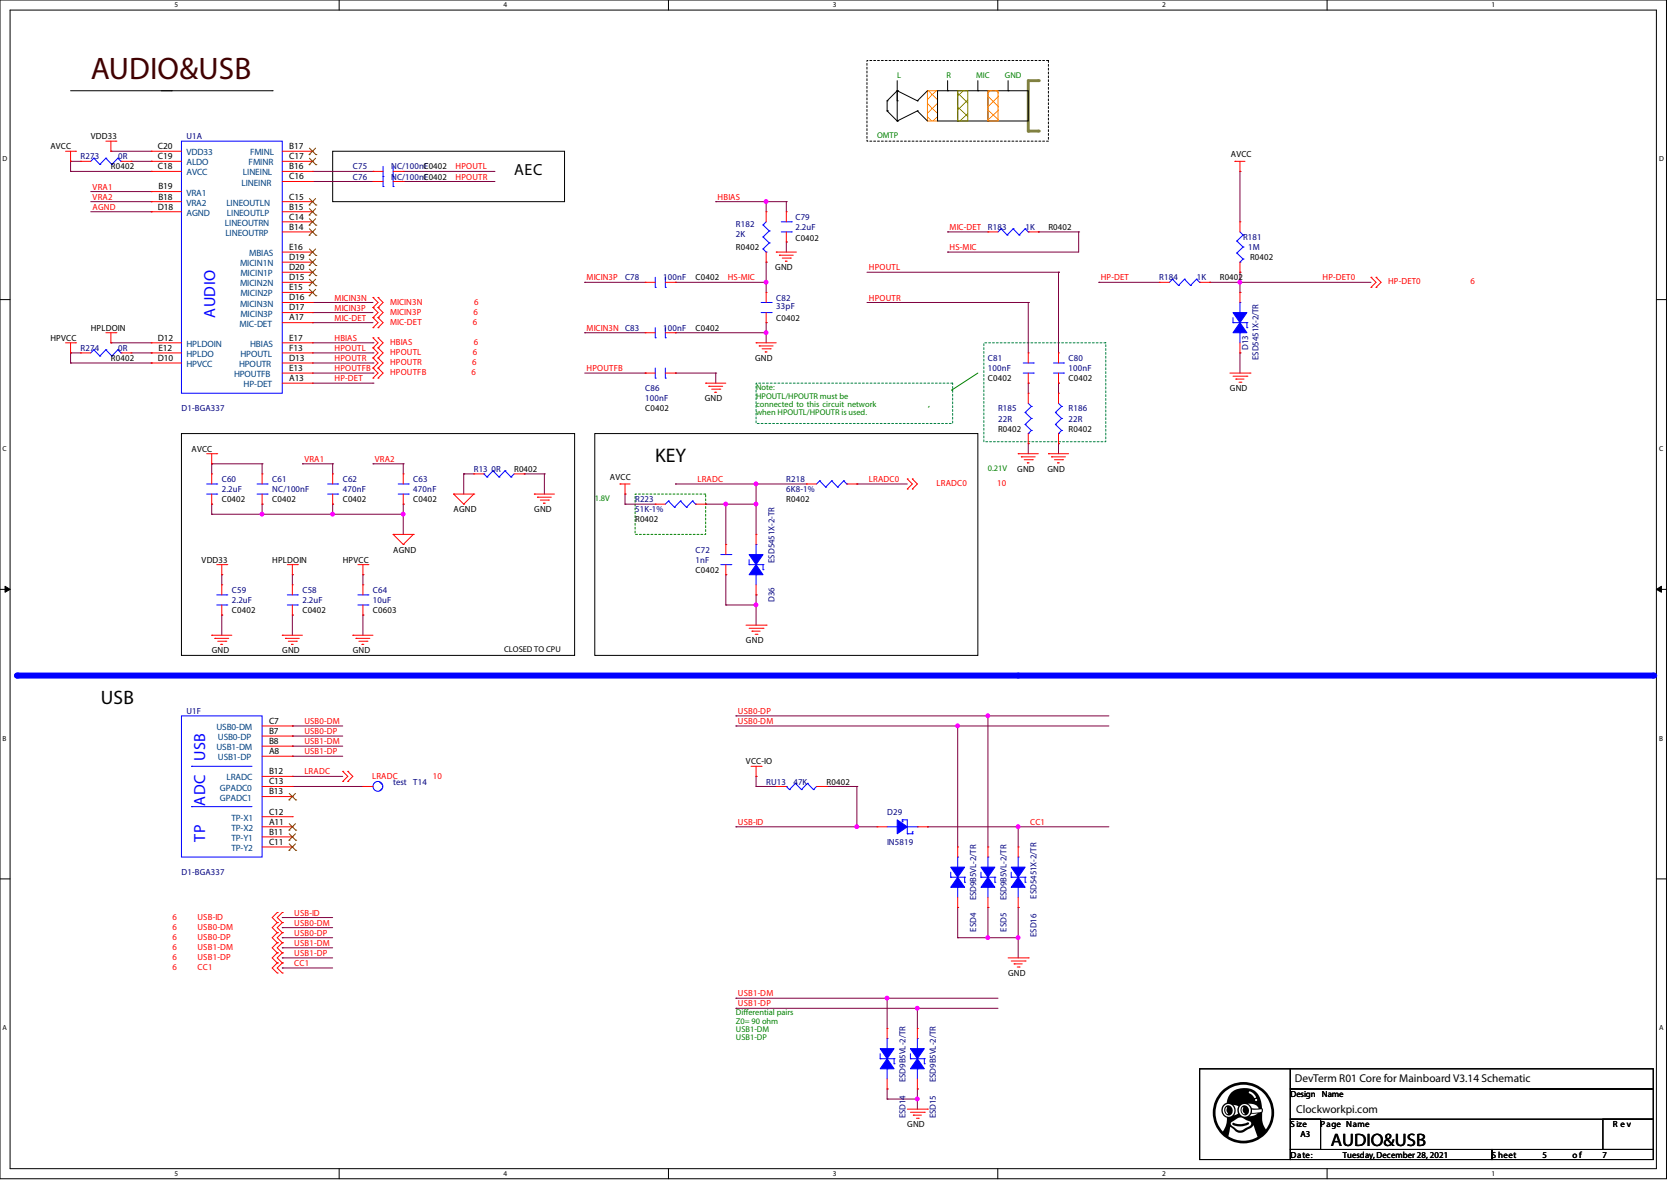
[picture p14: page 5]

Note:
HPOUTL/HPOUTR must be

DevTerm R01 Core for Mainboard V3.14 Schematic

# HDMI&IO EXPAND

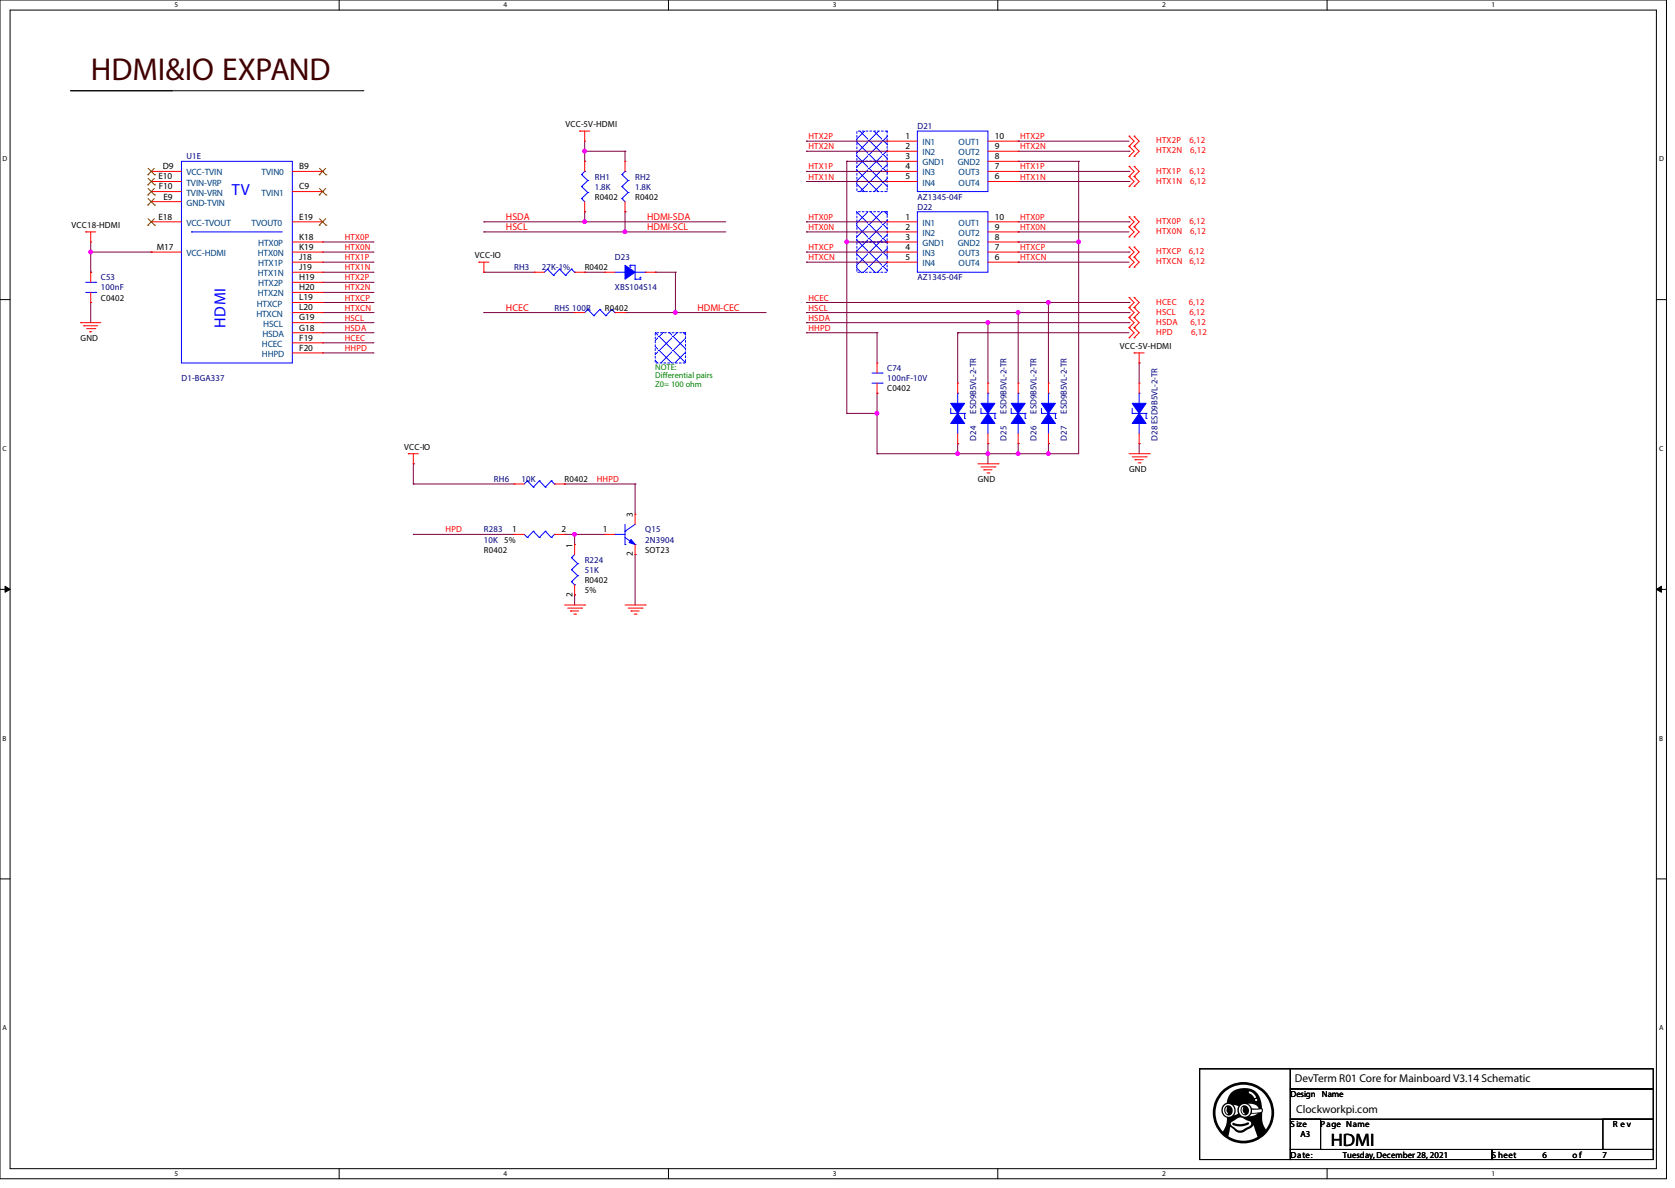
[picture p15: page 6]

DevTerm R01 Core for Mainboard V3.14 Schematic

IN

T

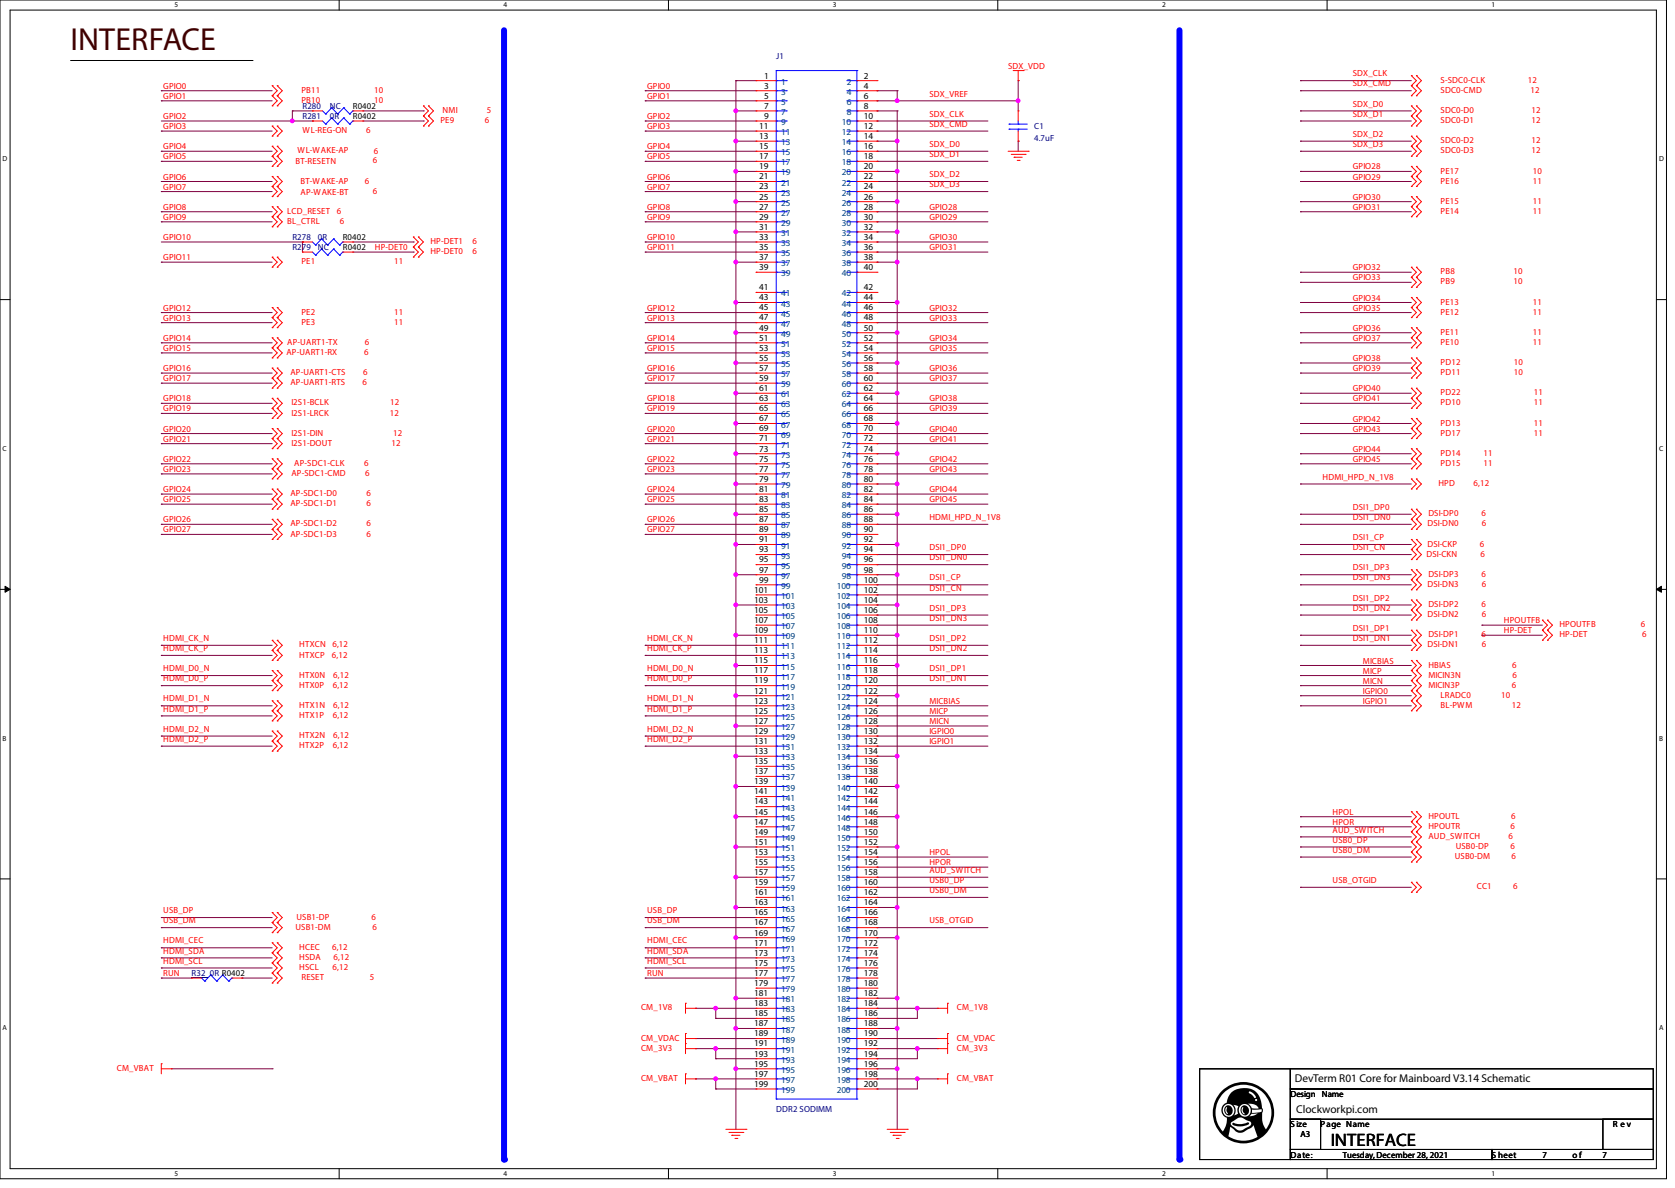
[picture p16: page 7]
M_VBA; WAKE; RESE; ESE; USB0; USB1; ame; 1DDR

DevTerm R01 Core for Mainboard V3.14 Schematic

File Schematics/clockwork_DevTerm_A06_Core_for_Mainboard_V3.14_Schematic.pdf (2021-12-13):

RK3399_W | RK3399_X

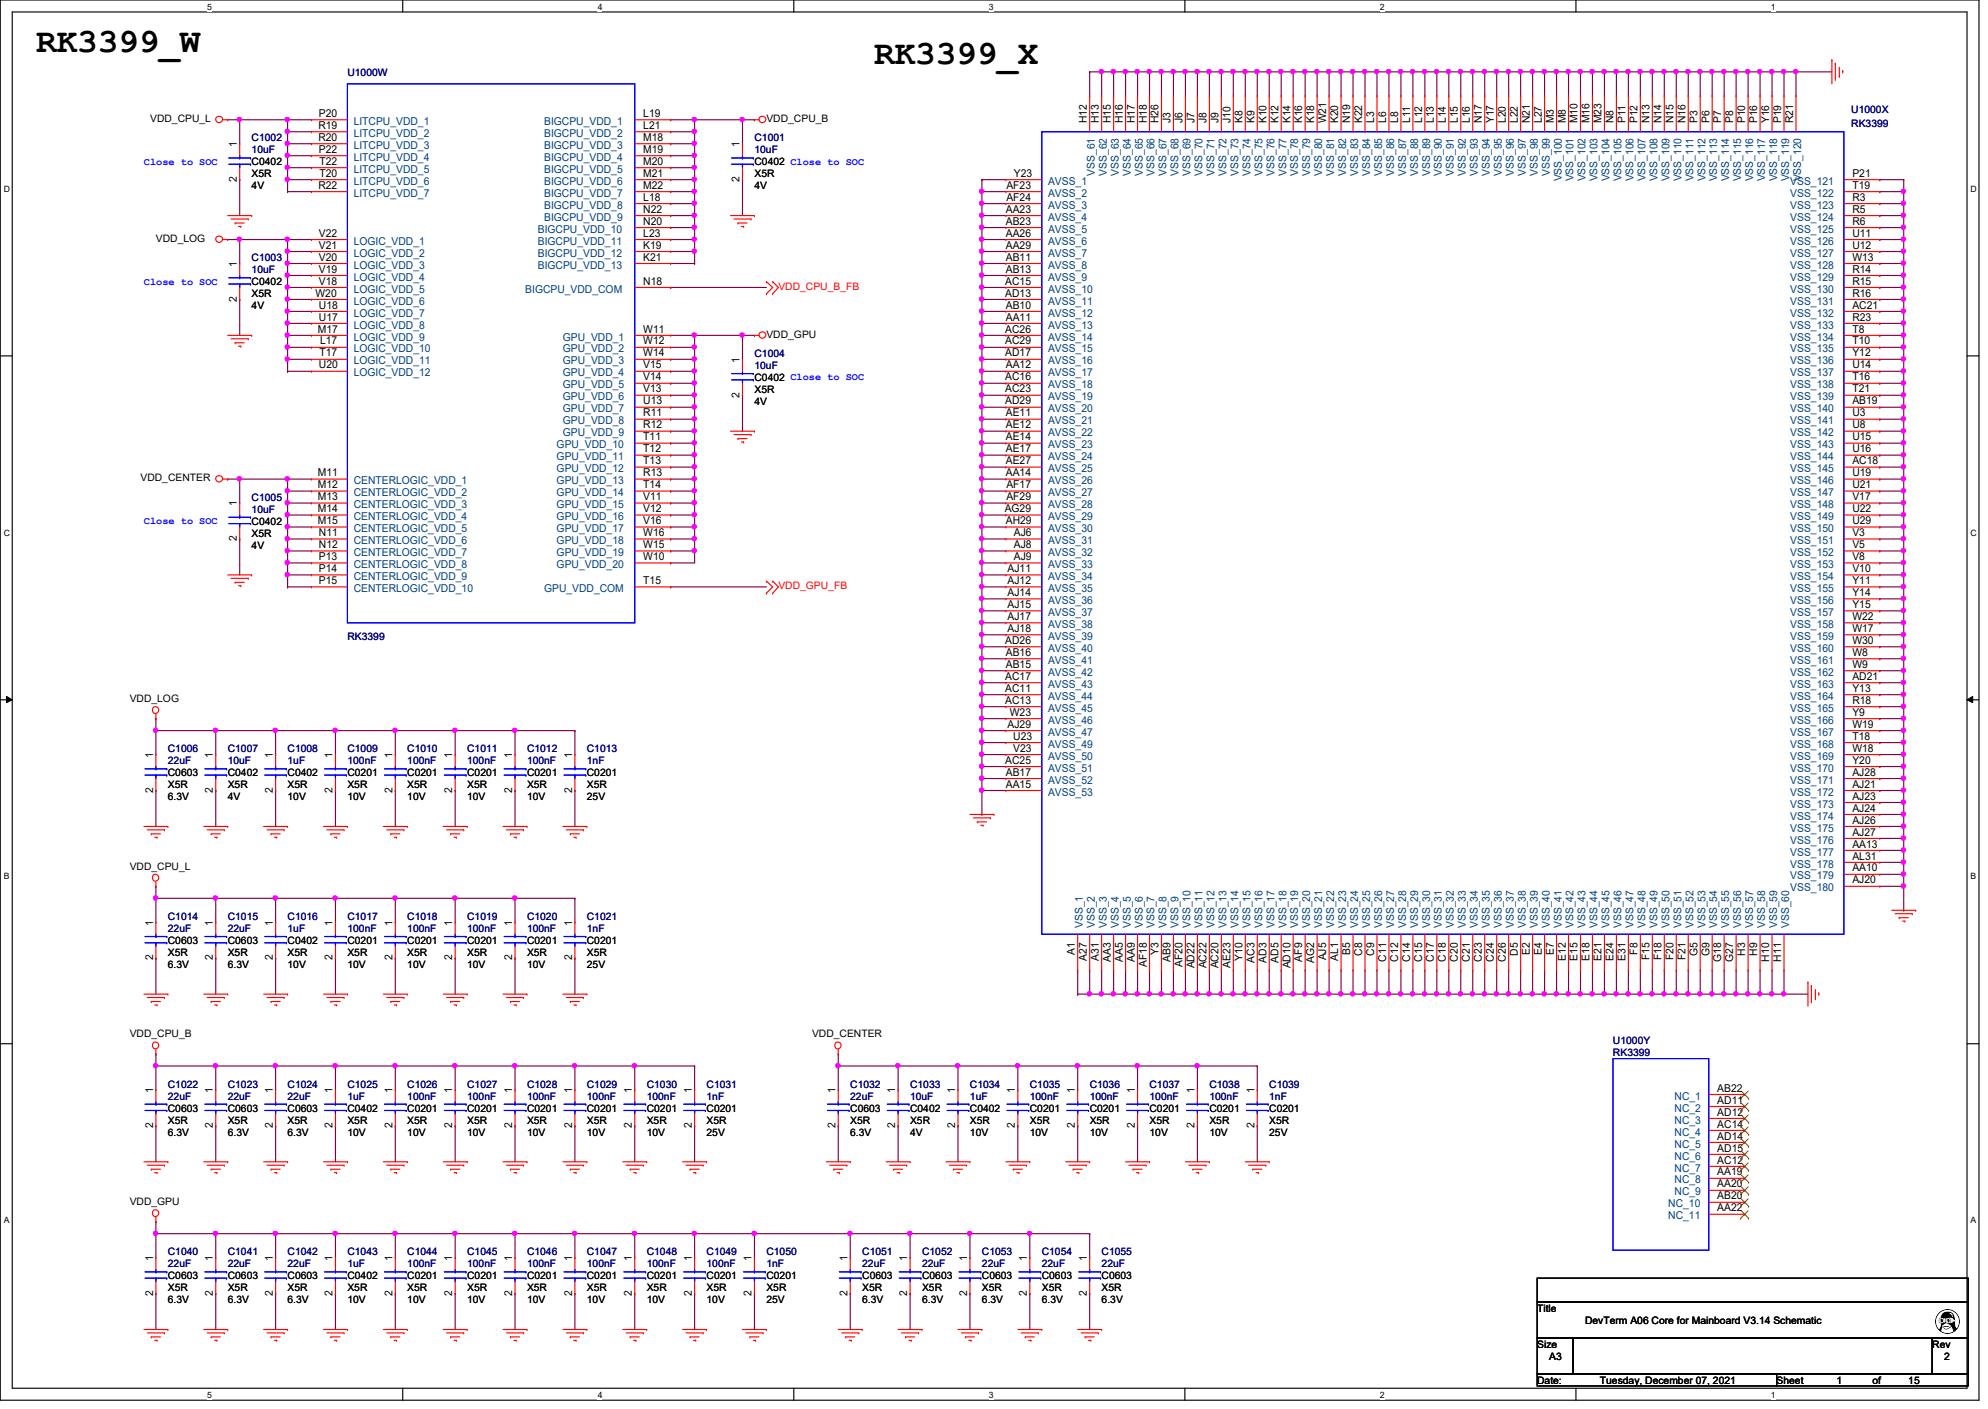
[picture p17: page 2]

DevTerm A06 Core for Mainboard V3.14 Schematic

D D

## 1.8V Only

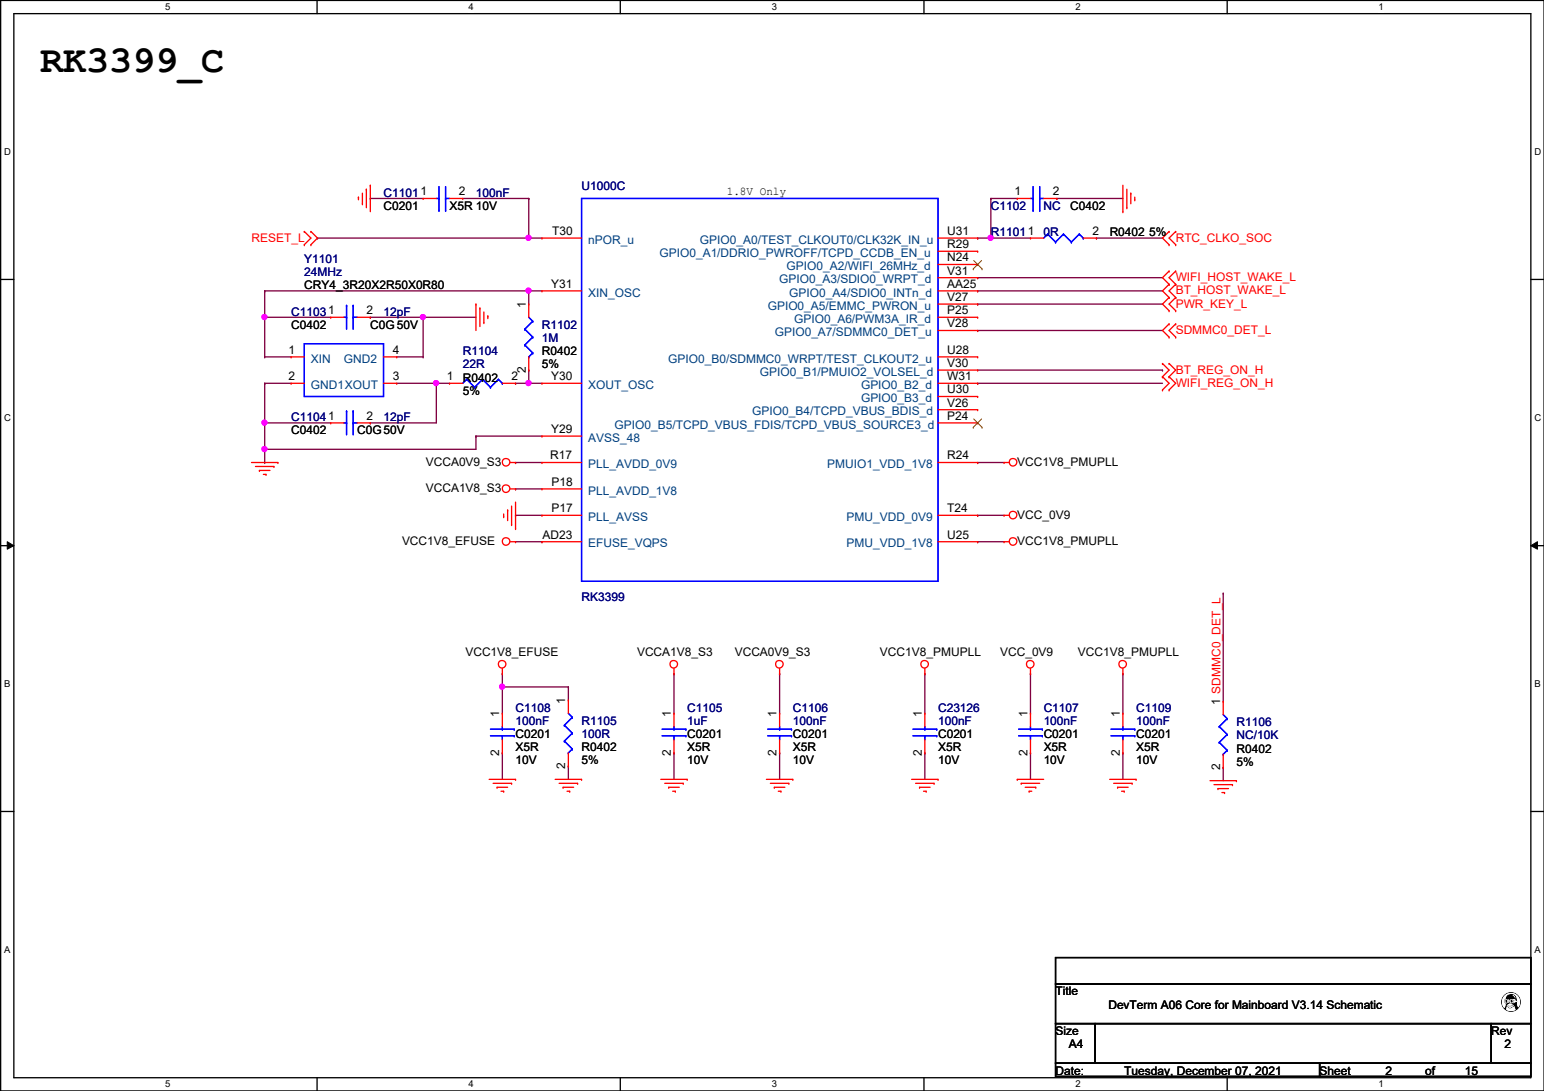
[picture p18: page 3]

RK3399_A | RK3399_B

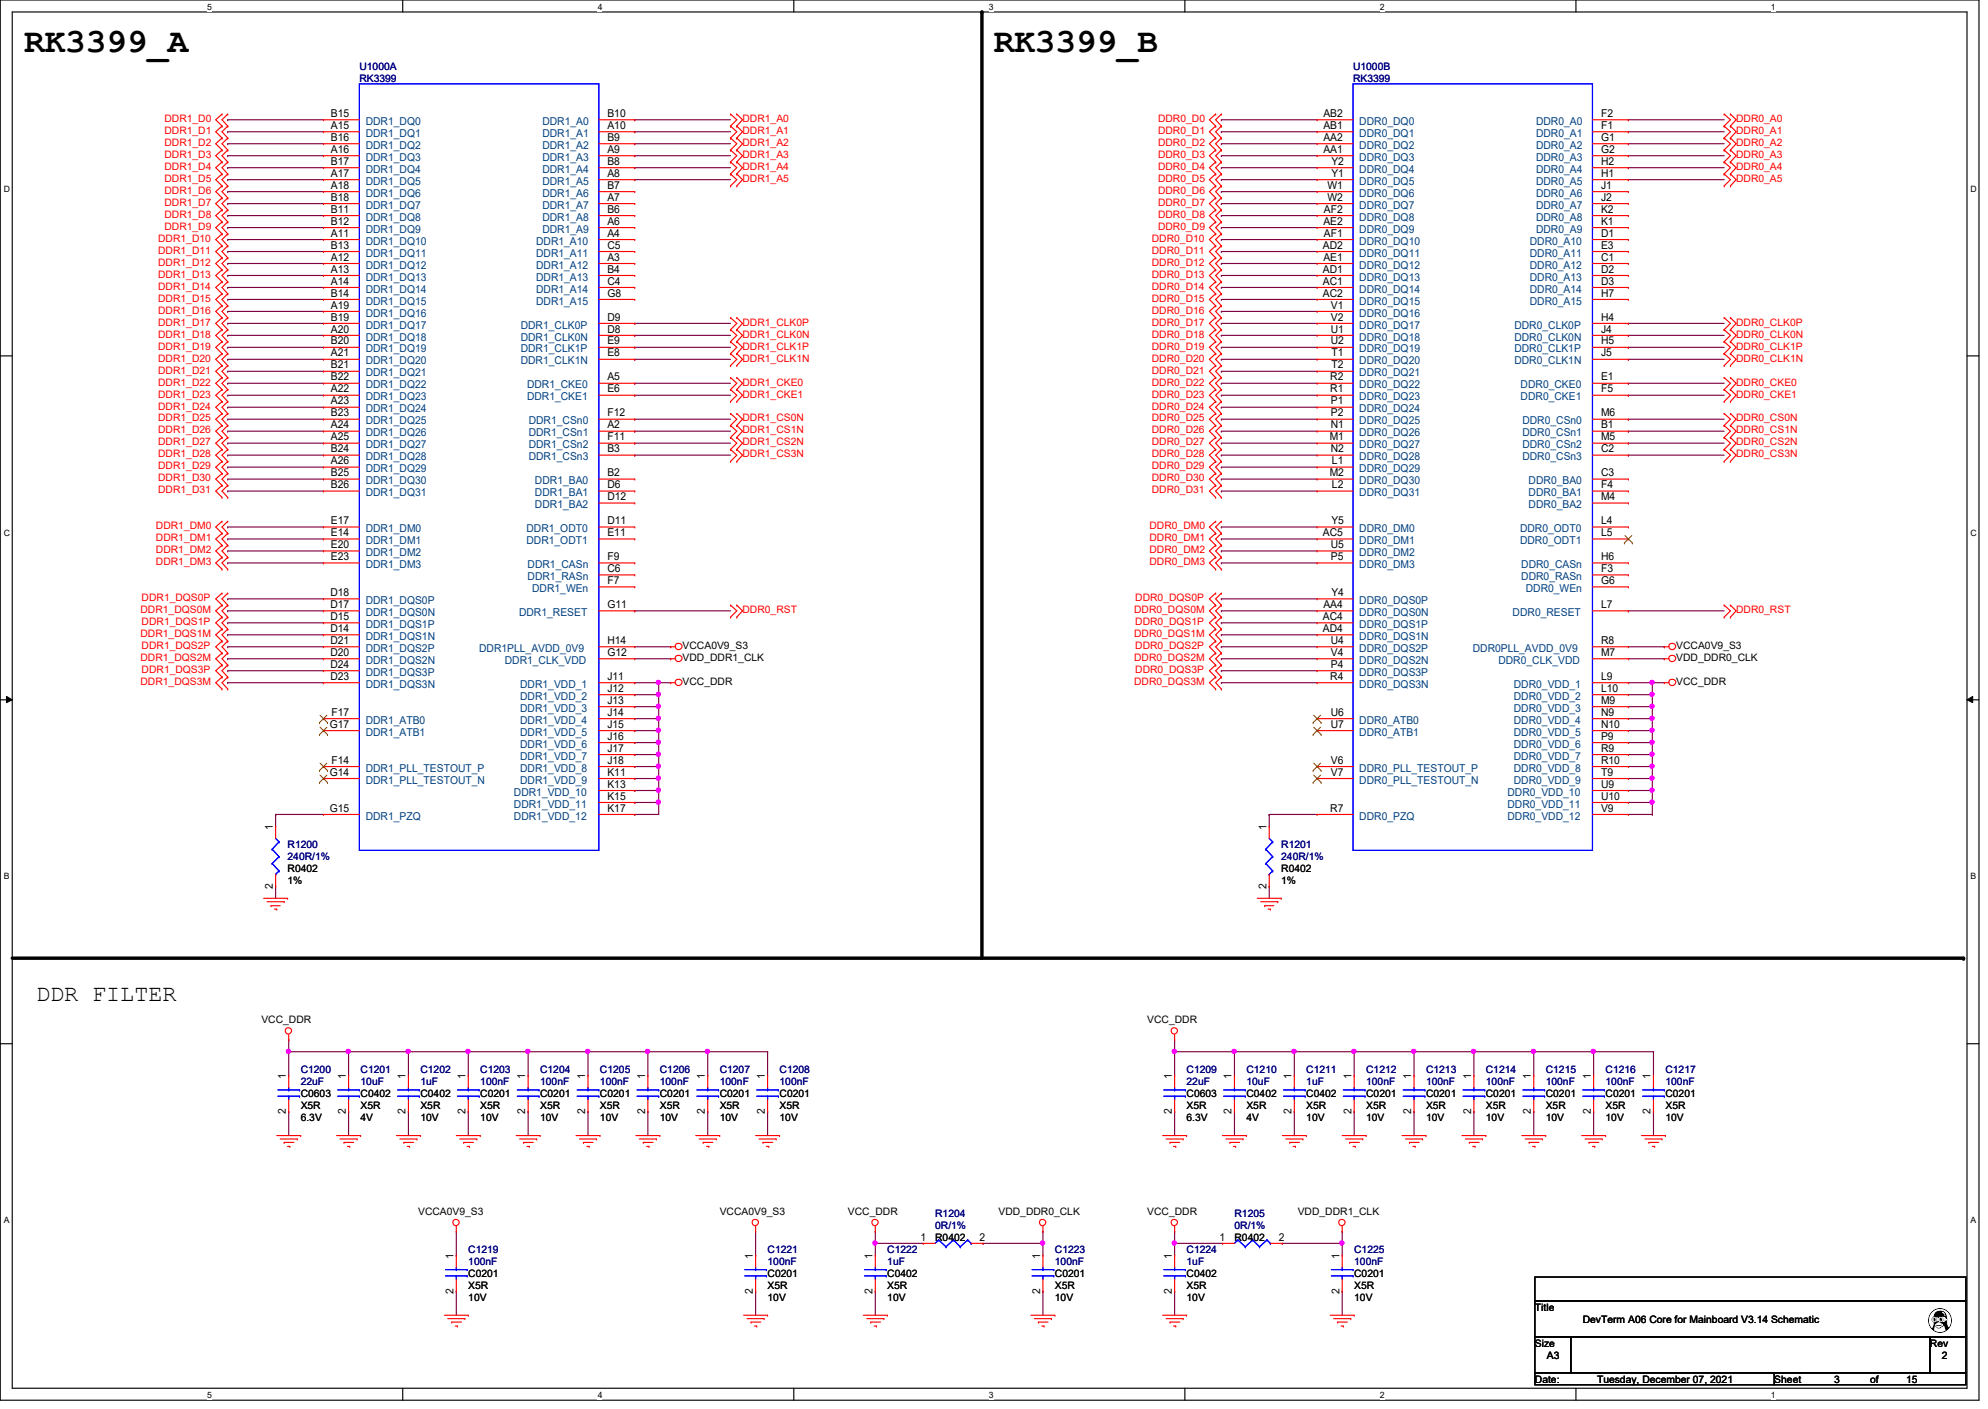
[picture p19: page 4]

D D

。

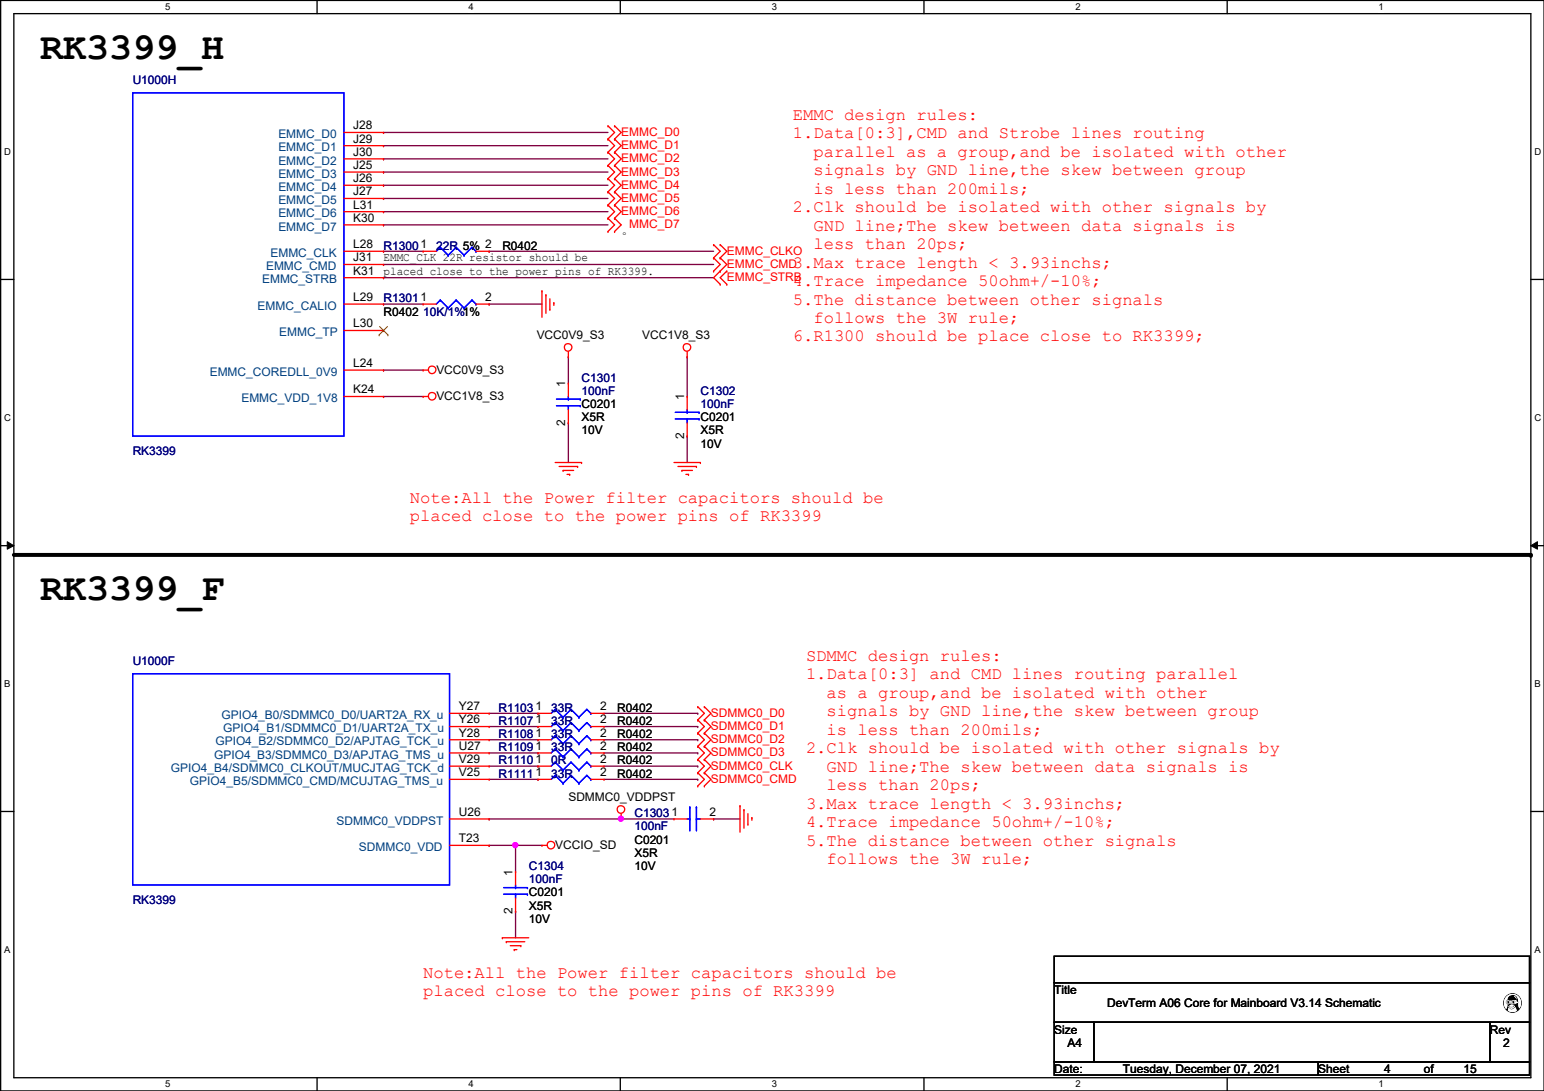
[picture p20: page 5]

EMMC design rules:
1.Data[0:3],CMD and Strobe lines routing
parallel as a group,and be isolated with other
signals by GND line,the skew between group
is less than 200mils;
2.Clk should be isolated with other signals by
GND line;The skew between data signals is
less than 20ps;
3.Max trace length < 3.93inchs;
4.Trace impedance 50ohm+/-10%;
5.The distance between other signals
follows the 3W rule;
6.R1300 should be place close to RK3399;

EMMC_CLK 22R resistor should be
placed close to the power pins of RK3399.

Note:All the Power filter capacitors should be
placed close to the power pins of RK3399

SDMMC design rules:
1.Data[0:3] and CMD lines routing parallel
as a group,and be isolated with other

# RK3399_U


Note:All the Power filter capacitors should be
placed close to the power pins of RK3399

DP design rules:
1.Max intra-pair skew < 4ps;
2.Max trace length < 6inchs;
3.Max allowed via < 4;
4.Trace impedance 90ohm+/-10%;
5.The distance between other signals
follows the 3W rule;

USB2.0 design rules:
3.Max allowed via < 6;

USB3.0 design rules:
2.Max length skew between TX and RX < 1.6ns;
3.Max trace length < 6inchs;
4.Max allowed via < 4;
5.Trace impedance 90ohm+/-10%;
6.The distance between other signals

E E

RK3399_V | RK3399_O


Note:All the Power filter capacitors should be
placed close to the power pins of RK3399

D D

# RK3399_L


The power domain can be designed to be 1.8V or 3.0v.
It should be noted that software configuration needs
to be consistent with hardware design.

MIPI design rules:
1.Max intra-pair skew < 4ps;
2.Max length skew between clk and data < 7ps;
3.Max trace length < 7.2inchs;
4.Max allowed via < 4;
5.Trace impedance 100ohm+/-10%;
6.The distance between other signals
follows the 3W rule;

D D

RK3399_N | RK3399_M


HDMI design rules:
1.Max intra-pair skew < 4ps;
2.Max length skew between clk and data < 80ps;
3.Max trace length < 9.8inchs;
4.Max allowed via < 4;
5.Trace impedance 100ohm+/-10%;
6.The distance between other signals
follows the 3W rule;

eDP design rules:
1.Max intra-pair skew <4 ps;
2.Max trace length < 6inchs;
3.Max allowed via < 4;
4.Trace impedance 90ohm+/-10%;
5.The distance between other signals

The product definition is a single
MIPI_DSI display screen.
Make sure you choose the MIPI_TX0 channel.
Do not select the MIPI_TX1/RX1 channel.

MIPI design rule:
1.Max intra-pair skew < 4 ps；
2.Max length skew between clk and data < 7ps；
3.Max trace length < 7.2 inchs；
4.Max allowed via < 4；
5.Trace impedance 100ohm+/-10%；
6..The distance between other signals

# RK3399_I

# RK3399_E


Note:All the part which support 1.8V and 3.0V mode,
software config should match with hardware design.
VCC1V8_S3

1. GPIO0_B1/PMUIO 2_VOLSEL multiplexing.
At the beginning of start-up, it is used as
power domain judgment of PMUIO2_VDD.
After startup, do general GPIO function.
2. When the power domain of PMUIO2_VDD
is 3.0v, 10K is required.Pull-up resistance.

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

Note:All the Power filter capacitors should be
placed close to the power pins of RK3399

SDIO design rules:
1.Data[0:3] and CMD lines routing parallel
as a group, and be isolated with other
signals by GND line，the skew between group
is less than 200mils;
GND line;The skew between data signals is
less than 20ps;
3.Max trace length < 3.93 inchs;
4.Trace impedance 50ohm+/-10%;
5.The distance between other signals
follows the 3W rule;


Note:All the Power filter capacitors should be
placed close to the power pins of DDR

D D

# eMMC FLASH


Note:All the Power filter capacitors should be
placed close to the power pins of eMMC

Note:
Reserve TestPoint for firmware update.
If EMMC_CLKO=0V at power-on reset,
then system will enter into Maskrom mode.

RK3399

## 1、VDD_CPU_L


Feedback from DDR device

# VCC_0V9

# VCCA0V9_S3


D D

# CODEC



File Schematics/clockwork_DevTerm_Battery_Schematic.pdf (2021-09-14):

Title; S ize; Date:; S heet; D1 DO-214AB/SMC; 4 HEADER; D2 DO-214AB/SMC; ASMD1812SL; January 23, 2021

DevTerm Battery Board Schematic

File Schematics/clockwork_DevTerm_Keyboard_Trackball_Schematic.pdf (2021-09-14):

# SUB BOARD - Trackball

Title; S ize; Date:; S heet; Tuesday, March 23, 2021; CON8B; GND; VDD; OUT; EVQP6; VDD A1 A2; K0 A3 A4 GDD; GDD

DevTerm Keyboard Schematic - Trackball

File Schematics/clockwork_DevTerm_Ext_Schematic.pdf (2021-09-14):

USB | SPEAKER

# DEBUG


DevTerm Ext. Board Schematic

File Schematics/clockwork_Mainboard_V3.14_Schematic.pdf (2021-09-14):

# POWER

# AUDIO


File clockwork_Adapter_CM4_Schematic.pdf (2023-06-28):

_VBA; Monda; ril 18; the; nLE; D_VDD; verr; npu; sab; Ana; AGND; USB_; ABL; USB0_; BOO; TPL

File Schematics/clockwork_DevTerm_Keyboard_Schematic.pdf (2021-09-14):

COL1 | COL2 | COL3 | COL4 | COL5 | COL6 | COL7 | COL8

## ROW1

ROW2; ROW3; ROW4; ROW5; ROW6; ROW7; ROW8

55

44

STM; ESD1 ESD0402; ESD2 ESD0402; ESD3 ESD0402; yboa

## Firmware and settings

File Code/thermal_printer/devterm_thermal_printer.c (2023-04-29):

// for ltp02-245
// 203 dpi, 384dots in 48mm(1.88976inch) every dots == 0.125mm,
// 1byte==8dots==1mm make clean && make && ./*.elf
//#include <SPI.h>
#include <fcntl.h>
#include <stdarg.h>
#include <stdint.h>
#include <stdio.h>
#include <stdlib.h>
#include <string.h>
#include <sys/stat.h>
#include <unistd.h>

#include <wiringPi.h>

#include "logo.h"

#include "pcf_5x7-ISO8859-1_5x7.h"
#include "pcf_6x12-ISO8859-1_6x12.h"
#include "pcf_7x14-ISO8859-1_7x14.h"

#include "ttf_Px437_PS2thin1_8x16.h"
#include "ttf_Px437_PS2thin2_8x16.h"

#include "config.h"
#include "printer.h"
#include "utils.h"

#include "ftype.h"
#include <math.h>

SerialCache ser_cache;

uint8_t cmd[10];
uint8_t cmd_idx;

uint8_t newline;
char buf[2];

unsigned long time;

ImageCache img_cache;

FONT current_font;

FT_Face face;

FT_Library ft;

CONFIG g_config;

TimeRec battery_chk_tm;

int printf_out(CONFIG *cfg, char *format, ...) {
  va_list args;
  int rv;

  va_start(args, format);
  if (cfg->fp != NULL)
    rv = vfprintf(cfg->fp, format, args);
  else {
    rv = -1;
  }
  va_end(args);

  return rv;
}

// void printer_set_font(CONFIG*cfg,uint8_t fnbits);
// void parse_serial_stream(CONFIG*cfg,uint8_t input_ch);

void reset_cmd() {
  cmd_idx = 0;
  ser_cache.idx = 0;
  g_config.state = PRINT_STATE;
}

void init_printer() {
  char *error = NULL;
  memset(cmd, 0, 10);

  newline = 0;
  cmd_idx = 0;

  img_cache.idx = 0;
  img_cache.num = 0;
  img_cache.width = 0;

  img_cache.need_print = 0;
  img_cache.revert_bits = 0;

  ser_cache.idx = 0;
  ser_cache.utf8idx = 0;

  /*
    current_font.width=5; current_font.height=7; current_font.data =
    font_pcf_5x7_ISO8859_1_5x7; current_font.width=6;current_font.height=12;
    current_font.data = font_pcf_6x12_ISO8859_1_6x12; current_font.width=7;
    current_font.height=14; current_font.data = font_pcf_7x14_ISO8859_1_7x14;

    //current_font.width=8;current_font.height=16; current_font.data=
    font_ttf_Px437_ISO8_8x16;
    //current_font.width=8;current_font.height=16; current_font.data=
    font_ttf_Px437_ISO9_8x16;

    current_font.width=8;current_font.height=16; current_font.data=
    font_ttf_Px437_PS2thin2_8x16;
  */
  // auto detect TTF ,switch to FONT_MODE_1
  if (getenv("TTF") && access(getenv("TTF"), F_OK) != -1) {
    printf("TTF=%s\n", getenv("TTF"));
    current_font.width = 12;
    current_font.height = 12;
    current_font.data = NULL;
    current_font.file = getenv("TTF");
    current_font.mode = FONT_MODE_1;

    if (init_ft(current_font.file, &face, &ft, current_font.width,
                current_font.height, &error)) {
      g_config.face = face;
      g_config.ft = ft;
    } else {
      printf("init_ft error %s\n", error);
      g_config.face = NULL;
      g_config.ft = NULL;
    }
  }

  //default still FONT_MODE_0, comment out below 4 lines to enable unicode printing
  current_font.mode = FONT_MODE_0;
  current_font.width = 8;
  current_font.height = 16;
  current_font.data = font_ttf_Px437_PS2thin2_8x16;
  
  g_config.line_space = 0;
  g_config.align = ALIGN_LEFT;
  g_config.reverse = 0;

  g_config.margin.width = 0;
  g_config.margin.esgs = 0;

  g_config.orient = FORWARD;

  g_config.wordgap = 0;

  g_config.font = &current_font;

  g_config.under_line = 0;

  g_config.state = PRINT_STATE;

  g_config.img = &img_cache;
  g_config.density = 6;

  g_config.feed_pitch = 2;
  g_config.max_pts = 2;
  g_config.lock = 0;
  g_config.degree = 0;

  battery_chk_tm.time = millis();
  battery_chk_tm.last_status = 0;
  battery_chk_tm.check = 0;
}

const char url[] = {"Powered by clockworkpi.com"};

void label_print_f(CONFIG *cfg, char *label, float m, char *last) {
  char buf[48];
  uint8_t i, j;

  if (m == -1.0)
    sprintf(buf, "%s", last);
  else
    sprintf(buf, "%0.2f%s", m, last);

  j = strlen(buf);
  i = 48 - strlen(label) - j - 1;

  if (m == -1.0)
    sprintf(buf, "%s%*s%s", label, i, "", last);
  else
    sprintf(buf, "%s%*s%0.2f%s", label, i, "", m, last);

  printer_set_font(cfg, 4);
  reset_cmd();

  for (i = 0; i < strlen(buf); i++) {
    parse_serial_stream(cfg, buf[i]);
  }
  parse_serial_stream(cfg, 10);
  reset_cmd();
}

void label_print_i(CONFIG *cfg, char *label, int m, char *last) {
  char buf[MAXPIXELS];
  uint8_t i, j;

  if (m == -1)
    sprintf(buf, "%s", last);
  else
    sprintf(buf, "%d%s", m, last);

  j = strlen(buf);
  i = MAXPIXELS - strlen(label) - j - 1;

  if (m == -1)
    sprintf(buf, "%s%*s%s", label, i, "", last);
  else
    sprintf(buf, "%s%*s%d%s", label, i, "", m, last);

  printer_set_font(cfg, 4);
  reset_cmd();

  for (i = 0; i < strlen(buf); i++) {
    parse_serial_stream(cfg, buf[i]);
  }
  parse_serial_stream(cfg, 10);
  reset_cmd();
}

void printer_test(CONFIG *cfg) {

  uint8_t i, j;
  uint8_t ch;
  uint16_t k;

  char buf[MAXPIXELS];
  char *font_names[] = {"8x16thin_1",     "5x7_ISO8859_1", "6x12_ISO8859_1",
                        "7x14_ISO8859_1", "8x16thin_2",    NULL};

  /*
  char *selftest1[] = {
"          _  __   _            _   ",
" ___  ___| |/ _| | |_ ___  ___| |_ ",
"/ __|/ _ \\ | |_  | __/ _ \\/ __| __|",
"\\__ \\  __/ |  _| | ||  __/\\__ \\ |_ ",
"|___/\\___|_|_|    \\__\\___||___/\\__|",
NULL
  };
*/
  char *selftest2[] = {
      " ####   ######  #       ######   #####  ######   ####    #####",
      "#       #       #       #          #    #       #          # ",
      " ####   #####   #       #####      #    #####    ####      # ",
      "     #  #       #       #          #    #            #     # ",
      "#    #  #       #       #          #    #       #    #     # ",
      " ####   ######  ######  #          #    ######   ####      # ",
      NULL};

  cfg->density = 6;

  k = (os120_width / 8) * os120_height;
  memcpy(cfg->img->cache, os120_bits, k);
  cfg->img->width = os120_width / 8;
  cfg->img->num = k;
  cfg->img->revert_bits = 1;
  cfg->align = ALIGN_CENTER;
  print_image8(cfg);

  cfg->img->revert_bits = 0;
  cfg->align = ALIGN_LEFT;
  print_lines8(NULL,15, cfg->orient);

  cfg->align = ALIGN_CENTER;
  /* //selftest1
  for(i=0;i<5;i++){
    printer_set_font(cfg,0);
    reset_cmd();
    for(j=0;j<strlen(selftest1[i]);j++){
      parse_serial_stream(cfg,selftest1[i][j]);
    }
    parse_serial_stream(cfg,10);
  }
  */

  for (i = 0; i < 6; i++) {
    printer_set_font_mode(cfg, FONT_MODE_0);
    printer_set_font(cfg, 1);
    reset_cmd();

    for (j = 0; j < strlen(selftest2[i]); j++) {
      parse_serial_stream(cfg, selftest2[i][j]);
    }
    parse_serial_stream(cfg, 10);
  }
  cfg->align = ALIGN_LEFT;

  print_lines8(NULL,32, cfg->orient);

  //---------------------------------------------

  for (i = 1; i < 4; i++) {
    printer_set_font_mode(cfg, FONT_MODE_0);
    printer_set_font(cfg, 0);
    reset_cmd();
    for (j = 0; j < strlen(font_names[i]); j++) {

      parse_serial_stream(cfg, font_names[i][j]);
    }
    parse_serial_stream(cfg, 10);

    printer_set_font_mode(cfg, FONT_MODE_0);
    printer_set_font(cfg, i);
    reset_cmd();
    for (ch = 33; ch < 127; ch++) {
      parse_serial_stream(cfg, ch);
      // Serial.print(ch,DEC);
    }
    parse_serial_stream(cfg, 10);
    // Serial.println();
    print_lines8(NULL,48, cfg->orient);
  }

  printer_set_font_mode(cfg, FONT_MODE_0);
  printer_set_font(cfg, 0);
  reset_cmd();
  for (j = 0; j < strlen(font_names[0]); j++) {
    parse_serial_stream(cfg, font_names[0][j]);
  }
  parse_serial_stream(cfg, 10);

  printer_set_font_mode(cfg, FONT_MODE_0);
  printer_set_font(cfg, 0);
  reset_cmd();
  for (ch = 33; ch < 127; ch++) {
    parse_serial_stream(cfg, ch);
    // Serial.print(ch,DEC);
  }
  parse_serial_stream(cfg, 10);
  // Serial.println();
  print_lines8(NULL,48, cfg->orient);

  printer_set_font_mode(cfg, FONT_MODE_0);
  printer_set_font(cfg, 0);
  reset_cmd();
  for (j = 0; j < strlen(font_names[0]); j++) {
    parse_serial_stream(cfg, font_names[4][j]);
  }
  parse_serial_stream(cfg, 10);

  printer_set_font_mode(cfg, FONT_MODE_0);
  printer_set_font(cfg, 4);
  reset_cmd();
  for (ch = 33; ch < 127; ch++) {
    parse_serial_stream(cfg, ch);
    // Serial.print(ch,DEC);
  }
  parse_serial_stream(cfg, 10);
  // Serial.println();
  print_lines8(NULL,28, cfg->orient);

  //-------------------------------------------

  k = temperature();
  label_print_i(cfg, "Temperature:", k, " C");
  //--------------------------------------------------------

  label_print_i(cfg, "Darkness setting:", cfg->density, " (Light 0-15 Dark)");

  label_print_i(cfg, "Paper width:", -1, "58mm");
  label_print_i(cfg, "Print width:", -1, "48mm");

  label_print_i(cfg, "Baudrate:", 115200, "");
  label_print_i(cfg, "Data bits:", 8, "");
  label_print_i(cfg, "Stop bits:", 1, "");
  //------------------------------------------

  //------------------------------------------
  label_print_f(cfg, "Firmware version:", 0.1, "");

  print_lines8(NULL,cfg->font->height, cfg->orient);
  //--------------------------------------------------------------
  printer_set_font_mode(cfg, FONT_MODE_0);
  printer_set_font(cfg, 0);
  reset_cmd();

  // Serial.println(strlen(url),DEC);
  for (i = 0; i < strlen(url); i++) {
    parse_serial_stream(cfg, url[i]);
  }
  parse_serial_stream(cfg, 10);
  reset_cmd();

  //-----------------------------------
  // grid
    ENABLE_VH;  
    for(ch = 0;ch <16;ch++){
      if(ch%2==0)
        j = 0xff;
      else
        j = 0x00;

      for(k=0;k<8;k++){
        for(i=0;i<48;i++){
          if(i % 2==0) {
            buf[i]=j;
          }else{
            buf[i]=0xff-j;
          }
        }
        print_dots_8bit_split(cfg,(uint8_t*)buf,48);
      }
    }
   DISABLE_VH;
  //--------------------------------------------------------
  print_lines8(NULL,cfg->font->height * 2, cfg->orient);
}

void printer_set_font_mode(CONFIG *cfg, int mode) {
  cfg->font->mode = mode;
  return;
}
void printer_set_font(CONFIG *cfg, uint8_t fnbits) {
  uint8_t ret;
  ret = MID(fnbits, 0, 3);

  if (cfg->font->mode == FONT_MODE_0) {
    if (ret == 0) {
      cfg->font->width = 8;
      cfg->font->height = 16;
      cfg->font->data = font_ttf_Px437_PS2thin1_8x16;
    }

    if (ret == 1) {
      cfg->font->width = 5;
      cfg->font->height = 7;
      cfg->font->data = font_pcf_5x7_ISO8859_1_5x7;
    }

    if (ret == 2) {
      cfg->font->width = 6;
      cfg->font->height = 12;
      cfg->font->data = font_pcf_6x12_ISO8859_1_6x12;
    }

    if (ret == 3) {
      cfg->font->width = 7;
      cfg->font->height = 14;
      cfg->font->data = font_pcf_7x14_ISO8859_1_7x14;
    }

    if (ret == 4) {
      cfg->font->width = 8;
      cfg->font->height = 16;
      cfg->font->data = font_ttf_Px437_PS2thin2_8x16;
    }
  }

  if (cfg->font->mode == FONT_MODE_1) {
    if (ret == 0) {
      cfg->font->width = 12;
      cfg->font->height = 12;
    }
    if (ret == 1) {
      cfg->font->width = 14;
      cfg->font->height = 14;
    }
    if (ret == 2) {
      cfg->font->width = 16;
      cfg->font->height = 16;
    }
    if (ret == 3) {
      cfg->font->width = 18;
      cfg->font->height = 18;
    }

    if (ret == 4) {
      cfg->font->width = 20;
      cfg->font->height = 20;
    }
    change_ft_size(cfg->face, cfg->font->width, cfg->font->height);
  }
}

void parse_cmd(CONFIG *cfg, uint8_t *cmd, uint8_t cmdidx) {

  uint8_t ret;

  if (cmdidx > 1) {
    // ESC 2
    if (cmd[0] == ASCII_ESC && cmd[1] == 0x32) {
      cfg->line_space = cfg->font->height + 8;
      reset_cmd();
    }

    // ESC @
    if (cmd[0] == ASCII_ESC && cmd[1] == 0x40) {
      init_printer();
      reset_cmd();
    }
    // DC2 T  printer test page
    if (cmd[0] == ASCII_DC2 && cmd[1] == 0x54) {
      reset_cmd();
      printer_test(cfg);
    }
  }

  if (cmdidx > 2) {
    // ESC j n
    if (cmd[0] == ASCII_ESC && cmd[1] == 0x4a) {

      if (print_lines8(cfg,0,0) == 0) {
         print_lines8(NULL,cmd[2], cfg->orient);
      }
      reset_cmd();
    }
    // ESC d n
    if (cmd[0] == ASCII_ESC && cmd[1] == 0x64) {

      if (print_lines8(cfg,0,0) == 0) {
        print_lines8(NULL,cmd[2] * cfg->font->height, cfg->orient);
      }
      reset_cmd();
    }

    // ESC ! n
    if (cmd[0] == ASCII_ESC && cmd[1] == 0x21) {
      ret = cmd[2];
      if(ret == 0) {
         printer_set_font_mode(cfg,FONT_MODE_0);
         printer_set_font(cfg,0);
      }else if(ret == 1) {
         printer_set_font_mode(cfg,FONT_MODE_1);
         printer_set_font(cfg,0);
      }
      
      reset_cmd();
    }

    //GS ! n
    if(cmd[0] == ASCII_GS && cmd[1] == 0x21) {
       printer_set_font(cfg,cmd[2]);
       reset_cmd();
    }

    // ESC 3 n
    if (cmd[0] == ASCII_ESC && cmd[1] == 0x33) {
      cfg->line_space = cmd[2];
      reset_cmd();
    }

    // ESC v n
    if (cmd[0] == ASCII_ESC && cmd[1] == 0x76) {
      if (temperature() > 70) {
        ret |= 1 << 6;
      }
      if ((IsPaper() & NO_PAPER) > 0) {
        ret |= 1 << 2;
      }
      // 1<< 3 == power error

      cfg->printf(cfg, "%d", ret);
      reset_cmd();
      return;
    }
    // ESC a n
    if (cmd[0] == ASCII_ESC && cmd[1] == 0x61) {
      ret = cmd[2];
      if (ret == 0 || ret == 48) {
        cfg->align = ALIGN_LEFT;
      }
      if (ret == 1 || ret == 49) {
        cfg->align = ALIGN_CENTER;
      }
      if (ret == 2 || ret == 50) {
        cfg->align = ALIGN_RIGHT;
      }

      reset_cmd();
    }
    // ESC - n
    if (cmd[0] == ASCII_ESC && cmd[1] == 0x2d) {
      ret = cmd[2];
      if (ret == 0 || ret == 48) {
        cfg->under_line = 0;
      }
      if (ret == 1 || ret == 49) {
        cfg->under_line = 1;
      }
      if (ret == 2 || ret == 50) {
        cfg->under_line = 2;
      }

      reset_cmd();
    }

    // ESC SP n
    if (cmd[0] == ASCII_ESC && cmd[1] == 0x20) {
      ret = cmd[2];
      if (ret + cfg->margin.width < MAX_DOTS) {
        cfg->wordgap = ret;
      }
      reset_cmd();
      return;
    }

    // DC2 # n
    if (cmd[0] == ASCII_DC2 && cmd[1] == 0x23) {
      ret = cmd[2];
      cfg->density = ret;
      reset_cmd();
    }

    // GS V \0 or GS V \1
    if (cmd[0] == ASCII_GS && cmd[1] == 0x56) {

      ret = cmd[2];
      reset_cmd(); // When using parse_serial_stream function internally,
                   // reset_cmd() first

      print_cut_line(cfg);

      return;
    }

    // ESC V n
    if (cmd[0] == ASCII_ESC && cmd[1] == 0x56) {
      ret = cmd[2];
      if (ret == 0x00 || ret == 0x30) {
        cfg->degree = 0;
      }
      if (ret == 0x01 || ret == 0x31) {
        cfg->degree = 90;
      }
      if (ret == 0x02 || ret == 0x32) {
        cfg->degree = 180;
      }

      if (ret == 0x03 || ret == 0x33) {
        cfg->degree = 270;
      }
      printf("set printer degree, %d\n", cfg->degree);
      return;
    }
  }

  if (cmdidx > 3) {
    // GS L nL nH
    if (cmd[0] == ASCII_GS && cmd[1] == 0x4c) {
      uint16_t k;
      k = cmd[2] + cmd[3] * 256;
      if (k < MAX_DOTS - cfg->font->width) {
        cfg->margin.width = k;
      }

      reset_cmd();
    }
  }

  if (cmdidx > 4) {
    /*
    if(cmd[0] == ASCII_ESC && cmd[1] == 0x2a){
      if( cmd[2] == 0 || cmd[2] == 1){
        uint16_t k;
        k = cmd[3] + 256*cmd[4];
        if(k<= IMAGE_MAX){
          cfg->state = GET_IMAGE;
          cfg->img->num = k;
          cfg->img->idx = 0;
        }
      }

      reset_cmd();
    }
    */
  }

  if (cmdidx > 7) {
    // GS v 0 p wL wH hL hH d1…dk
    if (cmd[0] == ASCII_GS && cmd[1] == 118 && cmd[2] == 48) {
      uint16_t width = cmd[4] + cmd[5] * 256;
      uint16_t height = cmd[6] + cmd[7] * 256;
      uint16_t k;
      k = width * height;
      if (k <= IMAGE_MAX) {
        cfg->state = GET_IMAGE;
        cfg->img->num = k;
        cfg->img->idx = 0;
        cfg->img->width = width;
        cfg->img->need_print = 1;
      }
      // do not reset_cmd()
      cmd_idx = 0;
      ser_cache.idx = 0;
    }
    // GS v 1 p wL wH hL hH d1…dk
    if (cmd[0] == ASCII_GS && cmd[1] == 118 && cmd[2] == 49) {
      uint16_t width = cmd[4] + cmd[5] * 256;
      uint16_t height = cmd[6] + cmd[7] * 256;
      uint16_t k;
      k = width * height;
      if (k <= IMAGE_MAX) {
        cfg->state = GET_GRAY_IMAGE;
        cfg->img->num = k;
        cfg->img->idx = 0;
        cfg->img->width = width;
        cfg->img->need_print = 1;
      }
      // do not reset_cmd()
      cmd_idx = 0;
      ser_cache.idx = 0;
    }
  }
}

void parse_serial_stream(CONFIG *cfg, uint8_t input_ch) {
  uint16_t a;
  uint8_t bskip;

  if (cfg->state == GET_IMAGE) {
    cfg->img->cache[cfg->img->idx] = input_ch;
    cfg->img->idx++;
    if (cfg->img->idx >= cfg->img->num) { // image full
      if (cfg->img->need_print == 1) {
        print_image8(cfg);
      }
      reset_cmd();
      cfg->state = PRINT_STATE;
    }
  } else if (cfg->state == GET_GRAY_IMAGE) {
    cfg->img->cache[cfg->img->idx] = input_ch;
    cfg->img->idx++;
    if (cfg->img->idx >= cfg->img->num) { // image full
      if (cfg->img->need_print == 1) {
        print_gray_image8(cfg);
      }
      reset_cmd();
      cfg->state = PRINT_STATE;
    }
  } else if (cfg->state == ESC_STATE) {
    cmd[cmd_idx] = input_ch;
    cmd_idx++;
    if (cmd_idx < 10) {
      parse_cmd(cfg, cmd, cmd_idx);
    } else {
      reset_cmd();
    }
  } else { // PRINT_STATE
    switch (input_ch) {
    case ASCII_LF:
      if (ser_cache.idx == 0) {
       print_lines8(NULL,cfg->font->height, cfg->orient);
      }
      print_lines8(cfg,0,0);
      reset_cmd();
      break;
    case ASCII_FF:

      print_lines8(cfg,0,0);
      reset_cmd();
      break;
    case ASCII_DC2:
      cmd[cmd_idx] = input_ch;
      cfg->state = ESC_STATE;
      cmd_idx++;
      break;
    case ASCII_GS:
      cmd[cmd_idx] = input_ch;
      cfg->state = ESC_STATE;
      cmd_idx++;
      break;
    case ASCII_ESC:
      cmd[cmd_idx] = input_ch;
      cfg->state = ESC_STATE;
      cmd_idx++;
      break;
    default:
      if (input_ch < 128) {
        ser_cache.data[ser_cache.idx] = input_ch;
        ser_cache.idx++;
      } else { // utf8
        // 10xxxxxx bskip == 1
        bskip = get_slice_len(input_ch);

        if (bskip == 1) {
          // append this to int32_t [8:8:8:8] 0xffffffff 4294967295
          ser_cache.data[ser_cache.idx] |= input_ch
                                           << (8 * (ser_cache.utf8idx));
          if (ser_cache.utf8idx ==
              get_slice_len(ser_cache.data[ser_cache.idx] & 0xff) - 1) {
            ser_cache.idx++;
            ser_cache.utf8idx = 0; // next character
          } else {
            ser_cache.utf8idx++;
          }
        }

        if (bskip > 1) {
          ser_cache.utf8idx = 1;
          ser_cache.data[ser_cache.idx] = input_ch;
        }
      }
      // read utf8 codename
      //
      if (cfg->font->mode == FONT_MODE_1 && cfg->face != NULL) {

        a = get_serial_cache_font_width(&g_config);
        a += (ser_cache.idx) * 0 + g_config.margin.width;

      } else {
        a = (ser_cache.idx + 1) * current_font.width + (ser_cache.idx) * 0 +
            g_config.margin.width;
      }
      if (a >= MAX_DOTS) // got enough points to print
      {
        if (cfg->font->mode == FONT_MODE_1 && cfg->face != NULL ) {
          print_lines_ft(cfg,0,0);
        } else {
          print_lines8(cfg,0,0);
        }
        reset_cmd();
      }
      break;
    }
  }
}

/* Virtual serial port created by socat
  socat -d -d pty,link=/tmp/DEVTERM_PRINTER_OUT,raw,echo=0
  pty,link=/tmp/DEVTERM_PRINTER_IN,raw,echo=0
*/

int read_bat_cap(CONFIG *cfg) {
  long ret;
  char c[12];
  FILE *fptr;
  if ((fptr = fopen(BAT_CAP, "r")) == NULL) {
    PRINTF("Error! Battery File cannot be opened\n");
    // Program exits if the file pointer returns NULL.
    return -1;
  }

  fscanf(fptr, "%[^\n]", c);
  // printf("Data from the file:%s\n", c);
  fclose(fptr);

  ret = strtol(c, NULL, 10);

  return (int)ret;
}

int bat_cap_to_pts(CONFIG *cfg, int bat) {
  int pts;

  pts = (int)round((float)bat / 10.0) + 1;
  return pts;
}

void print_lowpower(CONFIG *cfg) {

  int i;
  char *msg = "Low Power,please charge";

  reset_cmd();

  printer_set_font(cfg, 4);

  for (i = 0; i < strlen(msg); i++) {
    parse_serial_stream(cfg, msg[i]);
  }
  parse_serial_stream(cfg, 10);
  reset_cmd();

  for (i = 0; i < strlen(msg); i++) {
    parse_serial_stream(cfg, msg[i]);
  }
  parse_serial_stream(cfg, 10);
  reset_cmd();

  print_lines8(NULL,128, cfg->orient);
  printer_set_font(cfg, 0);

  PRINTF("%s\n", msg);
}

int check_battery(CONFIG *cfg) {

  int bat_cap;

  bat_cap = 0;

  if (millis() - battery_chk_tm.time > 200) {

    bat_cap = read_bat_cap(cfg);

    if (bat_cap < 0) {
      cfg->max_pts = 1; // no battery ,so set to the slowest
      cfg->lock = 0;    // unlock printer anyway
      PRINTF("no battery,slowest printing\n");
    }

    if (bat_cap >= 0 && bat_cap <= BAT_THRESHOLD) {

      if (cfg->lock == 0) {
        print_lowpower(cfg);
      }
      cfg->lock = 1;
      PRINTF("printer locked\n");
      reset_cmd(); // clear all serial_cache
    } else {

      cfg->max_pts = bat_cap_to_pts(cfg, bat_cap);

      cfg->lock = 0;
    }

    battery_chk_tm.time = millis();
  }

  if (cfg->lock == 1) {
    reset_cmd();
  }

  return 0;
}

#define FIFO_FILE "/tmp/DEVTERM_PRINTER_OUT"
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
int main(int argc, char **argv) {

  setup();
  loop();
}

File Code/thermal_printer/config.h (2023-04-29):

#ifndef CONFIG_H
#define CONFIG_H

// clang-format off
#include <freetype2/ft2build.h>
#include <freetype/freetype.h>
// clang-format on
/// raspberry pi CM3
#ifdef CM4
// make CFLAGS=-DCM4=1
#define BCM_GPIO_28 18
#define BCM_GPIO_29 19
#define BCM_GPIO_30 20
#define BCM_GPIO_31 21
#define BCM_GPIO_32 14
#define BCM_GPIO_33 15
#define BCM_GPIO_34 24
#define BCM_GPIO_35 25
#define BCM_GPIO_36 26
#define BCM_GPIO_37 27
#define BCM_GPIO_38 6
#define BCM_GPIO_39 7
#define BCM_GPIO_40 16
#define BCM_GPIO_41 17
#define BCM_GPIO_43 23
#else
#define BCM_GPIO_28 28
#define BCM_GPIO_29 29
#define BCM_GPIO_30 30
#define BCM_GPIO_31 31
#define BCM_GPIO_32 32
#define BCM_GPIO_33 33
#define BCM_GPIO_34 34
#define BCM_GPIO_35 35
#define BCM_GPIO_36 36
#define BCM_GPIO_37 37
#define BCM_GPIO_38 38
#define BCM_GPIO_39 39
#define BCM_GPIO_40 40
#define BCM_GPIO_41 41
#define BCM_GPIO_42 42
#define BCM_GPIO_43 43
#define BCM_GPIO_44 44
#define BCM_GPIO_45 45
#endif
// PA8-12 UART1
//#define SPI1_NSS_PIN PA4    //SPI_1 Chip Select pin is PA4. //no use in
//DevTerm

#define VH_PIN BCM_GPIO_40 // ENABLE_VH required,PRT_EN

#define LATCH_PIN BCM_GPIO_36 // 18
#define PEM_PIN BCM_GPIO_34   // 1 [PS,PAPER]

/*
#define PEM_CTL_PIN BCM_GPIO_32 //3 VPS
#define ENABLE_PEM digitalWrite(PEM_CTL_PIN,HIGH)
#define DISABLE_PEM digitalWrite(PEM_CTL_PIN,LOW)
*/
// DevTerm no VPS IO
//#define PEM_CTL_PIN
#define ENABLE_PEM
#define DISABLE_PEM

// https://www.raspberrypi.org/documentation/hardware/raspberrypi/spi/README.md
// enable SPI0 ALT0 in CM3 first
// in /boot/config.txt
// dtparam=spi=on
// dtoverlay=spi-gpio35-39
// then we can see GPIO38 GPIO39 in ALT0 Mode by `gpio readall`

#define MOSI_PIN BCM_GPIO_38
#define CLK_PIN BCM_GPIO_39

/**
 *@brief STB_NUMBER stand for STROBE NUMBER of lines, which means how many lines
 *        are going to be activated
 **/
#define STB_NUMBER 1

#define STB1_PIN BCM_GPIO_37 // 13
#define STB2_PIN STB1_PIN
#define STB3_PIN STB1_PIN
#define STB4_PIN STB1_PIN
#define STB5_PIN STB1_PIN
#define STB6_PIN STB1_PIN

#define PH1_PIN BCM_GPIO_28
#define PH2_PIN BCM_GPIO_29
#define PH3_PIN BCM_GPIO_30
#define PH4_PIN BCM_GPIO_31

/// 0 1 3 2 mine
#define PA_PIN PH1_PIN  //
#define PNA_PIN PH2_PIN //
#define PB_PIN PH3_PIN  //
#define PNB_PIN PH4_PIN //

//#define ENABLE1_PIN  PA13
//#define ENABLE2_PIN  PA14

#define THERMISTORPIN BCM_GPIO_35 // ADC,14

#define MOTOR_ENABLE1
#define MOTOR_ENABLE2

#define MOTOR_DISABLE1
#define MOTOR_DISABLE2

#define ENABLE_VH digitalWrite(VH_PIN, HIGH)
#define DISABLE_VH digitalWrite(VH_PIN, LOW)
#define READ_VH digitalRead(VH_PIN)

#define LATCH_ENABLE digitalWrite(LATCH_PIN, LOW)
#define LATCH_DISABLE digitalWrite(LATCH_PIN, HIGH)

#define ASK4PAPER digitalRead(PEM_PIN)

#define ERROR_FEED_PITCH ((uint8_t)0x01)
#define IS_PAPER 0x00
#define NO_PAPER 0x01
#define HOT_PRINTER 0x02

#define FORWARD 0x01
#define BACKWARD 0x00

#define HOT 64

#define BCoefficent 3950
#define RthNominal 30000
#define TempNominal 25
#define ADCResolution 1024
#define SeriesResistor 30000
#define NumSamples 1

#define KELVIN 1
#define CELSIUS 0

#define ADC_FILE_PAT "/tmp/devterm_adc"

#define HEAT_TIME 100 // heat time + (0-f)*46

#define BAT_CAP "/sys/class/power_supply/axp20x-battery/capacity"
#define BAT_THRESHOLD 14 // %14 battery = low power

#define int16 uint16_t
#define int8 uint8_t

#define asciistart ((uint8_t)'A')
#define netxcharacter ((uint8_t)24)
#define Fontrows ((uint8_t)24)
#define FontColums ((uint8_t)16)

#define nextcharactercolum ((uint8_t)Fontrows / 8) // = 3

#define ASCII_TAB '\t' // Horizontal tab
#define ASCII_LF '\n'  // Line feed,10
#define ASCII_FF '\f'  // Form feed
#define ASCII_CR '\r'  // Carriage return
#define ASCII_EOT 4    // End of Transmission
#define ASCII_DLE 16   // Data Link Escape
#define ASCII_DC2 18   // Device control 2 //0x12
#define ASCII_ESC 27   // Escape //0x1b
#define ASCII_FS 28    // Field separator//0x1c
#define ASCII_GS 29    // Group separator //0x1d

#define PRINT_STATE 0
#define ESC_STATE 1
#define GET_IMAGE 2
#define GET_GRAY_IMAGE 3

#define ALIGN_LEFT 0
#define ALIGN_CENTER 1
#define ALIGN_RIGHT 2

#define IMAGE_MAX (9224*64)

#define BITS8 8

#define MAX_DOTS 384
#define PRINTER_BITS MAX_DOTS
#define MAXPIXELS 48

#ifdef MTP03
#define MAX_DOTS 576
#define PRINTER_BITS MAX_DOTS
#define MAXPIXELS 72
#endif

#define FONT_MODE_0 0 // Internal
#define FONT_MODE_1 1 // External

// extract bits
#define LAST(k, n) ((k) & ((1 << (n)) - 1))
#define MID(k, m, n) LAST((k) >> (m), ((n) - (m)))

typedef struct _Margin {
  uint16_t width;
  uint8_t esgs;
} Margin;

typedef struct _FONT {

  uint8_t width; // in bits
  uint8_t height;
  uint8_t mode; // 0 internal pcf font array,1 external ttf font file
  const uint8_t *data;
  char *file;
} FONT;
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

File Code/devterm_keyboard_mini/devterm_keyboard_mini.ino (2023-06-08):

#include "keyboard.h"
#include "keys.h"
#include "trackball.h"
#include "devterm.h"
#include "tickwaiter.h"

#include <USBComposite.h>

#define SER_NUM_STR "20230307"

USBHID HID;
DEVTERM dev_term;

const uint8_t reportDescription[] = { 
   HID_CONSUMER_REPORT_DESCRIPTOR(),
   HID_KEYBOARD_REPORT_DESCRIPTOR(),
   HID_JOYSTICK_REPORT_DESCRIPTOR(),
   HID_MOUSE_REPORT_DESCRIPTOR()
};

static const uint32_t LOOP_INTERVAL_MS = 0;
static TickWaiter<LOOP_INTERVAL_MS> waiter;

HardwareTimer timer(1);
//HardwareTimer ctrl_timer(4);

void setup() {
  USBComposite.setManufacturerString("ClockworkPI");
  USBComposite.setProductString("uConsole");
  USBComposite.setSerialString(SER_NUM_STR);
  
  dev_term.Keyboard = new HIDKeyboard(HID);
  dev_term.Joystick = new HIDJoystick(HID);
  dev_term.Mouse    = new HIDMouse(HID);
  dev_term.Consumer = new HIDConsumer(HID);

  dev_term.Keyboard->setAdjustForHostCapsLock(false);

  dev_term.state = new State();

  dev_term.Keyboard_state.layer = 0;
  dev_term.Keyboard_state.prev_layer = 0;
  dev_term.Keyboard_state.fn_on = 0;
  dev_term.Keyboard_state.sf_on = 0;
  
  //dev_term.Keyboard_state.shift = 0;
  dev_term.Keyboard_state.backlight = 0;
  dev_term.Keyboard_state.lock = 0;
  
  dev_term.Keyboard_state.ctrl.lock = 0;
  dev_term.Keyboard_state.ctrl.time = 0;
  dev_term.Keyboard_state.ctrl.begin = 0;

  dev_term.Keyboard_state.shift.lock = 0;
  dev_term.Keyboard_state.shift.time = 0;
  dev_term.Keyboard_state.shift.begin = 0;

  dev_term.Keyboard_state.alt.lock = 0;
  dev_term.Keyboard_state.alt.time = 0;
  dev_term.Keyboard_state.alt.begin = 0;
      
  dev_term.Keyboard_state.fn.lock = 0;
  dev_term.Keyboard_state.fn.time = 0;
  dev_term.Keyboard_state.fn.begin = 0;  
  
  dev_term._Serial = new  USBCompositeSerial;
  
  HID.begin(*dev_term._Serial,reportDescription, sizeof(reportDescription));

  while(!USBComposite);//wait until usb port been plugged in to PC
  

  keyboard_init(&dev_term);
  keys_init(&dev_term);
  trackball_init(&dev_term);
  
  //dev_term._Serial->println("setup done");

  pinMode(PD2,INPUT);// switch 2 in back 

  timer.setPeriod(KEYBOARD_LED_PWM_PERIOD);
  timer.resume();

  /*
  ctrl_timer.setPeriod(20*1000);
  ctrl_timer.attachInterrupt(1,ctrl_timer_handler);
  ctrl_timer.refresh();
  ctrl_timer.resume();
  */
  pinMode(PA8,PWM);
  pwmWrite(PA8,0);

  
  delay(1000);
}

#define LOCK_TIME 50

//DO NOT USE dev_term._Serial->println(""); in timer interrupt function,will block 
void check_keyboard_lock(KEYBOARD_LOCK*lock){
   if( lock->begin >0) {
    lock->time++;

    if( lock->time>=LOCK_TIME && lock->time<200){
      lock->lock = 1;
    }
    
    if( lock->time > 200){
     if(lock->begin != _FN_KEY) {
      	dev_term.Keyboard->release(lock->begin);
      }
      lock->time = 0;
      lock->lock = 0;
      lock->begin = 0;
    }
  } 
}

#define LOCK_TIME 50
void ctrl_timer_handler(void) {
  
  check_keyboard_lock(&dev_term.Keyboard_state.ctrl);
  check_keyboard_lock(&dev_term.Keyboard_state.shift);
  check_keyboard_lock(&dev_term.Keyboard_state.alt);
  check_keyboard_lock(&dev_term.Keyboard_state.fn);

}

void loop() {
  dev_term.delta = waiter.waitForNextTick();
  dev_term.state->tick(dev_term.delta);
  
  trackball_task(&dev_term);
  
  keys_task(&dev_term); //keys above keyboard
  keyboard_task(&dev_term);
  

}

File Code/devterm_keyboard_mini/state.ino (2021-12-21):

#include <cassert>
#include <algorithm>
#include <limits>

#include "state.h"

State::State()
  : fn(false),
    middleClick(false),
    scrolled(false)
{
}

void State::tick(millis_t delta)
{
  middleClickTimeout.updateTime(delta);
}
void State::setScrolled() {
  if(middleClick==true){
    scrolled = true;
  }
}

bool State::getScrolled() {
  return scrolled;
}

void State::pressMiddleClick() {
  middleClick = true;
  middleClickTimeout.reset();
}

bool State::releaseMiddleClick() {
  middleClick = false;
  scrolled = false;
  const auto timeout = middleClickTimeout.get();
  return !timeout;
}

TrackballMode State::moveTrackball() {
  middleClickTimeout.expire();
  if (middleClick) {
    return TrackballMode::Wheel;
  } else {
    return TrackballMode::Mouse;
  }
}

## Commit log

2021-03-29 add schematic pdfs and firmware code
2021-04-18 thermal_printer,temperature(),WringPi has no INPUT_ANALOG,now ASK4PAPER==HIGH issue left
    [printer.c]
2021-04-24 thermal_printer bug, feed_pitch1 should not use [FOR/BACK]WORD directly
    [devterm_thermal_printer.c, printer.c]
2021-05-04 bug fix,scan_keys used wrong variable of debouncing, add KEY_DEB struct
    [keyboard.ino, keymaps.ino, keys.ino]
2021-05-13 add CONFIG printf
2021-05-13 add PRINTF, StandardOutput for debugging
2021-05-14 edit devterm-printer.service
2021-05-16 tab to be two space in PRINT_STATE
2021-05-18 bug fix,increase delay in matrix/keys scan process
    fn+arrow keys to be page up/dn, home end
    bottom mouse middle key fixed
    shift caps lock bug fix
    now there are only two layers in keyboard
    remove bug code,layers, use USBComposite_stm32f1's modifiers and setAdjustForHostCapsLock to do shift / caps lock job
    [devterm_keyboard.ino, keyboard.ino, keymaps.ino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]
2021-05-22 devterm_keyboard,use switch 2 to switch the joystick to be the GameShell mode
2021-05-27 minor mod for trackball
    add read_adc to read temperature for thermal_printer
2021-05-28 add glob to find i2c adc device path
2021-05-28 decrease HEAT_TIME
2021-05-28 change max print pts with battery level
2021-05-29 add lock mode for thermal printer when battery is low
2021-07-07 Add DevTerm Assembly Guidelines
2021-07-12 devterm thermal printer readme
2021-07-13 remove self test grid printing
2021-08-11 map adc node to /tmp/devterm_adc
2021-09-14 add Keyboard,Trackball Schematic
2021-09-14 add Battery Schematic
2021-09-18 add thermal printer Spec
2021-10-06 add devterm-a06-gearbox
2021-10-06 fix typo in devterm-a06-gearbox
2021-10-12 fix gear level 4 bug
2021-10-14 Refactor the A06 gearbox to make it easier to tune
2021-10-14 Add a gear for "maximum performance, maximum power (usage)"
2021-10-15 devterm-a06-gearbox bug fix
2021-12-08 add A04 gearbox
2021-12-17 add wheel scroll of trackball
2021-12-17 add trackball schematic
2021-12-17 update fix trackball middle scroll issue
    [keymaps.ino]
2021-12-19 sudo stm32flash -r devterm.kbd.0.2_48mhz.bin -S 0x08000000:65536 /dev/ttyUSB0 srec_cat devterm.kbd.0.2_48mhz.bin -Binary -offset 0x08000000 -output devterm.kbd.0.2_48mhz.hex -Intel
    new keyboard firmware based on https://github.com/foriequal0/devterm_keyboard improvement for trackball
    https://forum.clockworkpi.com/t/ive-rewritten-devterm-keyboard-trackball-firmware/7671
2021-12-21 fix conflicts of scrolling and mid mouse key
    [keymaps.ino, state.ino, trackball.ino]
2021-12-29 update keyboard and A04/devterm-a04-gearbox
2021-12-30 update A04/devterm-a04-gearbox
2022-01-06 DIY a Graphene Heat Sink for DevTerm
2022-01-13 PCB Outline in DXF
    [PCB_Outline_DevTerm_jogball.dxf, PCB_Outline_DevTerm_keyboard.dxf]
2022-02-10 correctly read utf8 string into int32_t
    [devterm_thermal_printer.c]
2022-02-12 add print_lines_ft for freetype
2022-02-20 printing out cjk ok,but not perfect,need more advanced space between here and there
2022-02-24 add wiringPi a04 code
2022-02-27 cjk printing done,but still has bug ,will lose top line of bitmap occasionally
    [printer.c]
2022-02-28 bug fix,first line disappear fixed,next is clear extra points that appear incorrectly at bottom,and word-to-word alignment
    [printer.c]
2022-03-06 ttf cjk printing beta tested
2022-03-06 user bbox_height to be the max size of rows,left with too wide linesheight problem
    [printer.c]
2022-03-11 cjk with printer_set_font
2022-03-11 devterm-printer.service with EnvironmentFile=/usr/local/etc/devterm-printer
2022-03-11 thermal printer cjk readme
2022-03-17 Esc ! n to switch mode ,GS ! n to set font size
2022-04-09 [Update] Refactor devterm-a06-gearbox and fix gpu governor message.
2022-05-21 add ENABLE_VH in print_lines_ft
2022-05-22 update devterm R01 wiringPi patch
2022-05-24 add accelerate for thermal printer
2022-05-31 add devterm-wiringpi-cpi to apt install. missing gpio-tool under Armbian.
2022-06-08 add R01 schematic
2022-06-10 New fan_loop function which starts the fan when the temperature reaches the threshold and doesn't stop it until the temperatue is a bit lower than the threshold. Also lowered the threshold a bit.
2022-06-10 Changed the an control so that it considers every thermal zone separately, rather than just kind of wrongly lumping them all together and possibly getting the temperature values a bit confused. Added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
2022-06-22 thermal_printer bug fix,print_lines8 cfg null check logic bug
    [printer.c]
2022-06-29 add cm4 wiringpi patch
2022-07-28 devterm-printer.service add Restart=on-failure
2022-08-21 add hacked keyboard stm32duino bootloader files
2022-09-20 DFU Mode bug fix
    [devterm_keyboard.ino]
2022-09-20 undo dfu mode fix code
    [devterm_keyboard.ino]
2022-10-12 mini keyboard bug fix
    [devterm_keyboard_mini.ino, keyboard.ino, keymaps.ino]
2022-10-13 mini keyboard pause timer when duty cycle is 0
2023-04-01 bug fix,tested on real uConsole
    [devterm_keyboard_mini.ino, keymaps.ino, trackball.h]
2023-04-10 wiringPi: allow external pins in pinMode, digitalRead, digitalWrite
2023-04-14 switch order of DELETE and ENTER key
2023-04-16 Add command for printing 4 shades of grayscale image.
    It works in a similar way as a monochrome print, but with few differences:
    1. User needs to send 3 rows of color bitstrings for each image row.
    2. Printer will stay in place while printing all 3 non-white 'colors',
    it will feed the paper each third line.
    3. User must multiply height by 3.
    4. Command is different: cmd[0] == ASCII_GS && cmd[1] == 118 && cmd[2] == 49
    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
2023-06-07 make trackball button press became middle mouse key
2023-06-28 add cm4 Adapter schematic
2023-07-14 fix keyboard fn bug
    [keymaps.ino]
2023-08-28 update readme,add v5 mainboard schematic
2023-11-27 update thermal printer README DC2 # n
2024-05-26 Fix battery charge current in devicetree overlay
2024-08-30 Add RPI CM4 to CPI v3.14 Adapter gerber files
